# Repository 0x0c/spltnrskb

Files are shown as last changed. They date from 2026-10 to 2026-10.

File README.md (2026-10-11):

# nrsk 分割キーボード v2（基板と筐体）

KLE レイアウト（`kle/left.json`、`kle/right.json`）から生成した、左右分割・有線接続のキーボード基板です。
KiCad 10 のプロジェクト（回路図と配線済み基板）、製造用ガーバー、BOM、QMK ファームウェア設定を含みます。筐体のデータ（アクリルのレーザーカット用 DXF/SVG と 3D プリント用 STL）も入っています。

v2 では Pro Micro などのマイコンボードをやめ、RP2040 と QSPI Flash、USB-C コネクタなどを基板に直接実装しました。
マイコンボード用に設けていた内側の帯（約 20 mm）がなくなり、基板はキー領域とほぼ同じ大きさになっています。

| 項目 | 内容 |
| --- | --- |
| キー数 | 左 44 + 右 48 = 92 |
| マイコン | RP2040（QFN-56、12 MHz 水晶、I/O 3.3 V）と 16 MB の QSPI Flash W25Q128JV を左右に 1 組ずつ、裏面に直接実装 |
| USB | USB-C（USB 2.0）を左右それぞれに搭載 |
| 左右接続 | TRRS 3.5 mm（4 極ケーブル）、QMK の PIO シリアル（半二重、1 本の信号線）と 5 V 給電 |
| スイッチ | Cherry MX 互換、Kailh MX ホットスワップソケット（裏面） |
| 基板 | 2 層、左 172.6 × 126.3 mm、右 199.6 × 126.3 mm（キー配列の外周から 3 mm を基本に、上端を 6 mm、内側を左 9.4 mm・右 12.6 mm 広げて OLED・USB-C・TRRS・マイコンの場所を確保）、四隅は半径 4 mm の角丸、M2 取付穴 × 8（片側あたり）、表裏とも GND のベタ（約 5 mm 間隔のビアで表裏をつなぐ） |
| 筐体 | 左 189.6 × 143.3 mm、右 216.6 × 143.3 mm、高さ 15.6 mm（3D プリント版）／ 16.5 mm（アクリル版）、いずれもプレート上面まで |
| 外観 | プレートは透明アクリル 1.5 mm、アクリル版の枠と底板はマットクリア 3 mm。プレートは外周の切り欠きなし。USB-C と TRRS の穴はコネクタの外形ぴったり（基板の舌で差込口を外面の 0.8 mm 内側まで出している）。3D プリントのトレイは外周の角をフィレット加工（B のプレートも上面の外周に半径 1 mm の R） |
| 表示 | 0.91 インチ OLED（128×32）を左右に 1 枚ずつ、プレートと面一のハーフミラーアクリルのカバー付き。高さは増えない |
| ホイール | 左上と右上の角にサムホイール（ロータリーエンコーダー Alps EC05E1220401 で読み取り、1 回転 12 クリック）。高さは増えない |
| 3D ビューア | http://www.0x0c.me/spltnrskb/ 、組み立てガイドは http://www.0x0c.me/spltnrskb/assembly.html （GitHub Pages、`main` への Push で自動更新） |

基板の表と裏です（KiCad の 3D 表示）。裏面は裏から見た向きなので、左右が反転して見えます。

| | 左 | 右 |
| --- | --- | --- |
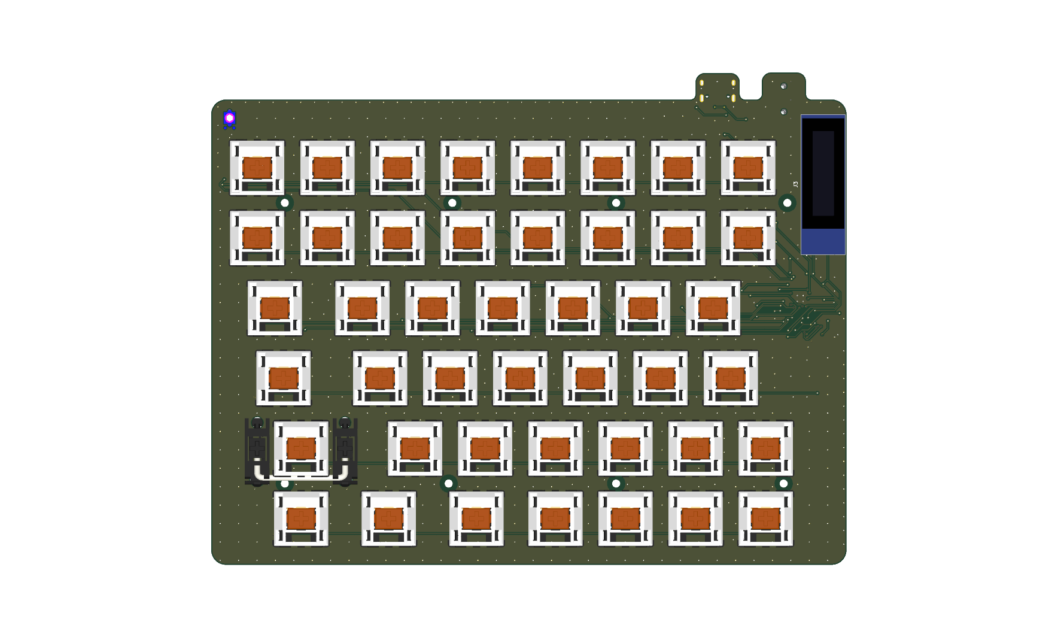
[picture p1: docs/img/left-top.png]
左基板の表
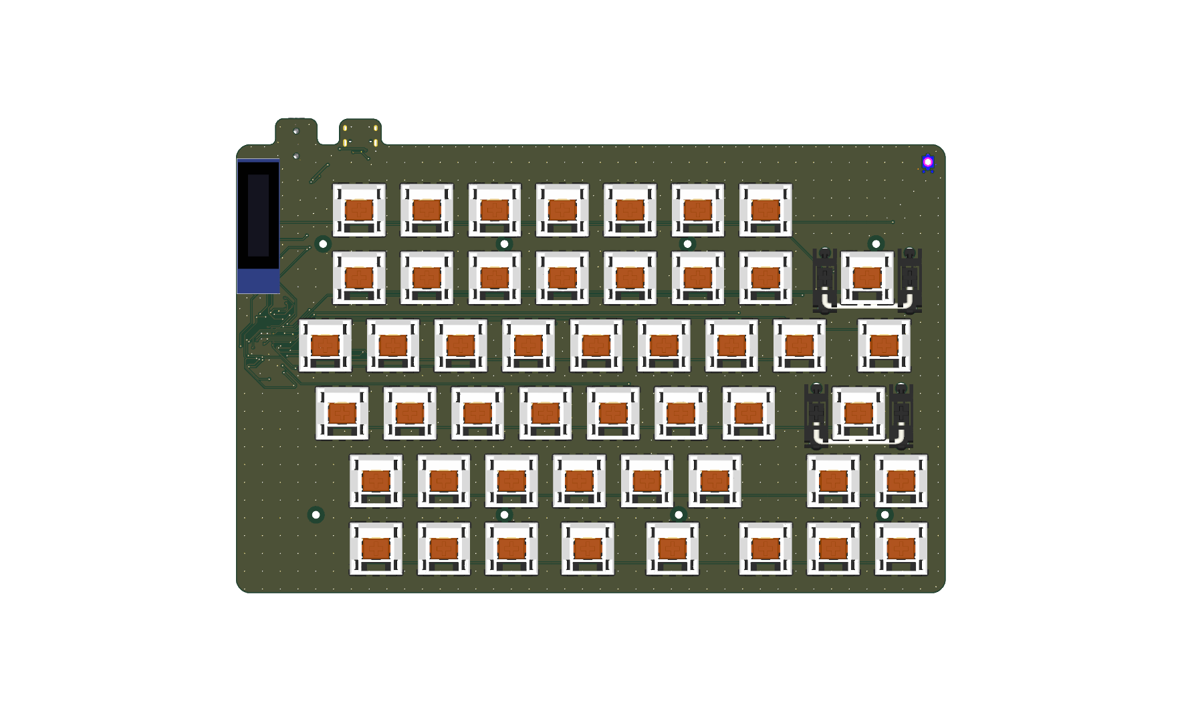
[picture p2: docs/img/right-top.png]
右基板の表
| 表 |  |  |
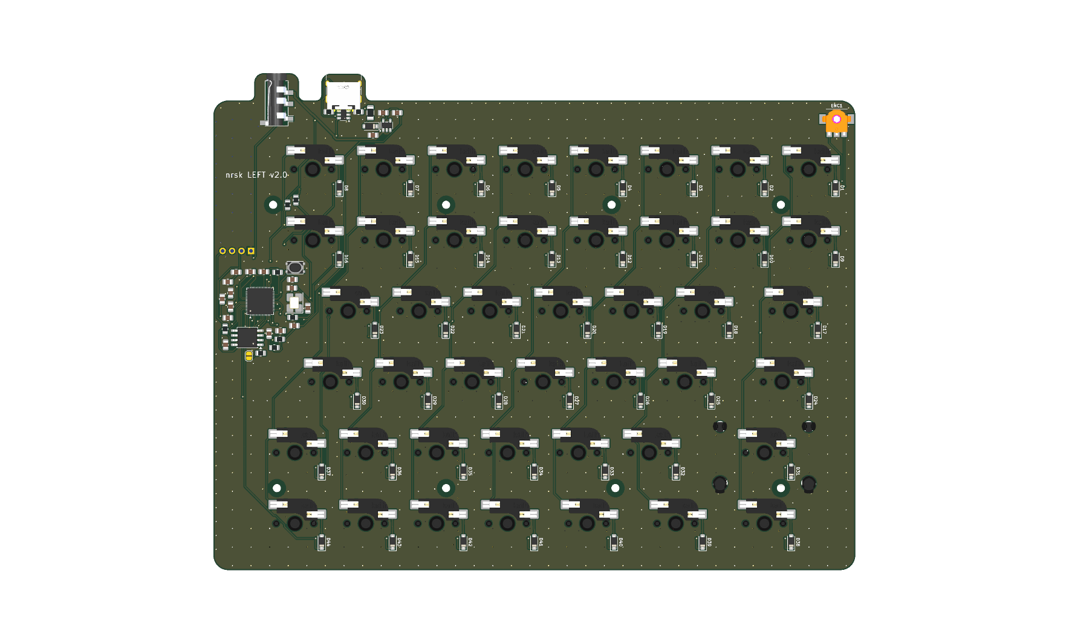
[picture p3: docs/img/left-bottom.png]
左基板の裏
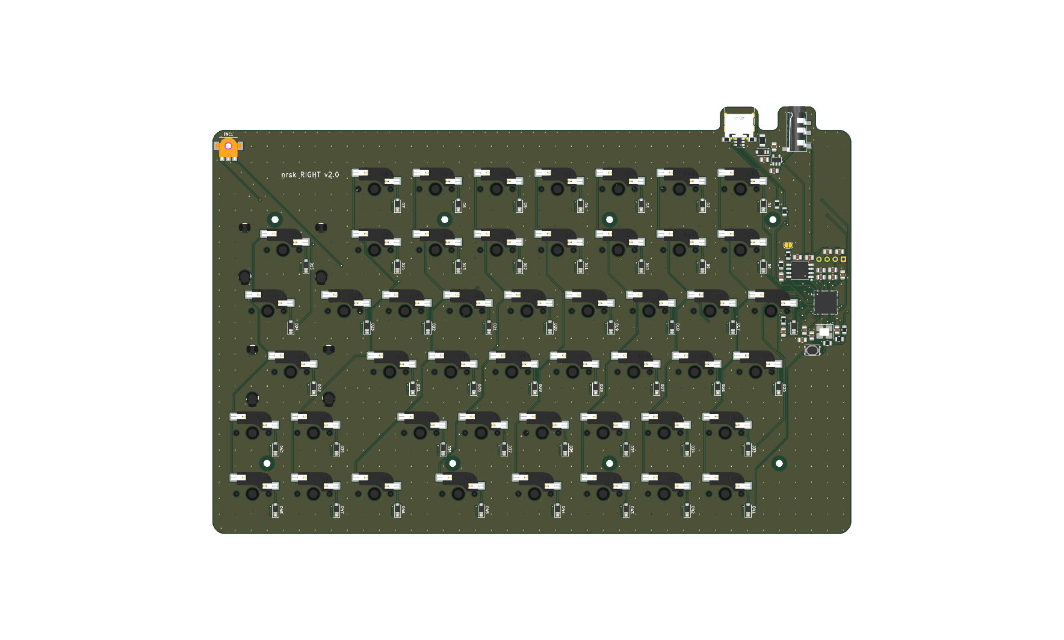
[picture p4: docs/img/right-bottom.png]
右基板の裏
| 裏 |  |  |

完成イメージ（Blender でレンダリング）です。筐体は 2 つの 3D プリント版を採用しています。左が A（3D プリントのトレイ + 透明アクリルのプレート）、右が B（プレートも 3D プリント）です。A はプレートを上からスリムヘッドの小ねじで、B は底からネジで留めます（B の上面にはネジが見えません）。

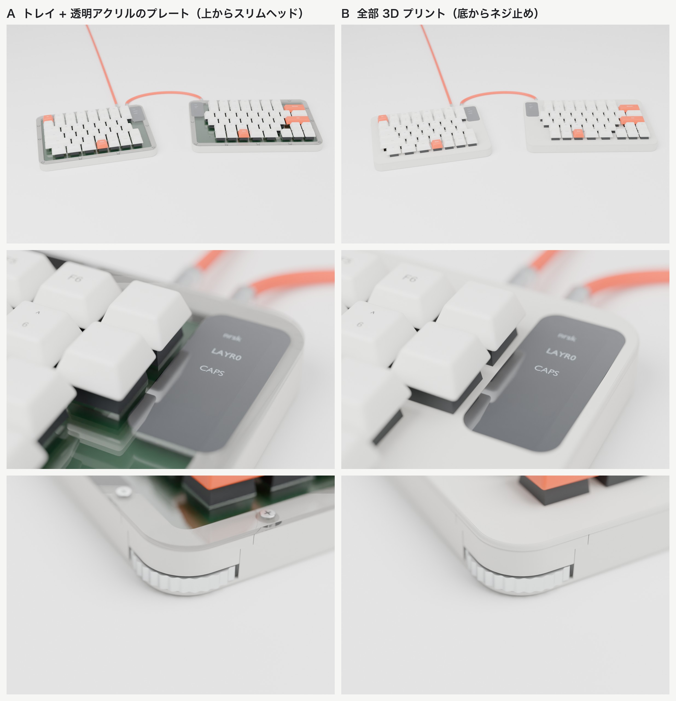
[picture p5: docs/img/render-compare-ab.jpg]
A と B の比較


## 回路

各半分に同じ回路が載っています。Raspberry Pi の RP2040 設計ガイド（Hardware design with RP2040）の最小構成に、保護部品を加えた構成です。

| 機能 | 部品 |
| --- | --- |
| QSPI Flash | W25Q128JVS（16 MB、SOIC-8 208 mil）、0.1 µF |
| クロック | 12 MHz 水晶（3225）、15 pF × 2、XOUT に 1 kΩ 直列 |
| 電源 | VCC（5 V）→ LDO AP2112K-3.3（入出力 1 µF）→ 3V3。コアの 1.1 V は RP2040 内蔵レギュレータ（VREG_VIN／VREG_VOUT に 1 µF） |
| 電源のパスコン | IOVDD × 6、DVDD × 2、USB_VDD、ADC_AVDD にそれぞれ 0.1 µF、3V3 に 10 µF |
| USB | 27 Ω × 2（D+/D−）、CC 用 5.1 kΩ × 2（USB-C のデバイス認識用）、ESD 保護 USBLC6-2SC6 |
| 電源経路 | VBUS → ポリスイッチ 500 mA → ショットキーダイオード B5819W → VCC（5 V、TRRS で反対側にも給電） |
| リセットと書き込み | RUN を 10 kΩ でプルアップしたリセットスイッチ（裏面）。BOOTSEL は QSPI_SS から 1 kΩ を通したはんだジャンパー |
| 左右判定 | GP0 を 10 kΩ で左は 3V3、右は GND に接続 |

- ショットキーダイオードは逆流を防ぎます。TRRS で給電されている側の USB-C の VBUS には電圧が出ないので、両方の USB を挿してもホスト側に電流が逆流しません。USB を挿していない側が自分をマスタだと誤判定することもありません。
- RP2040 はブートローダーを ROM に持っています。Flash が空のときは USB を挿すだけで `RPI-RP2` ドライブとして見え、UF2 ファイルをコピーすれば書き込めます。一度 QMK を書き込んだあとは、リセットスイッチを素早く 2 回押すと同じ書き込みモードに入ります。ISP 書き込み器は必要ありません。
- OLED は 3.3 V で動かします。サムホイールのエンコーダーは、A 相と B 相を RP2040 の内蔵プルアップで読み、共通端子を GND につないでいます。

### マルチプレクサは不要

片側のマトリックスは 6 行 × 8 列で、使う GPIO は 14 本です。
RP2040 の GPIO は 30 本あるので、シリアル通信 1 本、左右判定 1 本、I2C 2 本、エンコーダー 2 本を足しても十分に足ります。
右側の `\` キーは、配線上は行 0 の列 7 に割り当てて、左右とも 6 × 8 のマトリックスにそろえています（QMK の分割キーボードは左右で同じ列数を前提とするため）。

### ピン割り当て（左右共通）

| 用途 | GPIO |
| --- | --- |
| ROW0〜ROW5 | GP4〜GP9 |
| COL0〜COL7 | GP10〜GP14、GP16〜GP18（GP15 は QFN の角で配線しにくいため使わない） |
| I2C1（OLED） | SDA = GP2、SCL = GP3 |
| サムホイールのエンコーダー | A 相 = GP19、B 相 = GP20（共通端子は GND） |
| 左右間データ | GP1、TRRS の Tip |
| 左右判定 | GP0 |
| 予備 | GP15、GP21〜GP29 |

TRRS の配線は Tip = DATA、Ring2 = VCC（5 V）、Sleeve = GND で、Ring1 は未接続です。

## 配置

- 表面: スイッチだけです。スイッチプレートより上に出る部品はありません。
- 裏面: ホットスワップソケット、ダイオード、RP2040、Flash、LDO などの周辺部品、リセットスイッチ、BOOTSEL パッド、USB-C、TRRS。
- USB-C と TRRS はどちらも奥の辺（上端）に置き、ケーブルを後ろへ出します。TRRS は内側の角寄り（OLED の上）、USB-C はその 18 mm 外側です。どちらも基板の外形を幅 12 mm の舌として壁の中まで伸ばし、舌の先端へコネクタを載せています。差込口はケースの外面から 0.8 mm 内側です。舌の先端の角は半径 2.5 mm、付け根は半径 1.5 mm の R を付けてあり、基板単体で持っても角が手に刺さりません。マイコンはコネクタの下の裏面にあります。
- 基板と筐体は、左右それぞれのキー配列にぴったり合わせた大きさです（左は OLED の分だけ内側を広げています）。マイコンは裏面に置いています。
- 2 u 以上のキー（左 Shift 2.25 u、右 Backspace 2 u、右 Enter 2.25 u）には PCB マウント型スタビライザの穴があります。
- 配線ルールは信号線 0.2 mm、電源線 0.4 mm、クリアランス 0.2 mm、ビア 0.6/0.3 mm です。最小配線幅は 0.15 mm で、USB-C の細いピンに入る部分だけで使っています。JLCPCB などの標準仕様（最小 0.127 mm）で製造できます。
- マイコン周りの部品番号はシルクに収まらないため、Fab 層に入れています。半田付けには `fab/<side>/nrsk-<side>-assembly-back.pdf`（裏面の実装図、左右反転済み）を使ってください。配線の確認には `fab/<side>/nrsk-<side>-copper.pdf` を使えます（1 ページ目が表面 F.Cu、2 ページ目が裏面 B.Cu で、どちらも外形付き）。

## サムホイール（角のダイヤル）

左半分の左上、右半分の右上の角に、親指でなぞって回すサムホイールを付けています。

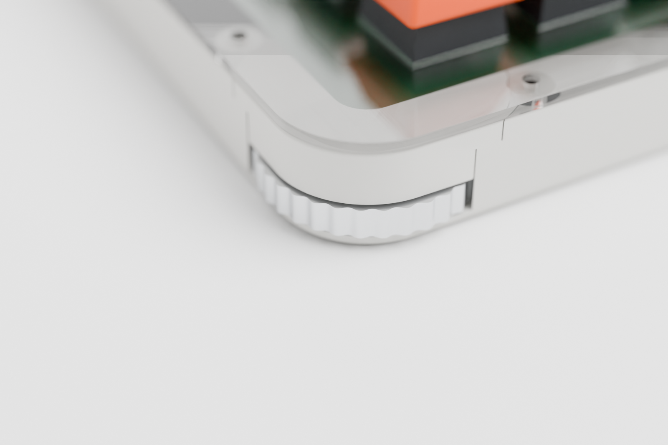
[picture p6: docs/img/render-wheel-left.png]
左のサムホイール


- 形: 直径 29.2 mm、厚さ 4.1 mm のホイールで、外周に 32 山の丸い歯（深さ 0.5 mm）があります。歯は指のすべり止めです。角の丸みと同心に置いていて、縁が角から約 3.5 mm、両側面から約 1 mm 出ます。
- 位置: 基板と底のすき間（7 mm）に水平に寝かせています。壁の下側だけを切り欠くので、プレートと壁の上部は切れ目がありません。キーボードの高さも変わりません。
- 検出: 基板裏面のホイールの中心の真上に、中空シャフトのロータリーエンコーダー Alps EC05E1220401 を下向きに付けています。ホイール上面の六角ピン（対辺 1.66 mm）が、エンコーダーの六角穴（対辺 1.72 mm）に 2 mm 入って回転部を回します。エンコーダーの下面に当たらないよう、ホイール上面の中心（半径 6 mm）を 0.4 mm 下げています。基板には、回転部の下に 3 mm 角の穴があります。
- クリック: エンコーダーが内蔵するクリックを使い、1 回転 12 クリック（30° ごと）です。1 クリックで A 相と B 相がちょうど 1 周期進むので、クリックとファームウェアの 1 ステップは部品の中で一致しています。
- 軸: 3D プリント版はトレイの床から立てた軸（直径 3.6 mm）、アクリル版は底板の下から通す M3 ネジを軸にします。ホイールの下面には軸穴（直径 4 mm × 深さ 2 mm）があります。親指で押す横向きの力はこの軸で受け、エンコーダーには回転だけを伝えます。軸と軸穴の間に半径方向で 0.2 mm 以上のすき間を設けて、基板とケースの位置ずれでホイールがこじれないようにしています。
- 組み立て: 3D プリント版で基板をトンネルへ滑り込ませるとき、エンコーダーの下面は六角ピンの先端の約 0.3 mm 上を通ります。ホイールのある角を少し持ち上げて滑らせてください。基板を下ろすときは、ホイールの縁を指で少し回すと、ピンがエンコーダーの穴に入ります。
- 左の Esc キー: エンコーダーと Esc のホットスワップソケットが重ならないよう、基板の上端を 1 mm 余分に延ばしてホイールを上へずらしています。そのため、すべてのスイッチを同じ向きで取り付けます。
- ファームウェア: QMK のエンコーダー機能で読みます。エンコーダーは基板の裏で下を向いているので、A 相と B 相のピンを入れ替えて設定し、上から見た時計回りを正の向きとして扱います。USB をつないでいない側のホイールも、QMK が左右間の通信で送ります。

| | 左ホイール | 右ホイール |
| --- | --- | --- |
| 回す（レイヤー 0） | 音量 | ページ上下 |
| 回す（レイヤー 1） | 画面の明るさ | カーソル左右 |

割り当ては `keymap.c` の `encoder_update_user()` で変更できます。

検討段階の記録として、側面ダイヤルの 2 タイプ（サムホイール型と横向きノブ型）を比べたレンダリングは [docs/img/dial-study/dial-grid.jpg](docs/img/dial-study/dial-grid.jpg) にあります。サムホイール型を採用し、角に置きました。

読み取りの方式は、当初の磁気角度センサー AS5600 と磁石、ボールプランジャーの組み合わせから、市販のロータリーエンコーダーに変えました。理由と検討した代替案は [docs/specs/thumbwheel-encoder.md](docs/specs/thumbwheel-encoder.md) に、両者の断面の比較は [docs/img/encoder-study/sheet.jpg](docs/img/encoder-study/sheet.jpg) にあります。

## OLED

左右に 0.91 インチの OLED モジュール（128×32、SSD1306、I2C）を 1 枚ずつ付けています。

- 配線: RP2040 の GP3（SCL）と GP2（SDA）に接続し、4.7 kΩ でプルアップしています。モジュールのピン順は GND / VCC / SCL / SDA です。VCC と GND が逆のモジュールもあるので、購入前に確認してください。
- 配置: 左右とも内側の端、1〜2 段目の高さに縦向きで置き、上端からの位置をそろえています。モジュールは左右とも同じ向き（ピンヘッダが下）なので、ファームウェアの表示の向きは 1 つで済みます。右はキーのない切り欠きに収まり、左は基板の内側を 4.7 mm 広げて、スイッチとの隙間を右と同じ 2.45 mm にしています。
- 取り付け: ピンヘッダの黒い樹脂スペーサーを外し、OLED のガラス上面が基板の上面から 2.5 mm の高さになるように、モジュールを基板に近づけて半田付けします。
- 筐体: OLED を中心にした角丸長方形（窓より 5 mm 大きい）のハーフミラーのアクリル（`case/laser/<side>-oled-cover`）を、プレートの切り欠きにはめ込みます。ハーフミラーのアクリルは 2 mm 厚からしか市販されていません。そこで 3D プリント版は壁の上面をカバーの下だけ 0.5 mm 下げて、上面をプレートと面一にしています（アクリル版は 0.5 mm 高くなります）。カバーは OLED のガラス面と壁の上面に透明両面テープで貼り、ネジは使いません。消灯中は鏡のように見え、点灯すると表示が透けて見えます。カバーの周りに余白を取るため、基板の上端を 5 mm 延ばし（ホイールのためにさらに 1 mm 延ばして計 6 mm）、内側を左右とも約 4.6〜4.7 mm 広げています。
- 表示: QMK の `oled_task_user` で、USB をつないだ側にレイヤーと Caps Lock、もう一方に WPM を表示します。処理は `firmware/qmk/keyboards/nrsk/keymaps/default/keymap.c` にあります。

### OLED の高さ・角度の比較

検討段階の記録です（採用したのは、上に書いたプレートと面一のハーフミラーのカバーです）。画像は当時の基板・筐体の形で描いています。
キーキャップに隠れにくい OLED の付け方を、高さ 0〜13 mm の 4 案（A〜D）と傾斜 2 案（E・F）で比べました。
座った目線と寄りのレンダリングを、取り付け方式ごとに [docs/img/render-grid.jpg](docs/img/render-grid.jpg) にまとめています。
台座の形状は `gen/oled_variants.py`、レンダリングは `gen/render_all.sh` で作り直せます。デフォルトは確認用のプレビュー（長辺 1200 px、数分）で、`FINAL=1 ./gen/render_all.sh` とすると高画質（長辺 2400 px）で出力します。
B〜F は OLED を基板の外側（壁の上）へ移すため、基板のコネクタから配線でつなぐ前提です。

## 筐体

3D プリントとアクリルのレーザーカットのどちらでも作れるよう、同じ寸法のサンドイッチ構造にしています。3D プリントのトレイを使う版は 2 種類あり、どちらも正式な仕様です。

- **A：トレイ + 透明アクリルのプレート** — トレイは 3D プリント、スイッチプレートは透明アクリル 1.5 mm（`case/laser/<side>-plate`）。プレート越しに基板が見えます。
- **B：全部 3D プリント** — プレートも 3D プリント（`case/print/<side>-plate.stl`）。スイッチの爪が掛かる周りだけ 1.5 mm で、ほかは裏に 2 mm の補強があり、上下を逆にして印刷します。中は見えません。
- **アクリル版** — 底板・枠・プレートをすべてアクリルのレーザーカットで積み重ねます。

トレイは A と B で共通です。壁の中を縦にネジ穴が通り、上面には丸いくぼみ、その下に六角のナット受けがあります。A は透明アクリルのプレートを、ナット受けに入れた M2 ナットへスリムヘッド小ねじ M2 × 6 mm（頭 φ4 × 0.5 mm）で上から留めます。B は、プレート裏のボスに入れたヒートセットインサートへ、トレイの底の座ぐりから M2 × 12 mm のなべネジで留めるので、上面にネジは見えません。アクリル版は上から M2 × 20 mm で底板の下のナットまで共締めします。
基板は 8 か所の取り付け穴で筐体の底に固定し、スイッチプレートは外周のネジで留めます。
寸法の基準は MX の規格（プレート上面から基板上面まで 5.0 mm）です。

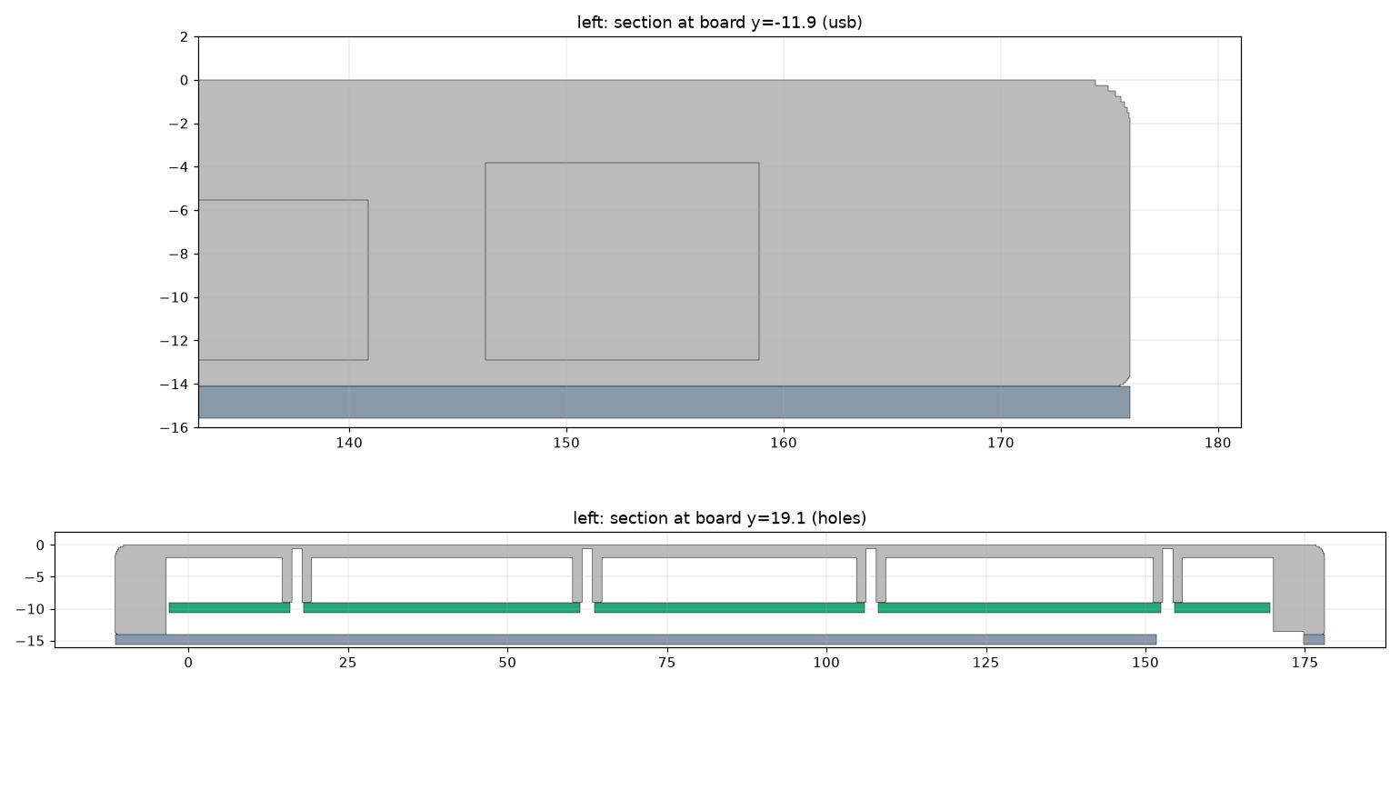
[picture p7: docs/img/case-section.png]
断面図

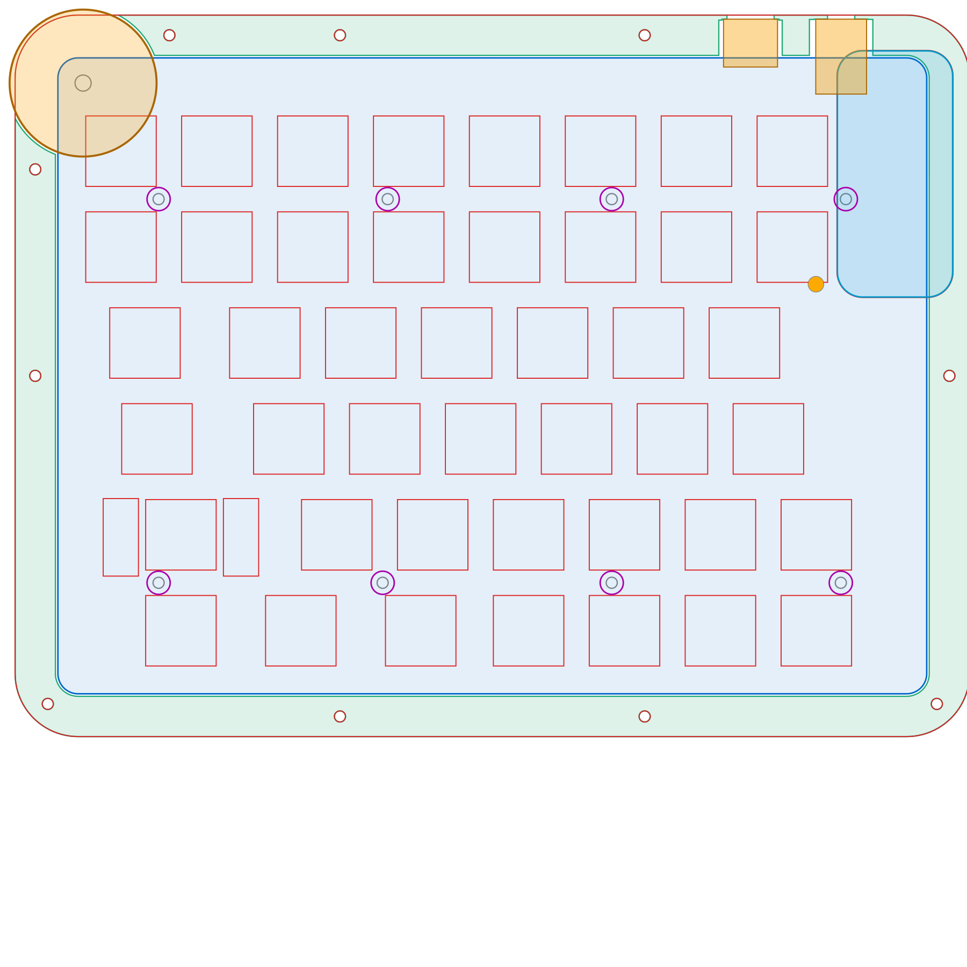
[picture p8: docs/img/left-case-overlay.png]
左の筐体と基板の重ね合わせ


| 部分 | A / B（3D プリントのトレイ、`case/print/`） | アクリル版（`case/laser/`） |
| --- | --- | --- |
| 底 | トレイの床 2 mm、外周の下端 R2・上端 R0.6 のフィレット | 底板 3 mm（`<side>-bottom`） |
| 壁 | トレイと一体、幅 8 mm、高さ 14.1 mm。ホイールの上は外せる角キャップ（`<side>-wheel-cap.stl`） | 枠 3 mm × 4 枚（差込口のある枠には切り欠き、`frame4` は切り欠きなし） |
| 基板の支持 | 床から高さ 7 mm のボス（φ4.6、下穴 φ1.6）に M2 × 6 mm タッピングネジ | M2 × 7 mm スペーサーに、上から M2 × 4 mm、下から M2 × 5 mm のネジ |
| プレート | A：透明アクリル 1.5 mm、上からスリムヘッド M2 × 6 mm でナット受けのナットへ／B：3D プリント（補強付き、裏のボスに M2 インサート）、底の座ぐりから M2 × 12 mm | 透明アクリル 1.5 mm、上から M2 × 20 mm とナットで底板まで共締め |
| ネジ本数 | 外周 左 10・右 11、基板 左右 8 ずつ | 同じ |

設計上の注意点です。

- 取り付け穴は、スペーサーやボスが裏面のパッドや配線に触れない位置へ置きました（穴の中心から銅箔まで 2.75 mm 以上）。穴の周りには配線禁止の領域を設けています。
- USB-C と TRRS は、基板の舌に載せて壁の中まで出しています。壁の外面にはコネクタの外形に 0.2 mm を足した穴（USB-C は角丸の長穴、TRRS は丸穴）だけが開き、プラグの根元はすべてケースの外に出るので、ほとんどのケーブルが使えます。アクリル版は、舌とコネクタの高さの枠に切り欠きがあります。プレートと最上段の枠は切れ目のない輪のままです。

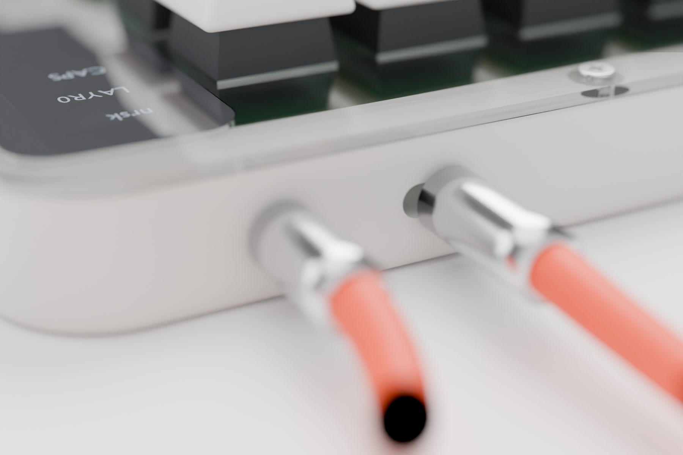
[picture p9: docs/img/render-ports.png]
USB-C と TRRS の差込口


- 3D プリント版のトレイは、差込口のまわりも分割しない一体の部品です。舌とコネクタは、奥の壁の中の上が閉じたトンネルに収まります。トンネルの高さは、舌の上に 2.3 mm の余裕があります。この余裕の分だけ基板を浮かせれば、裏面の部品がボスの上を通り抜けられます（実装済みの基板の 3D モデルで確かめた最小値は 1.5 mm）。トンネルの上には厚さ 1.2 mm の天井が残ります（OLED カバーの下のくぼみに掛かる TRRS 側の一部は 0.7 mm）。
- 基板は、手前の縁を約 2° 持ち上げて手前の壁の上端を越えさせ、ボスより 2 mm 浮かせて奥の壁に近づけます。舌を 2 つのトンネルに差し込みながら奥へ 8 mm 滑らせ、手前を下ろしてボスに載せます。下の図は、左の USB-C の中心を通る断面で、左側がケース全体、右側が差込口まわりの拡大です。

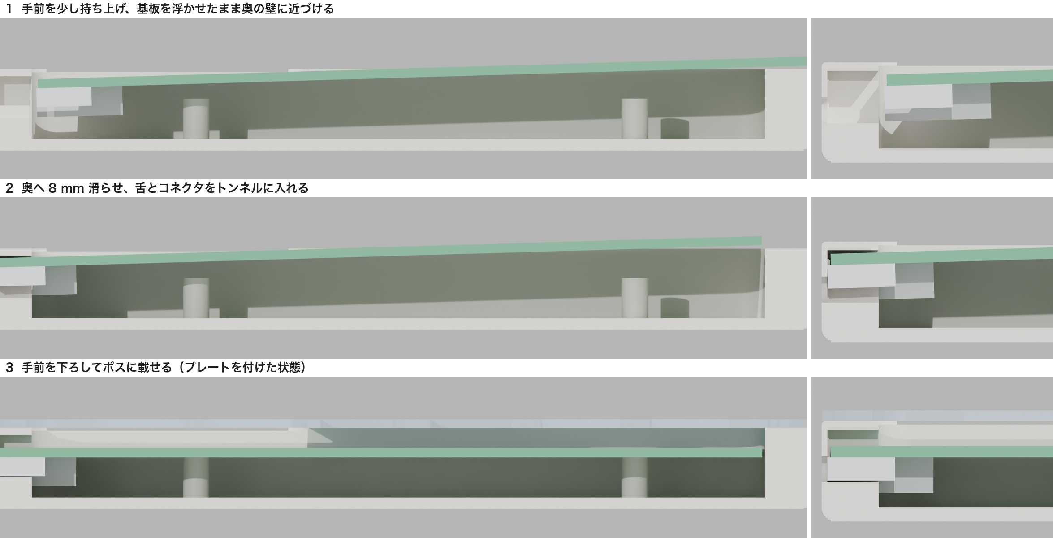
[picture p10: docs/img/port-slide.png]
基板をトンネルへ差し込む手順


- 基板を床から 7 mm 浮かせているのは、ホイールとエンコーダー、裏面の部品のためです。
- 底面には、リセットスイッチをピンで押すための φ3 mm の穴があります。
- トレイの幅は左 189.6 mm、右 216.6 mm です。右は 220 mm 角の造形範囲（Ender-3 など）にぎりぎり入る大きさなので、余裕のある 250 mm 角以上の機種（Bambu Lab A1/P1/X1、Prusa MK4 など）を勧めます。180 mm 角の機種（A1 mini など）では入りません。
- B のプレートは PETG など粘りのある材料が向いています。A のプレートと同じ DXF から、アクリルのほか FR4 1.6 mm やアルミ 1.5 mm で外注できます。
- アクリル版の枠 4 枚の合計は 12.0 mm です。設計上の理想値 12.1 mm より 0.1 mm 薄く、その分プレートがスイッチを押し下げますが、アクリル板自体の厚み公差（±0.2 mm 程度）の範囲内です。気になる場合は、スペーサーの下に薄いワッシャーを挟んでください。
- レーザーカットを外注するときは、DXF（単位 mm、全線カット）をそのまま入稿できます。スイッチ穴 14.0 mm はカット幅の補正が前提なので、補正の有無を業者に確認してください。

`case/preview/viewer.html` は組み立て状態を回して見られる 3D ビューアです。http://www.0x0c.me/spltnrskb/ で公開しています（`.github/workflows/pages.yml`）。
基板は KiCad の 3D プレビューと同じ部品実装済みの姿で表示します（`gen/export_3d.py` で KiCad から書き出し、`gen/glb_mesh.py` でブラウザ向けに軽量化）。
「分解表示」をオンにすると、スライダーでレイヤーどうしの間隔を 0〜40 mm で変えられます。

組み立て手順は、同じデータを使ったインタラクティブな組み立てガイド（`case/preview/assembly.html`、公開版は [http://www.0x0c.me/spltnrskb/assembly.html](http://www.0x0c.me/spltnrskb/assembly.html)）で確認できます。手順ごとに部品が所定の位置に入るアニメーションと説明が出て、A・B・アクリル版と左右を切り替えられます。

## 部品表（BOM）

左右合計の部品表を [bom/nrsk-bom.csv](bom/nrsk-bom.csv)（Excel で開ける UTF-8）と [bom/nrsk-bom.md](bom/nrsk-bom.md) にまとめました。
基板の電子部品、キースイッチとキーキャップ、筐体のネジ類と材料、ケーブルまで含みます。
数量は回路図と筐体のデータから自動で数えているので、レイアウトを変えても `./build.sh` で更新されます。
片側ごとの KiCad の部品表は `fab/<side>/nrsk-<side>-bom.csv` にあります。

各行には、実際に買える部品のメーカー型番・購入先・参考単価・商品ページの URL を付けています。商品ページはすべて開いて型番と仕様を確認しました（LCSC の品は 2026-10-10、ほかは 2026-10-04 時点）。
LCSC で買えるものは、すべて LCSC を最初の購入先にしています。

- **LCSC**：基板の電子部品とエンコーダー、キースイッチ、ホットスワップソケット、OLED、USB ケーブル、M2 スペーサー、一部のネジ、ヒートセットインサート。電子部品は JLCPCB の実装サービスでもそのまま使える部品番号です。ネジ類は 100 本単位などのまとめ売りです
- **LCSC にないもの**：スタビライザー、キーキャップ、TRRS ケーブル（遊舎工房など）、残りのネジとナット、ゴム足（MonotaRO）、アクリル加工（はざいや、菅原工芸）。BOM の備考に理由を書いています
- **基板**：JLCPCB

購入先は [gen/bom_sources.json](gen/bom_sources.json) にまとめてあり、価格や在庫は変わるので発注前に確認してください。

注文先ごとの手順と数量（筐体の版ごとのネジやアクリルを含む）は [docs/ordering.md](docs/ordering.md) にまとめています。

次の部品は、発注前に特に確認してください。

- **水晶振動子**：Raspberry Pi のリファレンスと同じ Abracon ABM8-272-T3（12 MHz、負荷容量 10 pF）を 15 pF のコンデンサと組み合わせます。安価な YXC X322512MSB4SI は負荷容量 20 pF なので、そのままでは合いません。
- **QSPI Flash**：W25Q128JVSIQ は LCSC に 2 つの部品番号があり、よく使われる C97521 は確認時に在庫切れでした。BOM には在庫のある C113767 を載せています。
- **TRRS ジャック**：基板のパッドは Qingpu WQP-PJ320D の寸法です。LCSC の 2 品（C431535、C95562）は EasyEDA のフットプリントと照合しました。固定ピンの間隔 7.0 mm が一致し、端子位置の差も 0.1 mm 以内でパッドに載ります。
- **ロータリーエンコーダー**：Alps EC05E1220401 は LCSC（C116648）で 1 個から買えます。ホイールの六角ピンのはめあいは印刷機によって変わるので、対辺を変えた 7 本のピンを並べた `case/print/pin-coupon.stl` を印刷して確かめてください（手順は [docs/thumbwheel-check.md](docs/thumbwheel-check.md)）。ピンの対辺は `gen/make_case.py` の `PIN_AF` で変えられます。
- **OLED**：LCSC の HS91L02W2C01 は、写真ではピン順が GND/VCC/SCL/SDA ですが、3.3 V で動くかとピンヘッダが付くかはページに書かれていません。遊舎工房の品も代替として BOM に載せています。どちらもピン順を現物で確認してください。

主な部品（左右合計）は次のとおりです。

| 部品 | 数量 |
| --- | --- |
| マイコン RP2040（QFN-56） | 2 |
| QSPI Flash W25Q128JVSIQ（16 MB） | 2 |
| 水晶振動子 12 MHz Abracon ABM8-272-T3 | 2 |
| LDO AP2112K-3.3 | 2 |
| USB-C レセプタクル HRO TYPE-C-31-M-12 | 2 |
| USB ESD 保護 USBLC6-2SC6 | 2 |
| TRRS ジャック PJ-320D | 2 |
| OLED モジュール 0.91 インチ（128×32） | 2 |
| ロータリーエンコーダー Alps EC05E1220401（サムホイール用） | 2 |
| ダイオード 1N4148W | 92 |
| MX 互換スイッチ／Kailh ホットスワップソケット | 各 92 |
| 2 u スタビライザー | 3 |
| 0805 の抵抗とコンデンサ | 抵抗 20、コンデンサ 36 |
| M2 ネジ類 | 外周 21 本、基板固定 16 か所 |

### JLCPCB での基板製造と部品実装

基板の電子部品は、すべて裏面に載っています。JLCPCB の部品実装サービスに、左右を別々の注文として出します。実装用のファイルは `gen/make_jlc.py` が作ります。

- `fab/<side>/nrsk-<side>-jlc-bom.csv`：JLCPCB の形式の部品表（`Comment`、`Designator`、`Footprint`、`LCSC Part #`）
- `fab/<side>/nrsk-<side>-jlc-cpl.csv`：部品の位置と回転（`Designator`、`Mid X`、`Mid Y`、`Layer`、`Rotation`）

実装を頼むのは 21 種類（左 83 個、右 87 個）です。OLED、ホットスワップソケット、キースイッチは手で付けます。OLED はガラスの高さを合わせて半田付けする必要があり、ソケットは表面のフットプリントに属しているので、実装ファイルから外しています。

注文の手順は次のとおりです。

1. JLCPCB の基板の注文画面で `fab/<side>/nrsk-<side>-gerber.zip` をアップロードします（2 層、厚さ 1.6 mm）。
2. 部品実装（PCB Assembly）を選び、実装面を裏面（Bottom）にします。JLCPCB の部品実装は 1 つの設計につき 2 枚からです。
3. 部品表に `nrsk-<side>-jlc-bom.csv`、配置に `nrsk-<side>-jlc-cpl.csv` を渡します。
4. 配置のプレビューで、RP2040 と Flash の 1 番ピン、ダイオードの向き、USB-C と TRRS ジャックの向き（差込口が基板の端を向く）、エンコーダーの位置を確かめます。

JLCPCB は、部品ごとに自社の部品ライブラリ（EasyEDA）のフットプリントで配置します。KiCad のフットプリントと回転や原点が違う部品は、`make_jlc.py` で補正しています。補正の値は、EasyEDA のフットプリントを基板のパッドに重ね合わせて求めました。CPL どおりに置いた EasyEDA のフットプリントでは、どの部品もすべてのパッドが同じ名前の基板のパッドに載ります（中心のずれは最大 0.46 mm で、水晶の手半田用のパッドが長いため）。USB-C だけは、実績を集めた補正表（JLCKicadTools）が 180° の補正を指定しています。しかし今の EasyEDA のフットプリントは KiCad と同じ向きなので、補正を入れていません。プレビューで差込口が基板の内側を向いていたら、`make_jlc.py` の `JLC_FIX` で USB-C の回転を 180 にしてください。

JLCPCB の部品の在庫は 2026-10-10 に確かめました（JLCPCB の部品一覧を写した非公式の検索サービス jlcsearch による）。拡張部品（Extended）は 10 種類で、種類ごとに追加料金がかかります。エンコーダー EC05E1220401 は在庫が 41 個と少ないので、注文前に確認してください。USB の 27 Ω 抵抗は、在庫が 5 個しかなかった YAGEO の品から、推奨部品の UNI-ROYAL 0805W8F270JT5E（C17594）に替えています。

## ファイル構成

入力は `kle/` のキー配列だけで、ほかのデータはすべて `gen/` のスクリプトで生成します。
`<side>` は `left` または `right` です。

```text
spltnrskb/
├── kle/                         入力：キー配列（Keyboard Layout Editor の JSON、左右 1 つずつ）
│   ├── left.json
│   └── right.json
├── left/, right/                KiCad プロジェクト（左右で同じ構成）
│   ├── nrsk-<side>.kicad_pro    プロジェクト設定（基板ルールとネットクラス）
│   ├── nrsk-<side>.kicad_sch    回路図
│   ├── nrsk-<side>.kicad_pcb    配線済みの基板
│   ├── erc.rpt, drc.rpt         ERC（回路図の検査）と DRC（基板の検査）の結果
│   ├── case_data.json           筐体の生成に渡す基板の寸法（外形、取付穴、コネクタの位置）
│   └── fp-lib-table, sym-lib-table  ライブラリの参照設定
├── lib/                         左右共通の自作ライブラリ
│   ├── nrsk.kicad_sym           回路図シンボル
│   ├── nrsk.pretty/             フットプリント（MX ホットスワップ 1u〜2.25u、OLED、エンコーダー）
│   └── nrsk.3dshapes/           OLED モジュールの 3D モデル
├── fab/<side>/                  基板の発注用データ
│   ├── nrsk-<side>-gerber.zip   ガーバーとドリル
│   ├── nrsk-<side>-bom.csv      片側の部品表
│   ├── nrsk-<side>-jlc-bom.csv  JLCPCB の部品実装用の部品表
│   ├── nrsk-<side>-jlc-cpl.csv  JLCPCB の部品実装用の配置（位置と回転）
│   ├── nrsk-<side>-schematic.pdf     回路図
│   ├── nrsk-<side>-copper.pdf        配線図（1 ページ目が表、2 ページ目が裏）
│   └── nrsk-<side>-assembly-back.pdf 裏面の実装図
├── case/                        筐体
│   ├── laser/                   アクリル版のレーザーカット用 DXF と SVG
│   │                            （<side>-plate、frame1〜4、bottom、oled-cover）
│   ├── print/                   3D プリント用 STL
│   │                            （<side>-tray、plate、wheel、wheel-cap、六角ピンの試し印刷 pin-coupon）
│   ├── preview/                 確認用の出力
│   │   ├── viewer.html          3D ビューア（GitHub Pages で公開）
│   │   ├── assembly.html        組み立てガイド（GitHub Pages で公開）
│   │   ├── model-data.js        上の 2 つが共有するメッシュデータ
│   │   ├── <side>-overlay.svg   筐体と基板の重ね合わせ図
│   │   ├── case-section.png     組み立て状態の断面図
│   │   ├── oled-variants/       OLED の高さ・角度の比較用モデル
│   │   └── port-variants/       USB-C・TRRS の開口の比較用モデル
│   └── case_report.json         筐体の寸法とネジの本数（BOM とビューアが読む）
├── bom/                         左右と筐体を合わせた部品表（CSV と Markdown）
├── firmware/qmk/keyboards/nrsk/ QMK のキーボード定義と既定のキーマップ
├── docs/specs/                  設計変更の仕様書
├── docs/ordering.md            発注の手順（注文先ごとの部品と数量）
├── docs/thumbwheel-check.md     サムホイールと OLED の実機確認の手順
├── docs/img/                    README の画像
│   ├── left-*.png, right-*.png  基板の 3D 表示と重ね合わせ図
│   ├── render-*                 Blender による完成イメージ
│   ├── port-slide.png           基板を差込口のトンネルへ入れる手順の断面図
│   ├── oled-study/              OLED の高さ・角度の比較レンダリング
│   ├── dial-study/              サムホイールの比較レンダリング
│   └── encoder-study/           サムホイールの読み取り方式の比較（AS5600 とエンコーダーの断面）
├── gen/                         生成スクリプト（下表）
├── build.sh                     一括再生成
├── .github/workflows/pages.yml  3D ビューアと組み立てガイドを GitHub Pages へ公開
└── tools/, .venv/               Freerouting、取得した 3D モデル、Python 仮想環境（Git の管理対象外）
```

`gen/` のスクリプトは、`build.sh` が次の順に呼び出します。

| 段階 | スクリプト | 生成するもの |
| --- | --- | --- |
| 部品ライブラリ | `fetch_3d.sh`、`models3d.py`、`footprints.py` | 3D モデルの取得、OLED の 3D モデル、`lib/nrsk.pretty` |
| 回路図 | `layout.py`、`make_sch.py`、`make_pro.py` | KLE の解析とピン割り当て、回路図、プロジェクト設定 |
| 基板 | `make_pcb.py`、`route.py`、`sexpr.py` | 部品の配置、Freerouting による自動配線、KiCad ファイルの読み書き |
| 3D 出力 | `export_3d.py`、`glb_mesh.py` | ビューア用の基板メッシュ（`build/3d/`、Git の管理対象外） |
| ファームウェア | `make_qmk.py` | `firmware/qmk/keyboards/nrsk/` |
| 筐体 | `make_case.py`、`case_preview.py`、`case_section.py`、`case_viewer.py`、`assembly_guide.py` | `case/` 以下のすべて |
| 部品表 | `make_bom.py`、`bom_sources.json` | `bom/`（購入先の情報は `bom_sources.json` に手で記入） |
| JLCPCB の実装データ | `make_jlc.py` | `fab/<side>/nrsk-<side>-jlc-bom.csv`、`fab/<side>/nrsk-<side>-jlc-cpl.csv` |
| README の画像 | `doc_images.sh` | `docs/img/left-*.png`、`docs/img/right-*.png`、断面図 |

次のスクリプトは `build.sh` に含まれず、必要なときに手で実行します。

- 完成イメージのレンダリング：`render_blender.py`、`render_all.sh`、`render_grid.py`
- A と B の比較画像、差込口、基板の差し込み手順の断面図：`render_compare.sh`、`compare_ab.py`、`port_slide.py`
- OLED と開口の比較検討：`oled_variants.py`、`oled_study.sh`、`oled_sheet.py`、`port_variants.py`
- 六角ピンの試し印刷：`pin_coupon.py`（`case/print/pin-coupon.stl`。使い方は [docs/thumbwheel-check.md](docs/thumbwheel-check.md)）

KLE を編集した場合は `./build.sh` を実行すると、回路図、基板、配線、ERC/DRC、製造データ、筐体、BOM、QMK 定義をすべて作り直します。
行の配線とダイオード周りはスクリプトで規則的に引き、残りを Freerouting（`tools/freerouting-2.4.1.jar`）に任せています。
Freerouting の結果には乱数によるばらつきがあるため、未配線が 0 になるまで最大 25 回やり直します。
配線のあと、表裏に GND のベタを敷き、約 5 mm 間隔のビアで表裏をつなぎます（`route.py` の `pour()`）。配線で囲まれた細い部分にもビアを足し、それでもつながらない銅は取り除きます。SMD のパッドはベタにそのままつなぎ、手で半田付けするスルーホールのパッドだけ、熱が逃げにくいよう細い線でつなぎます。

## 環境の準備

`./build.sh` で全データを作り直すには、次のツールが必要です（macOS で確認）。

- KiCad 10（`~/Applications/KiCad` または `/Applications/KiCad`）
- OpenJDK と Freerouting 2.4.1
- 筐体の生成用に Python 3 の仮想環境と manifold3d
- 完成イメージのレンダリング用に Blender（任意）

```bash
brew install openjdk
```

```bash
mkdir -p tools && curl -L -o tools/freerouting-2.4.1.jar https://github.com/freerouting/freerouting/releases/download/v2.4.1/freerouting-2.4.1.jar
```

```bash
python3 -m venv .venv && .venv/bin/pip install manifold3d numpy matplotlib
```

KiCad の標準ライブラリにない 3D モデルは、`./build.sh` の冒頭で `gen/fetch_3d.sh` が `tools/` へ取ってきます（Git の管理対象外です）。

- MX スイッチ、Kailh ホットスワップソケット、スタビライザー：[kiswitch](https://github.com/kiswitch/kiswitch)（CC-BY-SA 4.0、設計データへの利用は例外規定あり）
- USB-C（C165948）と TRRS ジャック（C431535）：LCSC／EasyEDA のモデルを [easyeda2kicad](https://pypi.org/project/easyeda2kicad/) で取得
- OLED モジュール：`gen/models3d.py` で作る簡易モデル（`lib/nrsk.3dshapes/`）
- サムホイールのエンコーダー（EC05E1220401）：Alps Alpine の製品ページの STEP（`tools/alps/`）

これがあれば KiCad の 3D ビューアでも、すべての部品が実装された状態で表示されます。

```bash
blender -b -P gen/render_blender.py -- --samples 192 --res 1800
```

## ファームウェア

ファームウェアは QMK で作ります。キーボード定義は `firmware/qmk/keyboards/nrsk` にあります。
左右とも同じファームウェアを書き込みます。左右の判定は基板の配線（GP0）で決まるので、左用・右用を分ける必要はありません。

### 1. QMK の準備（初回のみ）

```bash
brew install qmk/qmk/qmk
```

```bash
qmk setup
```

`qmk setup` は `~/qmk_firmware` に QMK を取得し、ビルドに使う ARM のコンパイラなどもまとめて入れます。
Windows では [QMK MSYS](https://msys.qmk.fm/) を使ってください。
Homebrew の `arm-none-eabi-gcc` は標準 C ライブラリ（newlib）を含まないためビルドできません。`qmk setup` が入れるツールチェインか、Arm 公式の [Arm GNU Toolchain](https://developer.arm.com/downloads/-/arm-gnu-toolchain-downloads)（arm-none-eabi）を使ってください。

### 2. キーボード定義をコピーしてビルドする

```bash
cp -R firmware/qmk/keyboards/nrsk ~/qmk_firmware/keyboards/
```

```bash
qmk compile -kb nrsk -km default
```

ビルドが通ると `~/qmk_firmware/nrsk_default.uf2` ができます。

### 3. 書き込む（左右それぞれ 1 回ずつ）

RP2040 は ROM に USB ブートローダーを持っています。専用の書き込み器やドライバは要りません。

1. TRRS ケーブルを外し、書き込む側の半分だけを USB でPCにつなぎます。
2. その半分を書き込みモードにします。PCに `RPI-RP2` という USB ドライブが現れれば成功です。
   - 初めて書き込むとき（Flash が空）は、USB を挿すだけで書き込みモードになります。
   - 2 回目以降は、底面の穴からリセットスイッチをピンで素早く 2 回押します。
   - 一番左上のキーを押したまま USB ケーブルを挿しても入れます（Bootmagic）。左半分は Esc、右半分は F7 の左にある刻印なしのキーです。
   - どれも効かないときは、裏面の BOOTSEL パッド（JP1）をピンセットで短絡したまま USB を挿します。
3. `nrsk_default.uf2` を `RPI-RP2` ドライブにコピーします。コピーが終わると自動で再起動し、キーボードとして認識されます。コマンドで書き込む場合は次のとおりです（書き込みモードになるのを待ってから書き込みます）。

   ```bash
   qmk flash -kb nrsk -km default
   ```

4. もう片方も同じ手順で書き込みます。
5. 最後に TRRS ケーブルで左右をつなぎ、どちらか片方を USB でPCにつなぎます。USB をつないだ側がマスタになり、その側の OLED にレイヤーと Caps Lock、もう一方に WPM が表示されます。

### うまくいかないとき

- `RPI-RP2` ドライブが出ない場合は、USB ケーブルが充電専用でないか確認し、BOOTSEL パッドを短絡したまま挿し直してください。それでも出ない場合は、水晶、Flash、3.3 V LDO の半田付けを確認してください。
- 左右が通信しない場合は、TRRS ケーブルが 4 極（TRRS）であることを確認してください。
- TRRS ケーブルは、USB をつないだまま抜き差ししないでください。

### キーマップ

デフォルトのキーマップは KLE の刻印どおりで、`fn` を押している間はレイヤー 1 になります（矢印キーが Home/End/PgUp/PgDn、Backspace が Delete）。
KLE で刻印のないキー（左右の内側の列、計 12 キー）は `KC_NO` にしてあるので、好みに合わせて割り当ててください。
キーマップを変えるには、`firmware/qmk/keyboards/nrsk/keymaps/default/keymap.c` を編集します。自分用のフォルダ（例: `keymaps/mine/`）を作り、`qmk compile -kb nrsk -km mine` でビルドしてもかまいません。

## 発注・組み立て前の確認事項

- DRC の警告は片側 5 件です。どれも、TRRS ジャックと USB-C の差込口が基板端に掛かっていることによるシルクの警告で、差込口を基板の端に合わせるための意図的な配置です。動作には影響しません。
- RP2040 は 0.4 mm ピッチの QFN で、裏面のサーマルパッドも GND に半田付けする必要があります。手半田はホットエアかリフローが前提なので、JLCPCB などの部品実装サービスを使うのがおすすめです（BOM の LCSC 部品番号がそのまま使えます）。USB-C（0.5 mm ピッチ）も同様です。
- ホットスワップソケットのフットプリントは、一般的な Kailh CPG151101S11 の寸法で作った自作品です。1 枚目は実物のソケットと照合してください。
- TRRS ケーブルは、USB を接続したまま抜き差ししないでください。電源ピンが一瞬ショートして、マイコンを壊すおそれがあります。
- QMK のファームウェアは、現行の qmk_firmware（2026-10 時点）で `qmk compile -kb nrsk -km default` が通ることを確認しています。出力は `nrsk_default.uf2`（約 84 KB）です。実機での動作（キー入力、左右通信、OLED、ホイール）はまだ確認していません。

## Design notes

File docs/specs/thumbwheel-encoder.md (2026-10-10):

# サムホイールの市販ロータリーエンコーダー化

> ステータス: 実装完了（ステップ 10 の実機での確認は未実施）
> 対象: `gen/`（回路図、基板、ケース、QMK の各生成スクリプト）、`firmware/qmk/keyboards/nrsk/`、`README.md`
> 関連: [README のサムホイールの節](../../README.md#サムホイール角のダイヤル)

角のサムホイールの読み取りを、磁気角度センサー AS5600 と磁石とボールプランジャーの組み合わせから、市販のロータリーエンコーダー Alps EC05E1220401 に置き換える。エンコーダーは基板の裏へ下向きに付け、ホイール上面の六角ピンで回す。クリックはエンコーダーが内蔵するものを使い、ファームウェアは QMK 標準のエンコーダー機能で読む。

## 1. なにをつくるのか

### 完成後の振る舞い

ホイールの位置、直径 29.2 mm、厚さ 4.1 mm、角から縁が出る量は今と変わらない。外から見て変わるのは手触りだけである。

- **クリック数**：1 回転 12 クリックになる（今は 32）。1 クリックは 30° で、縁の上で約 7.6 mm にあたる。
- **クリックの重さ**：エンコーダーのクリックトルクは 1.6 ± 1.3 mN·m である。ホイールの縁（半径 14.6 mm）で約 0.11 N、ばらつきの範囲で 0.02〜0.2 N になる。今のボールプランジャーと違い、重さは調整できない。
- **キー割り当て**：今と同じ。左ホイールは音量（レイヤー 1 で画面の明るさ）、右ホイールはページ上下（レイヤー 1 でカーソル左右）を送る。1 クリックで 1 回送るので、1 回転あたりの変化量は今の 12/32 になる。
- **左右**：USB をつないでいない側のホイールも、今と同じように効く。

外観、断面、分解図は [docs/img/encoder-study/sheet.jpg](../img/encoder-study/sheet.jpg) にある。

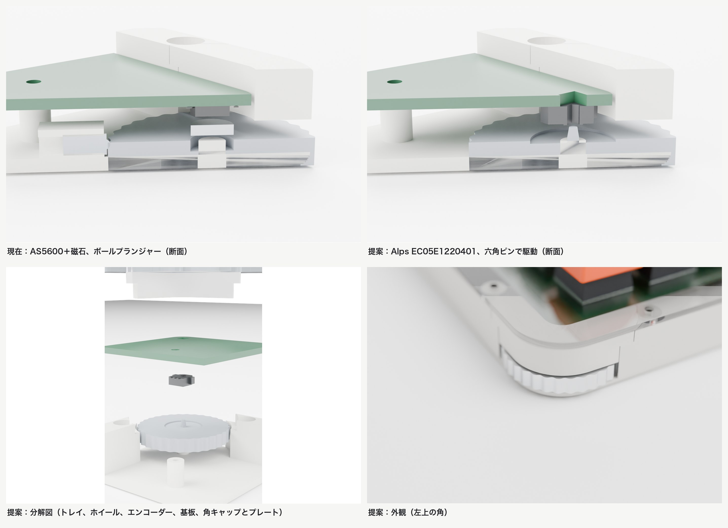
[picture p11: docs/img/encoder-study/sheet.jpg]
現在の構成と提案の構成の比較


### 部品の購入先

BOM の購入先を、買えるものはすべて LCSC にそろえる。LCSC で扱っていないもの（キーキャップ、アクリル板、3D プリント部品）は、LCSC にないことを BOM に明記し、今の購入先を残す。基板は今どおり JLCPCB に発注する。

### やらないこと

- **ホイールの直径と位置の変更**：直径を変えると、クリックの重さを縁で感じる力は変えられる。ただし、角の切り欠き、ケースのネジ、スタンドオフの配置を作り直す必要があり、今回の目的（読み取り方式の置き換え）から外れる。実機でクリックが軽すぎた場合に、別件として扱う。
- **押し込みスイッチ**：EC05E1220401 には押し込みスイッチがない。押し込み付きの候補（Panasonic EVQWK 系）は製造終了している。
- **キー割り当ての変更**：1 回転のクリック数が減るぶん、音量の 1 回転あたりの変化は小さくなる。割り当ては実機で使ってから見直す。
- **AS5600 方式の改善**：前回の検討で挙げた修正（ヒステリシスの拡大、磁石検出の確認）は、AS5600 をなくすので行わない。

## 2. なぜつくるのか

今の設計は、部品の入手と読み取りの確実さの両方に問題を抱えている。

まず、磁石が手に入らない。設計は直径 6 mm、厚さ 1.5 mm の径方向着磁の磁石を前提にしているが、国内で在庫のある品は見つからず、BOM には厚さ 2.5 mm の品を載せている。厚さ 2.5 mm の磁石はホイールのポケット（深さ 1.6 mm）に入らない。ポケットを深くする方法もない。ホイールの厚さは 4.1 mm で、下から深さ 2.0 mm の軸穴があるため、ポケットは 2.1 mm までしか取れないからだ。はみ出したまま組むと、磁石の上面とセンサーのすき間は約 0.05 mm になり、ほぼ接触する。

次に、クリックとステップの対応をファームウェアが推測している。`nrsk.c` は起動時の角度を基準に相対角度を積算し、32 等分した区切りでステップを数える（`firmware/qmk/keyboards/nrsk/nrsk.c:24`）。機械のクリック位置と区切りを合わせ直す処理がないので、センサーの非直線性や磁石の中心ずれがあると区切りがずれていく。数え始めるしきい値は山の頂点から約 1°（12 カウント）しか離れていない。このため、山を越えずに戻しただけで「+1 してすぐ −1」と数えるおそれがある。磁石が外れると角度の値はノイズになり、ステップが勝手に出る。この場合への備えもない。

市販のエンコーダーは、クリック位置と A 相、B 相の信号の切り替わりが部品の中で合わせてある。クリック 1 つで信号がちょうど 1 周期進むので、ファームウェアは区切りを推測する必要がない。QMK はこの種のエンコーダーを標準で読める。左右の分割キーボードでも、もう片方のエンコーダーの値を QMK が自分で転送する。その結果、`nrsk.c` の自作の読み取りと、左右間の独自の通信（RPC）が不要になる。

放置すると、組み立ての段階で磁石が入らずに止まる。磁石を入手できたとしても、実機で誤カウントが出たときに、機械と磁気とファームウェアのどこが原因かを切り分ける手間が残る。

## 3. どう実現するか

### 部品

Alps EC05E1220401 の仕様は、Alps のカタログ（Drawing No.3）と製品ページから取った。

| 項目 | 値 |
| --- | --- |
| 形式 | 中空シャフト形、基板に表面実装、軸は基板に垂直 |
| クリック数とパルス数 | 1 回転 12 クリック、12 パルス、A 相と B 相の 2 相出力 |
| クリックトルク | 1.6 ± 1.3 mN·m |
| 寿命 | 10 万回 |
| 定格 | 5.5 V DC、0.55 mA |
| 本体 | 幅 5.7 mm（側面の金具を含めて 7.6 mm）、回転軸から上へ 2.5 mm、下へ 3.7 mm |
| 実装面からの高さ | 2.7 mm |
| シャフト穴 | 六角、対辺 1.72 mm（基板側の面）と 1.73 mm（反対の面）、長さ 2.7 mm。基板と反対の面から差し込む |
| 基板の加工 | 回転部の下に 3 mm 角の穴（角に R0.5 の逃げ）、位置決め用の直径 0.62 mm の穴 2 つ |
| ランド | 側面の金具用に 1.7 × 2.6 mm を 2 つ（内側の間隔 5.9 mm）、端子 A、C、B 用に 1.5 × 1.3 mm を 2.0 mm 間隔で 3 つ |

メーカーの最小発注数は 8,000 個だが、element14（Farnell）は 1 個から扱っている。発注前に在庫を確認する。

### 高さの配分

3D プリント版の床の上面を 0 とした高さで示す。アクリル版は底板の上面を 0 とすれば同じ値になる。

| 部分 | 今 | 提案 |
| --- | --- | --- |
| 基板の裏 | 7.0 | 7.0 |
| エンコーダーの下面（シャフト穴の入口） | なし | 4.3 |
| ホイール上面（縁） | 4.4 | 4.4 |
| ホイール上面（中心のくぼみ） | なし | 4.0（半径 6.0 mm、深さ 0.4 mm） |
| 六角ピンの先端 | なし | 6.3（くぼみから 2.3 mm、シャフトに 2.0 mm 入る） |
| ホイール下面 | 0.3 | 0.3 |

ホイール上面の縁（4.4）はエンコーダーの下面（4.3）より高いが、エンコーダーはくぼみの範囲（半径 6.0 mm）に収まるので当たらない。くぼみの半径は、本体の角、側面の金具、端子のうちもっとも遠い点（回転軸から約 5.3 mm）に余裕を加えて決めた。

### 軸の支え方と駆動

親指で押す横向きの力は、今と同じ床の軸で受ける。3D プリント版はトレイの床から立てた軸、アクリル版は底板の下から通す M3 ネジである。エンコーダーには回転だけを伝える。

床の軸とエンコーダーの 2 か所でホイールを拘束すると、基板とトレイの位置ずれでホイールがこじれる。基板は M2 ネジ（穴径 2.2 mm）で留めるので約 ±0.1 mm 動き、トレイの印刷誤差も同じ程度ある。合わせて最大 0.2 mm ほどずれる見込みである。そこで、3D プリント版の床の軸を直径 3.8 mm から 3.6 mm に細くし、ホイールの軸穴（直径 4.0 mm）との間に半径方向で 0.2 mm のすき間を設ける。アクリル版の M3 ネジは、もともと半径方向に 0.5 mm のすき間がある。

六角ピンは対辺 1.66 mm とし、シャフト穴（1.72 mm）とのすき間を 0.06 mm にする。すき間のぶん、回転方向に ±1〜2° ほどのガタが出る（概算）。対辺の寸法は、試し印刷でガタとはめやすさを見て決める。ピンの先端は 0.25 mm 面取りして、差し込みやすくする。ピンにかかるトルクは最大でクリックトルクの上限 2.9 mN·m である。対辺 1.66 mm の PETG のピンでは、せん断応力が約 3 MPa にとどまり、材料の強度（数十 MPa）に対して十分小さい。

3D プリント版では、基板を奥へ滑らせてトンネルに差し込むとき、基板はボスより最大 2 mm 浮いている。このときエンコーダーの下面は六角ピンの先端のすぐ上を通り、ホイールが床に着いた状態でのすき間は約 0.3 mm しかない。トンネルは基板の反対側の端にあるので、ホイールのある角だけを少し持ち上げればすき間は広がる。差し込み長さを縮めて余裕を作る案もあるが、六角穴に掛かる長さが減るので採らず、組み立てガイドで注意する。基板を下ろすときは、ホイールの縁を指で回して六角ピンと穴の向きを合わせる。

ホイールの外周の 32 山の歯は、すべり止めとして残す。クリックの役目はなくなるので、歯の数はクリック数（12）と切り離した定数にする。

### 回路と基板

| 変更 | 内容 |
| --- | --- |
| 削除 | U3（AS5600）、C9（1 µF）、C10（0.1 µF）、カスタムシンボル `nrsk:AS5600` |
| 追加 | エンコーダー 1 個（KiCad 標準のシンボル `Device:RotaryEncoder`、端子 A、C、B） |
| 配線 | A を GP19、B を GP20、C を GND。プルアップは RP2040 の内蔵抵抗を使う |
| フットプリント | `nrsk:Alps_EC05E1220401` を `gen/footprints.py` で生成する。ランド、位置決め穴（NPTH）、3 mm 角の穴（Edge.Cuts）を含む |
| 配置 | 基板の裏、ホイールの中心（今の U3 の位置。`gen/make_pcb.py:505`）。端子は配線しやすい向きに置く |
| 3D モデル | Alps 提供の STEP を `gen/fetch_3d.sh` で `tools/` に取得する。配布条件が明記されていないので、リポジトリには入れない |

GP19 と GP20 は今どこにも使っていない（`gen/layout.py:9` から `gen/layout.py:13`）。I2C（GP2、GP3）は OLED が使い続けるので残す。

左の Esc キーは、今は AS5600 とホットスワップソケットが重ならないよう 180 度回している（`gen/make_pcb.py:457`）。エンコーダーは AS5600 より大きく、基板に穴も開く。キーを回す条件は、エンコーダーの外形と穴に対して判定し直す。実装後の追記：判定し直すと、Esc のソケットはエンコーダーに 0.43 mm 重なった。その後、基板の上端を 1 mm 延ばしてホイールを上へずらし、回すキーをなくした。

### ファームウェア

`gen/make_qmk.py` が生成する内容を、次のように変える。

| ファイル | 変更 |
| --- | --- |
| `keyboard.json` | `features` に `"encoder": true` を加える。`"encoder": {"rotary": [{"pin_a": "GP20", "pin_b": "GP19"}]}` を加え、右半分にも `"split": {"encoder": {"right": {"rotary": [...]}}}` で同じピンを書く |
| `config.h` | `DIAL_*` と `SPLIT_TRANSACTION_IDS_KB` を消す。OLED 用の I2C の設定は残す |
| `nrsk.c`、`nrsk.h` | AS5600 の読み取り、`dial_update_user()`、RPC の処理を消す。キーボード固有の処理が残らなければ、ファイルごと消す |
| `keymap.c` | `dial_update_user()` を `encoder_update_user(uint8_t index, bool clockwise)` に置き換える。中身の割り当ては変えない |

エンコーダーは基板の裏で下を向くので、上から見た時計回りは、部品の向きで見ると反時計回りになる。`pin_a` と `pin_b` を入れ替えて書くのは、この反転を打ち消すためである。実機で逆に回ったときは、2 つを入れ替える。`resolution` は QMK のデフォルト値 4 を使う。1 クリックで A 相と B 相が 1 周期進み、状態が 4 回変わるからである。

### 部品の購入先

`gen/bom_sources.json` の各部品の先頭の購入先を LCSC の製品にする。LCSC の製品ページを開き、型番、仕様、最小単位の価格、在庫を確かめたものだけを載せる。最小発注数が個数より多いもの（ネジの 100 本入りなど）は、その単位を価格欄に書く。LCSC に仕様を満たす品がない部品は、今の購入先を先頭に残し、備考に「LCSC に該当品なし」と書く。今の購入先は、仕様が LCSC の品と違う場合に限り代替として残す。

### ケース

`gen/make_case.py` を次のように変える。

- ホイール（`Half.wheel3d`）：磁石のポケットを消す。上面の中心にくぼみ（半径 6.0 mm、深さ 0.4 mm）を作り、六角ピンを立てる。
- 3D プリント版のトレイ：床の軸を直径 3.6 mm にする。プランジャーブロックを消す。
- アクリル版：別に印刷するプランジャーブロック（`case/print/<side>-detent.stl`）と、それを留める M2 ネジ 2 本と底板の穴を消す。
- 定数：`BLOCK_*`、`PLUNGER_*`、`MAGNET_*` を消す。くぼみ、ピン、エンコーダーの寸法を定数として加える。
- 検査（`check()`）：プランジャーの検査を消す。ホイールとエンコーダーが当たらないこと、ピンがシャフト穴に 2.0 mm 入ることを検査に加える。

寸法の検証は、検討用のスクリプト `gen/encoder_study.py` で済ませてある。同じスクリプトが、ホイールとエンコーダーの体積の重なりがないことを確かめている。

## 4. 検討した代替案と、採らなかった理由

| 案 | 概要 | 採らなかった理由 |
| --- | --- | --- |
| AS5600 方式のまま直す | 直径 6 mm、厚さ 1.5 mm の磁石を海外から取り寄せ、ヒステリシスの拡大と磁石検出をファームウェアに足す | 部品の入手が不確かなまま残る。クリック位置をファームウェアが推測する構造は変わらず、ずれへの余裕を増やすことしかできない |
| フォトリフレクタ 2 個 | ホイール上面の白黒の縞を 2 個の反射型センサーで読み、直交信号を作る | ホイールの縁が角から外に出ているため外の光が入り、対策（LED の点滅と差分の読み取り）が要る。縞の汚れにも弱い。ボールプランジャーも残る |
| Panasonic EVQWK 系 | 基板の端から縁が出るジョグダイヤル。15 クリック、押し込み付き | 製造終了 |
| Panasonic EVQWGD001 | ローラー型のエンコーダー | 製造終了。ホイールを縦に置く形になる |
| Alps EC05E1220202 | 同じ系列の、軸が基板と平行な品。LCSC に在庫がある | ホイールを縦置きにする必要があり、角で寝かせて縁をなぞる今の操作感が変わる |
| EC11 などの一般的なエンコーダー | つまみ用の定番品 | 本体だけで高さが約 6.5 mm あり、基板の裏と床のすき間（7 mm）にホイールと一緒には収まらない |
| エンコーダーだけでホイールを支える | 床の軸をなくし、ホイールをエンコーダーの回転部にぶら下げる | こじれは起きないが、親指の横向きの力がすべてエンコーダーにかかる。横向きの許容荷重は寸法図に載っていない |
| 金属の六角軸を貫通させる | 床から基板の穴まで六角の金属棒を通す | 軸はまっすぐになるが、対辺 1.72 mm に合う市販の六角棒が見当たらず、加工が要る |
| クリックなしのエンコーダーとプランジャー | クリックはプランジャーに任せ、エンコーダーは信号だけを出す | 部品の点数が減らない。パルス数と歯の数の比が整数でないと、クリックとステップがずれる |

実機でクリックが軽すぎた場合は、ホイールの直径を小さくする案（やらないことの 1 つ目）を検討する。ボールプランジャーを戻す案は、エンコーダーのクリックと位相を合わせる必要があるので採らない。

## 5. 作業手順

各ステップは 1 コミットにまとめる。生成物（回路図、基板、STL、ファームウェア）は、生成スクリプトと同じコミットで再生成する。

| # | 状態 | やること | 触るファイル | 完了条件 | 前提 |
| --- | --- | --- | --- | --- | --- |
| 1 | 済 | エンコーダーのフットプリントを追加し、3D モデルの取得を足す | `gen/footprints.py`、`gen/fetch_3d.sh`、`lib/nrsk.pretty/` | KiCad のフットプリントエディタで開き、Alps の寸法図とランド、穴、外形が一致する。3D ビューアで STEP の端子がランドに載る | なし |
| 2 | 済 | 回路図の AS5600 と C9、C10 をエンコーダーに置き換え、GP19、GP20 につなぐ | `gen/make_sch.py`、`gen/layout.py`、`lib/nrsk.kicad_sym`、`left/`、`right/` の回路図 | 左右とも ERC のエラーが 0 件 | 1 |
| 3 | 済 | 基板にエンコーダーを配置し、キーを回す条件を見直して配線する | `gen/make_pcb.py`、`left/`、`right/` の基板、`fab/` | `./build.sh` で左右とも未配線 0、DRC のエラー 0。3 mm 角の穴がガーバーの外形層に出ている | 2 |
| 4 | 済 | ケースを変更する（ホイール、床の軸、プランジャーブロックの削除、検査） | `gen/make_case.py`、`case/` | `.venv/bin/python gen/make_case.py` の検査がすべて通る。`case/print/<side>-detent.stl` がなくなる | 3 |
| 5 | 済 | ファームウェアを QMK のエンコーダー機能に置き換える | `gen/make_qmk.py`、`firmware/qmk/keyboards/nrsk/` | `qmk compile -kb nrsk -km default` が通る | 2 |
| 6 | 済 | BOM を更新する | `gen/make_bom.py`、`gen/bom_sources.json`、`bom/` | BOM から AS5600、磁石、ボールプランジャー、プランジャーブロック、その M2 ネジが消え、EC05E1220401 が 2 個載る。1 µF と 0.1 µF のコンデンサの数が左右 1 個ずつ減る | 3、4 |
| 7 | 済 | 組み立てガイドと 3D ビューアを更新する | `gen/assembly_guide.py`、`gen/case_viewer.py`、`case/preview/` | 組み立てガイドからセンサー、磁石、プランジャーの手順が消え、エンコーダーの半田付けとホイールの差し込みの手順が入る。ビューアでエンコーダーとホイールの位置が合っている | 4、6 |
| 8 | 済 | BOM の購入先を LCSC にそろえる | `gen/bom_sources.json`、`gen/make_bom.py`、`bom/` | LCSC で買える部品は、先頭の購入先がすべて LCSC の製品ページになっている。LCSC にない部品は備考に明記されている。載せた製品ページはすべて開いて確かめてある | 6 |
| 9 | 済 | README を更新し、レンダリングを作り直す。検討用のスクリプトを片付ける | `README.md`、`docs/img/`、`gen/encoder_study.py`、`gen/encoder_study.sh`、`gen/render_encoder_study.py`、`gen/encoder_sheet.py` | README のサムホイールの節が新しい構成を説明し、textlint の指摘が 0 件。`./gen/render_all.sh` が通る。検討用のスクリプトは削除し、`docs/img/encoder-study/` の画像は検討の記録として残す | 4、5、7、8 |
| 10 | 未 | 実機で確かめる | なし（結果は README に追記） | 六角ピンのはめあいを試し印刷で決める。左右のホイールで、回す向き、1 クリック 1 回の送り、山の手前で戻したときに送りが出ないこと、クリックの手触りを確かめる | 3、4、5 |

ステップ 4 で `Half.detent_block` を消すと、`gen/encoder_study.py` の現在の構成を組み立てる部分が動かなくなる。検討用のスクリプトをステップ 9 で消すのはこのためである。

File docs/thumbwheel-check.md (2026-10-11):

# サムホイールと OLED の実機確認

サムホイールを Alps EC05E1220401（中空シャフトのロータリーエンコーダー）で読む構成と、LCSC の OLED モジュールを、実物の部品で確かめる手順です。設計の経緯は [docs/specs/thumbwheel-encoder.md](specs/thumbwheel-encoder.md) の手順表のステップ 10 にあります。各項目の結果は README の「発注・組み立て前の確認事項」に記録します。

確認は次の順に進めます。六角ピンの寸法が決まらないとホイールを印刷できず、ホイールがないと回転の確認ができないからです。

1. 六角ピンのはめあい（エンコーダー単体と試し印刷）
2. 基板の差し込み（3D プリント版のトレイ、基板、ホイール）
3. 回す向き（ファームウェアを書き込んだ基板）
4. クリックと送りの対応、クリックの手触り
5. OLED の動作と高さ

## 1. 六角ピンのはめあい

ホイール上面の六角ピンは、エンコーダーの六角穴（対辺 1.72 mm）に差し込んで回転部を回します。ピンの対辺は今 1.66 mm です。細すぎると回転方向のガタが増え、太すぎると入りません。印刷機によって仕上がりの寸法が変わるので、試し印刷で決めます。

`case/print/pin-coupon.stl` は、対辺 1.60 mm から 1.72 mm まで 0.02 mm 刻みの六角ピン 7 本を並べた板です（63 × 16 mm）。ピンの高さと先端の面取りはホイールのピンと同じです。各ピンの下に、対辺を 0.01 mm 単位で示す 2 桁の数字が浮き出ています（66 は 1.66 mm）。ホイールと同じ条件で印刷します（同じ材料、同じ層の高さ、ピンを上に向ける）。

1. エンコーダーの六角穴には向きがあり、基板と反対の面（対辺 1.73 mm の側）からピンを差し込みます。JLCPCB で実装した基板なら、裏面で下を向いたエンコーダーへ、そのまま下からピンを差し込めます。
2. 細いピンから順に差し込み、力をかけずに奥まで入るもっとも太いピンを探します。
3. そのピンに差したまま、エンコーダーの本体を指で押さえて回転部を左右に揺すり、クリックが動く前のガタを確かめます。
4. 記録すること：もっとも太く入ったピンの数字、そのピンでのガタの感触、1 つ太いピンが入らなかった様子（先端だけ入る、まったく入らない）。

結果をもとに `gen/make_case.py` の `PIN_AF` を変え、ホイールの STL（`case/print/<side>-wheel.stl`）を作り直します。

## 2. 基板の差し込み（3D プリント版）

3D プリント版では、基板を奥へ滑らせて、USB-C と TRRS の差込口を奥の壁のトンネルに入れます。このとき、基板の裏に付けたエンコーダーの下面は、ホイールの六角ピンの先端から約 0.3 mm 上を通ります。

1. トレイの床の軸にホイールを差し、ホイールが軽く回ることを確かめます（軸とのすき間は半径方向に 0.2 mm）。
2. 基板を差込口のトンネルへ滑り込ませます。エンコーダーがピンに引っ掛かるかを見ます。引っ掛かる場合は、ホイールのある角を少し持ち上げて滑らせます。
3. 基板をボスまで下ろします。ピンが穴に入らないときは、ホイールの縁を指で少し回して向きを合わせます。
4. ネジを締めたあと、ホイールを 1 回転させ、こすれや重くなる位置がないかを確かめます。
5. 記録すること：角を持ち上げずに通ったか、持ち上げれば通ったか、通らなかったか。下ろしたときにピンが穴に入ったか。回したときの引っ掛かりの有無。

## 3. 回す向き

README の「ファームウェア」の節の手順で `nrsk_default.uf2` を左右に書き込み、TRRS ケーブルでつないで、片方を USB でPCにつなぎます。

1. 左のホイールを、上から見て時計回りに 1 クリック回します。音量が上がれば正しい向きです。
2. 右のホイールを上から見て時計回りに 1 クリック回します。長いウェブページなどを開いておき、下へ 1 ページ進めば正しい向きです。
3. USB を反対側の半分につなぎ替えて、もう一度 1 と 2 を確かめます。USB をつないでいない側のホイールが効くことも、ここで確かめます。
4. 記録すること：左右それぞれ、時計回りで送られたキー（音量の上下、ページの上下）。

向きが逆の場合は、`gen/make_qmk.py` のエンコーダーの `pin_a` と `pin_b` を入れ替え、ファームウェアを作り直します。左右は同じ部品を同じ向きに付けているので、逆になるときは左右とも逆になるはずです。片側だけが逆のときは、その側の配線か半田付けを疑います。

## 4. クリックと送りの対応

エンコーダーは 1 回転 12 クリックで、1 クリックごとに A 相と B 相の信号がちょうど 1 周期進みます。ファームウェアは 1 周期で 1 回だけキーを送ります。

1. キー入力を表示するページ（QMK Configurator のキーテスター、`https://config.qmk.fm/#/test`）を開きます。右のホイールが送る Page Up と Page Down は、ここで回数を数えられます。左のホイールの音量は、画面に出る音量の表示で数えます。
2. 1 クリックずつ 12 回回し、送りが 12 回出ることを確かめます。逆向きにも同じように確かめます。
3. ホイールをクリックの山の手前まで回し、山を越えずに戻します。このとき送りが出ないことを確かめます。山の手前で何度か往復させても同じです。
4. 速く回したとき（1 秒に 1 回転ほど）に、送りの抜けが目立たないかを見ます。
5. 手触りを確かめます。エンコーダーのクリックトルクは 1.6 ± 1.3 mN·m で、ホイールの縁では約 0.11 N（ばらつきの範囲で 0.02〜0.2 N）にあたります。クリックの区切りがわかるか、軽すぎて意図せず回らないかを見ます。
6. 記録すること：12 クリックで送られた回数（左右、両方向）、山の手前で戻したときの送りの有無、速く回したときの様子、手触りの感想。

1 クリックで送りが 2 回以上出る場合や、2 クリックで 1 回しか出ない場合は、QMK の `resolution`（デフォルト値 4）を見直します。クリックが軽すぎる場合は、ホイールの直径を小さくする案を別件として検討します（仕様書の「やらないこと」の 1 つ目）。

## 5. OLED の動作と高さ

BOM の先頭の購入先は LCSC の HS91L02W2C01（C5248081）です。LCSC の製品ページの写真ではピン順が GND/VCC/SCL/SDA ですが、3.3 V で動くかとピンヘッダが付くかは書かれていません。

1. 半田付けの前に、モジュールの裏の印字でピン順を確かめます。基板のパッドの順（GND/VCC/SCL/SDA）と同じかを見ます。
2. モジュールに電圧変換の部品（3 端子のレギュレーター）が載っているかを見ます。載っていれば、3.3 V で動かない場合があります。
3. 基板に付けて電源を入れ、USB をつないだ側にレイヤーと Caps Lock、もう一方に WPM が表示されることを確かめます。
   文字の向きも見ます。モジュールは左右とも同じ向き（ピンヘッダが下）に付くので、逆さまなら左右とも逆さまです。その場合は `gen/make_qmk.py` の `OLED_ROTATION_270` を `OLED_ROTATION_90` に変え、`keymap.c` を作り直します。
4. ピンヘッダの黒い樹脂スペーサーを外して半田付けしたあと、基板の上面からガラス上面までの高さを測ります。設計では 2.5 mm です。高いとカバーに当たり、低いとカバーとのすき間が両面テープ（0.5 mm）より大きくなります。
5. 記録すること：ピン順、ピンヘッダの有無、3.3 V での表示の有無、文字の向き、ガラス上面の高さ。

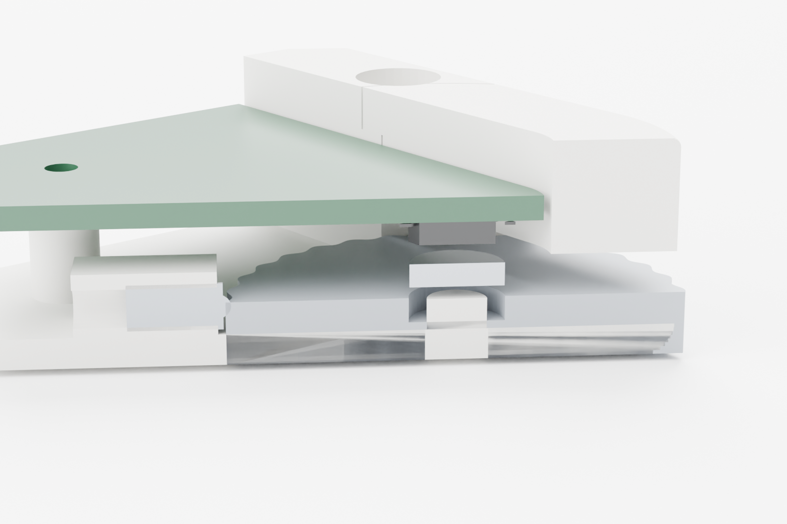
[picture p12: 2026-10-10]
docs/img/encoder-study/section-left-current.png

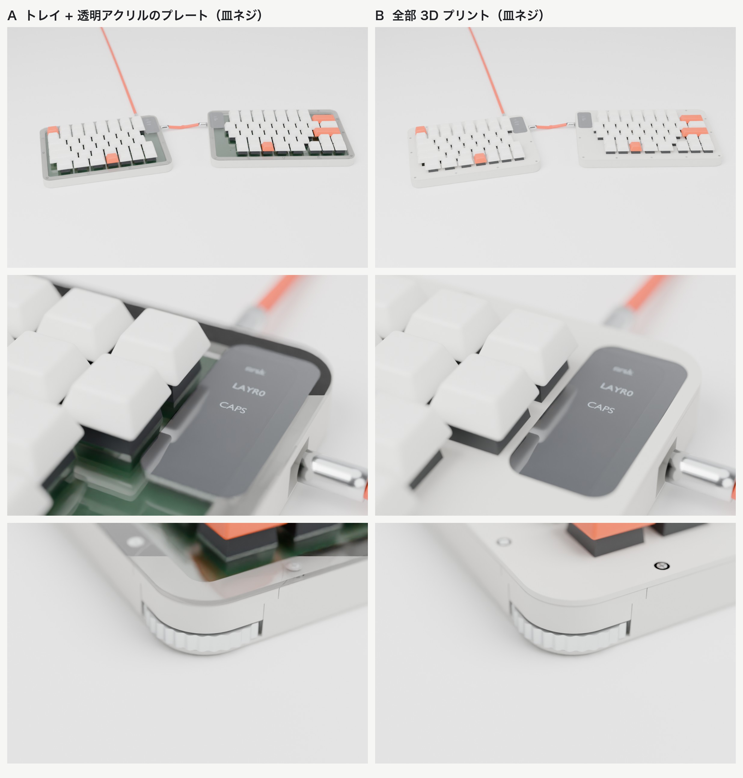
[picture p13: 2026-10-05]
docs/img/render-compare-top-flat.jpg

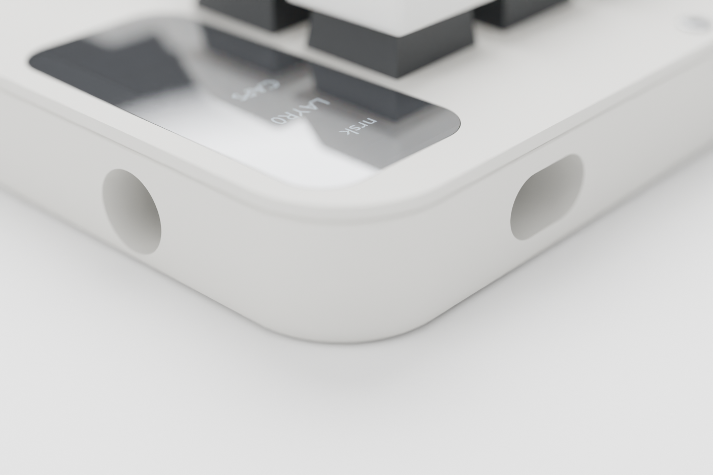
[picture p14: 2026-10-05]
docs/img/render-ports-tidy.png

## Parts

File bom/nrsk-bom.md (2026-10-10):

> 単価・在庫は 2026-10-04 時点の参考値。リンク先はすべて開いて型番と仕様を確認済み。

| 分類 | 部品 | 仕様 | 左 | 右 | 合計 | メーカー型番・商品名 | 購入先 | 単価（参考） | URL | 備考 |
| --- | --- | --- | --- | --- | --- | --- | --- | --- | --- | --- |
| MCU | マイコン RP2040 | Raspberry Pi RP2040、QFN-56 7×7 mm | 1 | 1 | 2 | Raspberry Pi RP2040 | LCSC C2040 | US$1.00 | [リンク](https://www.lcsc.com/product-detail/C2040.html) |  |
| MCU | QSPI フラッシュ 16 MB | Winbond W25Q128JVSIQ、SOIC-8 208 mil | 1 | 1 | 2 | Winbond W25Q128JVSIQ | LCSC C113767 | US$2.52 | [リンク](https://www.lcsc.com/product-detail/C113767.html) | よく使われる C97521 は同じ型番だが確認時に在庫切れ |
| MCU | 　└ 代替 |  |  |  |  | Winbond W25Q16JVSSIQ（2 MB、同じ 208 mil） | LCSC C82317 | US$1.07 | [リンク](https://www.lcsc.com/product-detail/C82317.html) | 容量は小さいがキーボードには十分 |
| 電源 | LDO 3.3 V | Diodes AP2112K-3.3TRG1（600 mA）、SOT-23-5 | 1 | 1 | 2 | Diodes AP2112K-3.3TRG1 | LCSC C51118 | US$0.17 | [リンク](https://www.lcsc.com/product-detail/C51118.html) |  |
| コネクタ | USB-C レセプタクル | HRO TYPE-C-31-M-12（16 ピン、USB 2.0） | 1 | 1 | 2 | Korean Hroparts TYPE-C-31-M-12 | LCSC C165948 | US$0.17 | [リンク](https://www.lcsc.com/product-detail/C165948.html) |  |
| コネクタ | TRRS ジャック 3.5 mm | PJ-320D（4 極、表面実装） | 1 | 1 | 2 | SHOU HAN PJ-320D | LCSC C431535 | US$0.05 | [リンク](https://www.lcsc.com/product-detail/C431535.html) | LCSC の EasyEDA フットプリントと照合済み：固定ピン間隔 7.0 mm が一致し、端子位置の差は 0.1 mm 以内で KiCad の PJ320D パッドに載る |
| コネクタ | 　└ 代替 |  |  |  |  | Korean Hroparts PJ-320D-4A | LCSC C95562 | US$0.11 | [リンク](https://www.lcsc.com/product-detail/C95562.html) | 代替。同じく固定ピン間隔 7.0 mm が一致し、端子位置の差は 0.1 mm 以内 |
| 保護 | USB ESD 保護 | STMicroelectronics USBLC6-2SC6, SOT-23-6 | 1 | 1 | 2 | STMicroelectronics USBLC6-2SC6 | LCSC C7519 | US$0.18 | [リンク](https://www.lcsc.com/product-detail/C7519.html) |  |
| クロック | 水晶振動子 12 MHz | 3225 4 パッド、負荷容量 10 pF 前後（15 pF のコンデンサと組み合わせる） | 1 | 1 | 2 | Abracon ABM8-272-T3（CL 10 pF） | LCSC C20625731 | US$0.63 | [リンク](https://www.lcsc.com/product-detail/C20625731.html) | Raspberry Pi のリファレンスと同じ部品。安価な YXC X322512MSB4SI（C9002）は CL 20 pF なので 15 pF のコンデンサとは合わない |
| 保護 | ポリスイッチ 500 mA | 1206（例: Bourns MF-NSMF050-2） | 1 | 1 | 2 | Bourns MF-NSMF050-2 | LCSC C75464 | US$0.04 | [リンク](https://www.lcsc.com/product-detail/C75464.html) |  |
| 保護 | ショットキーダイオード | B5819W（40 V 1 A）, SOD-123 | 1 | 1 | 2 | JSCJ B5819W SL | LCSC C8598 | US$0.03 | [リンク](https://www.lcsc.com/product-detail/C8598.html) |  |
| マトリクス | スイッチングダイオード | 1N4148W, SOD-123 | 44 | 48 | 92 | 1N4148W（SOD-123） | LCSC C81598 | US$0.012 | [リンク](https://www.lcsc.com/product-detail/C81598.html) |  |
| 受動部品 | コンデンサ 15 pF | 0805 C0G 50 V（水晶の負荷容量） | 2 | 2 | 4 | YAGEO CC0805JRNPO9BN150 | LCSC C107110 | US$0.0096 | [リンク](https://www.lcsc.com/product-detail/C107110.html) |  |
| 受動部品 | コンデンサ 0.1 µF | 0805 X7R 50 V | 11 | 11 | 22 | YAGEO CC0805KRX7R9BB104 | LCSC C49678 | US$0.019 | [リンク](https://www.lcsc.com/product-detail/C49678.html) |  |
| 受動部品 | コンデンサ 1 µF | 0805 X7R 25 V 以上（LDO、RP2040 の内蔵レギュレータ） | 4 | 4 | 8 | Samsung CL21B105KBFNNNE（50 V） | LCSC C28323 | US$0.04 | [リンク](https://www.lcsc.com/product-detail/C28323.html) |  |
| 受動部品 | コンデンサ 10 µF | 0805 X5R 10 V 以上 | 1 | 1 | 2 | Samsung CL21A106KAYNNNE（X5R 25 V） | LCSC C15850 | US$0.066 | [リンク](https://www.lcsc.com/product-detail/C15850.html) |  |
| 受動部品 | 抵抗 10 kΩ | 0805 1% | 2 | 2 | 4 | UNI-ROYAL 0805W8F1002T5E | LCSC C17414 | US$0.0034 | [リンク](https://www.lcsc.com/product-detail/C17414.html) |  |
| 受動部品 | 抵抗 27 Ω | 0805 1%（USB D+/D−） | 2 | 2 | 4 | UNI-ROYAL 0805W8F270JT5E | LCSC C17594 | US$0.0029（100 個単位） | [リンク](https://www.lcsc.com/product-detail/C17594.html) | 2026-10-10 に確認（在庫 195,300）。JLCPCB の部品実装の推奨部品（Preferred）で、在庫は約 4 万個 |
| 受動部品 | 　└ 代替 |  |  |  |  | YAGEO RC0805FR-0727RL | LCSC C163408 | US$0.0078 | [リンク](https://www.lcsc.com/product-detail/C163408.html) | 代替。JLCPCB の部品実装の在庫が 5 個しかない（2026-10-10、LCSC の在庫は別で 4,900） |
| 受動部品 | 抵抗 1 kΩ | 0805 1%（水晶の XOUT 直列、BOOTSEL） | 2 | 2 | 4 | UNI-ROYAL 0805W8F1001T5E | LCSC C17513 | US$0.0041 | [リンク](https://www.lcsc.com/product-detail/C17513.html) |  |
| 受動部品 | 抵抗 5.1 kΩ | 0805 1%（USB-C CC） | 2 | 2 | 4 | UNI-ROYAL 0805W8F5101T5E | LCSC C27834 | US$0.0056 | [リンク](https://www.lcsc.com/product-detail/C27834.html) |  |
| 表示 | OLED モジュール 0.91 インチ | 128×32、SSD1306、I2C、3.3 V、ピン順 GND/VCC/SCL/SDA（ガラス上面を基板から 2.5 mm に） | 1 | 1 | 2 | HS HS91L02W2C01（0.91 インチ 128×32、SSD1306、I2C） | LCSC C5248081 | US$2.26 | [リンク](https://www.lcsc.com/product-detail/C5248081.html) | 2026-10-10 に確認（在庫 3,017）。写真のピン順は GND/VCC/SCL/SDA。3.3 V で動くか、ピンヘッダが付くかはページに記載なし |
| 表示 | 　└ 代替 |  |  |  |  | OLED モジュール（0.91 インチ 128×32、SSD1306、ピンソケット付き） | 遊舎工房 | ¥825 | [リンク](https://shop.yushakobo.jp/products/oled) | 商品ページにピン順の記載なし。GND/VCC/SCL/SDA であることを現物のシルクで確認 |
| 入力 | ロータリーエンコーダー（サムホイール用） | Alps Alpine EC05E1220401、中空シャフト（六角穴 対辺 1.72 mm）、12 クリック / 12 パルス、表面実装、基板の裏に付ける | 1 | 1 | 2 | Alps Alpine EC05E1220401 | LCSC C116648 | US$1.08 | [リンク](https://www.lcsc.com/product-detail/C116648.html) | 2026-10-10 に確認（在庫 291 個） |
| 受動部品 | 抵抗 4.7 kΩ | 0805 1%（I2C プルアップ） | 2 | 2 | 4 | UNI-ROYAL 0805W8F4701T5E | LCSC C17673 | US$0.0051 | [リンク](https://www.lcsc.com/product-detail/C17673.html) |  |
| スイッチ | タクトスイッチ（リセット） | C&K PTS810 SJM 250 SMTR LFS（2 回押しで書き込みモード） | 1 | 1 | 2 | C&K PTS810SJM250SMTRLFS | LCSC C116501 | US$0.58 | [リンク](https://www.lcsc.com/product-detail/C116501.html) |  |
| スイッチ | BOOTSEL パッド | 基板のはんだジャンパー（部品なし）。ピンセットで短絡しながら USB を挿すと書き込みモード | 1 | 1 | 2 | 部品なし（基板のはんだジャンパー） | — |  |  |  |
| キースイッチ | MX 互換キースイッチ | 3 ピン / 5 ピンどちらでも可 | 44 | 48 | 92 | Kailh（HanElectricity）CPG151101D05 赤軸（リニア、45 gf） | LCSC C49234236 | US$0.108（5 個単位） | [リンク](https://www.lcsc.com/product-detail/C49234236.html) | 2026-10-10 に確認（在庫 1,210）。3 ピンか 5 ピンかはページに記載なし（どちらでも基板に付く） |
| キースイッチ | 　└ 代替 |  |  |  |  | Kailh Box V2 Red（リニア、5 ピン） | 遊舎工房 | ¥2,117 / 35 個 | [リンク](https://shop.yushakobo.jp/products/4264) | 92 個要るので 3 パック。確認時の在庫は 6 パックと少ない。遊舎工房の他の MX 互換スイッチでも可 |
| キースイッチ | 　└ 代替 |  |  |  |  | Kailh Super Speed Silver（リニア、3 ピン） | 遊舎工房 | ¥1,540 / 35 個 | [リンク](https://shop.yushakobo.jp/products/4280) | 在庫少 |
| キースイッチ | ホットスワップソケット | Kailh CPG151101S11（MX 用） | 44 | 48 | 92 | Kailh（HanElectricity）CPG151101S11-16 | LCSC C41430893 | US$0.043（10 個単位） | [リンク](https://www.lcsc.com/product-detail/C41430893.html) | 2026-10-10 に確認（在庫 217,980） |
| キースイッチ | スタビライザ 2 u（PCB マウント） | ネジ止め式推奨 | 1 | 2 | 3 | GDK-02 Pre-lubed PCB Mount Stabilizer | 遊舎工房 | ¥770 / セット | [リンク](https://shop.yushakobo.jp/products/11952) | 左 Shift、右 Backspace、右 Enter；LCSC に該当品なし；1 セットで 2 u が 4 個分。1 セットで足りる |
| 入力 | サムホイール | 直径 29.2 mm × 厚さ 4.1 mm、外周に 32 山のすべり止め、上面にエンコーダーを回す六角ピン（対辺 1.66 mm）（case/print/<side>-wheel.stl） | 1 | 1 | 2 | case/print/<side>-wheel.stl | 自作（3D プリント） |  |  | 六角ピンのはめあいは試し印刷で調整する；LCSC に該当品なし（自作の 3D プリント部品） |
| キーキャップ | キーキャップ 1 u |  |  |  | 81 | DSA 無刻印キーキャップ 1 u（PBT、22 色） | 遊舎工房 | ¥55 | [リンク](https://shop.yushakobo.jp/products/dsa-blank-keycaps) | LCSC に該当品なし |
| キーキャップ | キーキャップ 1.25 u |  |  |  | 5 | Signature Plastics DSA 1.25 u | spkeyboards.com（米国） | US$3.50 | [リンク](https://spkeyboards.com/products/dsa-1-25-space) | LCSC に該当品なし；国内で DSA 1.25 u が見つからなかったため海外通販。輸入時に関税・消費税 |
| キーキャップ | キーキャップ 1.5 u |  |  |  | 2 | DSA 無刻印キーキャップ 1.5 u（白・黒・灰・緑・赤） | 遊舎工房 | ¥220 | [リンク](https://shop.yushakobo.jp/products/10731) | LCSC に該当品なし |
| キーキャップ | キーキャップ 1.75 u |  |  |  | 1 | Signature Plastics DSA 1.75 u | spkeyboards.com（米国） | US$3.50 | [リンク](https://spkeyboards.com/collections/individual-keys/products/sp-dsa-1-75-space) | LCSC に該当品なし |
| キーキャップ | キーキャップ 2 u |  |  |  | 1 | DSA 無刻印キーキャップ 2 u（白・黒） | 遊舎工房 | ¥220 | [リンク](https://shop.yushakobo.jp/products/11443) | LCSC に該当品なし |
| キーキャップ | キーキャップ 2.25 u |  |  |  | 2 | Signature Plastics DSA 2.25 u（スタビ対応） | spkeyboards.com（米国） | US$4.00 | [リンク](https://spkeyboards.com/products/sp-dsa-2-25-space-single-keycap) | LCSC に該当品なし |
| アクリル版 | M2 スペーサー 7 mm（メス-メス） | 六角 対辺 3.5〜4 mm、真鍮、ステンレスまたはナイロン | 8 | 8 | 16 | XHHD 303HZ20007（ステンレス、対辺 4 mm） | LCSC C52976405 | US$0.28 / 10 個（10 個単位） | [リンク](https://www.lcsc.com/product-detail/C52976405.html) | 基板と底板の間；2026-10-10 に確認（在庫 500） |
| アクリル版 | 　└ 代替 |  |  |  |  | 廣杉計器 ASB-2007E（黄銅、両メネジ） | MonotaRO | ¥1,978 / 50 個 | [リンク](https://www.monotaro.com/p/1111/2937/) |  |
| アクリル版 | M2 × 4 mm なべネジ | 基板の上からスペーサーへ | 8 | 8 | 16 | Shuntian PM2X4nie（ニッケルめっき、頭 φ3.3 × 1.3） | LCSC C357393 | US$0.19 / 100 本（100 本単位） | [リンク](https://www.lcsc.com/product-detail/C357393.html) | 2026-10-10 に確認（在庫 11,700） |
| 筐体共通 | ゴム足 | 直径 8〜10 mm、高さ 3 mm 以上 | 4 | 4 | 8 | 3M クッションゴム 丸形 CS-02（φ9.5 × 3.8 mm） | MonotaRO | ¥483 / 18 個 | [リンク](https://www.monotaro.com/p/4525/7232/) | 底面に出るネジ先・ナットより高いもの；LCSC に該当品なし |
| 筐体共通 | 　└ 代替 |  |  |  |  | 栃木屋 クリアバンポン TM-180-303（φ11.2 × 5.1 mm） | MonotaRO | ¥48 / 個 | [リンク](https://www.monotaro.com/p/4262/7707/) |  |
| 筐体共通 | 透明アクリル板 1.5 mm（プレート） | <side>-plate、左 189.6×143.3 mm / 右 216.6×143.3 mm | 1 | 1 | 2 | アクリル板 DXF 切削（図面で WEB オーダー） | はざいや（菅原工芸） | 見積 | [リンク](https://www.hazaiya.co.jp/estimate-drawing) | 3D プリント版もアクリル版もこのプレートを使う；LCSC に該当品なし；透明 1.5 mm で注文。切断線どうしの間隔 3 mm 未満は不可 |
| アクリル版 | マットクリア アクリル板 3 mm（枠） | 同上の外形、片側 4 枚（frame1〜4） | 4 | 4 | 8 | アクリル板キャスト 片面マットクリア（パラグラス C1 P） | はざいや（菅原工芸） | 見積 | [リンク](https://www.hazaiya.co.jp/products/detail/3481) | frame1〜3 は差込口の切り欠きあり、frame4 は切り欠きなし；LCSC に該当品なし；2 / 3 / 5 mm。図面 WEB オーダー（https://www.hazaiya.co.jp/estimate-drawing）で DXF から切り出し |
| アクリル版 | マットクリア アクリル板 3 mm（底板） | 同上の外形 | 1 | 1 | 2 | アクリル板キャスト 片面マットクリア（パラグラス C1 P） | はざいや（菅原工芸） | 見積 | [リンク](https://www.hazaiya.co.jp/products/detail/3481) | LCSC に該当品なし；2 / 3 / 5 mm。図面 WEB オーダー（https://www.hazaiya.co.jp/estimate-drawing）で DXF から切り出し |
| アクリル版 | M2 × 20 mm なべネジ | 外周：プレートの上から底板まで貫通（16.5 mm + ナット） | 10 | 11 | 21 | OHSATO ナベ頭小ねじ M2 × 20（ステンレス） | MonotaRO | ¥329 / 50 本 | [リンク](https://www.monotaro.com/p/1714/1900/) | LCSC に該当品なし |
| アクリル版 | M2 ナット | 外周ネジ用（底板の下） | 10 | 11 | 21 | 大阪魂 六角ナット 1 種 M2（SUS304、対辺 4 × 厚さ 1.6） | MonotaRO | ¥164 / 20 個 | [リンク](https://www.monotaro.com/p/2876/3624/) | LCSC に該当品なし |
| アクリル版 | 　└ 代替 |  |  |  |  | エスコ EA949LT-720 六角ナット M2（真鍮、ニッケルめっき） | MonotaRO | ¥798 / 80 個 | [リンク](https://www.monotaro.com/p/5052/3646/) |  |
| アクリル版 | M2 × 5 mm なべネジ | 底板の下からスペーサーへ | 8 | 8 | 16 | なべ小ねじ M2 × 5 | 遊舎工房 | ¥220 / 50 本 | [リンク](https://shop.yushakobo.jp/products/a0800n2?variant=37665432993953) | LCSC は在庫切れ（C357529） |
| アクリル版 | 　└ 代替 |  |  |  |  | 大阪魂 ナベ頭小ねじ M2 × 5（ステンレス） | MonotaRO | ¥1,099 / 160 本 | [リンク](https://www.monotaro.com/p/0550/6916/) |  |
| OLED カバー | ハーフミラー アクリル板 2 mm | <side>-oled-cover（DXF/SVG）、プレートの窓にはめ込み、上面をプレートと面一 | 1 | 1 | 2 | アクリル板キャスト ハーフミラー 30%（三菱 MRH-001T-30） | はざいや（菅原工芸） | 見積 | [リンク](https://www.hazaiya.co.jp/products/detail/3373) | OLED のガラス面に載せる。両方の筐体で共通；LCSC に該当品なし；2 / 3 / 5 mm。図面 WEB オーダーで DXF から切り出し。1.5 mm のアクリル製ハーフミラーはメーカーにもない |
| OLED カバー | 　└ 代替 |  |  |  |  | アクリルハーフミラー板 フリーカット（2 mm、透過 30%） | アクリ屋ドットコム | 見積 | [リンク](https://www.acry-ya.com/products/detail/113/) | 最小 10 × 10 mm から |
| OLED カバー | 透明両面テープ 厚さ 0.5 mm | カバーと OLED のガラス面、カバーの縁が載る壁の上面に貼る |  |  |  | 3M スコッチ はがせる両面テープ 超透明 KRT-15（幅 15 × 1.5 m × 厚さ 0.5 mm） | カインズ |  | [リンク](https://www.cainz.com/g/4547452982974.html) | 少量；LCSC に該当品なし；はがせるタイプなので OLED を交換できる |
| 3D プリント版 B | M2 ヒートセットインサート | 外径 3.2 mm × 長さ 3 mm、プレート裏のボスに入れる | 10 | 11 | 21 | XHHD SZTB1063（真鍮、両ローレット） | LCSC C51938879 | US$0.51 / 50 個（50 個単位） | [リンク](https://www.lcsc.com/product-detail/C51938879.html) | 2026-10-10 に確認（在庫 9,300）。寸法（M2、長さ 3 mm、外径 3.2 mm）は品名 M2*3*3.2 から読んだもの |
| 3D プリント版 B | 　└ 代替 |  |  |  |  | Prusa Heat Set Inserts M2 short | Prusa Research | US$11.99 / 100 個 | [リンク](https://www.prusa3d.com/ja/product/heat-set-inserts-m2-short-100-pcs/) | 3D プリント用。寸法の記載なし |
| 3D プリント版 A | M2 ナット（ナット受け用） | 壁上面のくぼみの下の六角穴に入れる | 10 | 11 | 21 | 大阪魂 六角ナット 1 種 M2（SUS304、対辺 4 × 厚さ 1.6） | MonotaRO | ¥164 / 20 個 | [リンク](https://www.monotaro.com/p/2876/3624/) | LCSC に該当品なし |
| 3D プリント版 A | 　└ 代替 |  |  |  |  | エスコ EA949LT-720 六角ナット M2（真鍮、ニッケルめっき） | MonotaRO | ¥798 / 80 個 | [リンク](https://www.monotaro.com/p/5052/3646/) |  |
| 3D プリント版 A | M2 × 6 mm スリムヘッド小ねじ | 頭 φ4.0 × 高さ 0.5 mm、透明アクリルのプレートを上から留める | 10 | 11 | 21 | 大阪魂 (+)スリムヘッド小ねじ ステンレス M2 × 6（φ4 × 0.5、注文コード 41746713） | MonotaRO | 7 本入り | [リンク](https://www.monotaro.com/p/4174/6713/) | LCSC に該当品なし（頭の低い M2 は皿ネジだけ） |
| アクリル版 | M3 × 8 mm なべネジ | サムホイールの軸（底板の下から差し込む） | 1 | 1 | 2 | Shuntian PM3X8（ニッケルめっき） | LCSC C357544 | US$0.23 / 100 本（100 本単位） | [リンク](https://www.lcsc.com/product-detail/C357544.html) | 3D プリント版はトレイの軸を使う；2026-10-10 に確認（在庫 27,500） |
| 3D プリント版 B | M2 × 12 mm なべネジ（底から） | トレイ底の座ぐりから壁を通してプレート裏のインサートへ | 10 | 11 | 21 | TRUSCO Y823-0212 ナベ頭小ねじ ステンレス M2 × 12 | MonotaRO | ¥395 / 20 本 | [リンク](https://www.monotaro.com/p/2498/0167/) | LCSC に該当品なし |
| 3D プリント版 B | 　└ 代替 |  |  |  |  | エスコ EA949NF-212 鍋頭小ねじ ステンレス M2 × 12 | MonotaRO | ¥275 / 16 本 | [リンク](https://www.monotaro.com/g/02450718/) |  |
| 3D プリント版 | M2 × 6 mm タッピングネジ | 基板をボス（下穴 φ1.6）へ固定 | 8 | 8 | 16 | Shuntian PA2X6nie（なべ、頭 φ3.5、ニッケルめっき） | LCSC C357360 | US$0.16 / 100 本（100 本単位） | [リンク](https://www.lcsc.com/product-detail/C357360.html) | 2026-10-10 に確認（在庫 2,900） |
| ケーブル | TRRS ケーブル（4 極、オス-オス） | 3.5 mm |  |  |  | TRRS ケーブル 0.3 m | 遊舎工房 | ¥330 | [リンク](https://shop.yushakobo.jp/products/8023) | 1 本；LCSC に該当品なし |
| ケーブル | 　└ 代替 |  |  |  |  | TRRS ケーブル 0.8 m（メタル） | 遊舎工房 | ¥1,100 | [リンク](https://shop.yushakobo.jp/products/8111) |  |
| ケーブル | USB-C ケーブル | USB 2.0 以上 |  |  |  | Ckmtw S100920007（USB-A to C、データ用、1 m） | LCSC C430908 | US$2.12 | [リンク](https://www.lcsc.com/product-detail/C430908.html) | 1 本；2026-10-10 に確認（在庫 110） |
| ケーブル | 　└ 代替 |  |  |  |  | USB Type-C to C 1.0 m | 遊舎工房 | ¥440 | [リンク](https://shop.yushakobo.jp/products/11426) |  |
| 基板 | プリント基板（2 層、1.6 mm） | fab/<side>/nrsk-<side>-gerber.zip | 1 | 1 | 2 | Gerber から発注（実装サービスも可） | JLCPCB | 見積 | [リンク](https://cart.jlcpcb.com/quote) |  |

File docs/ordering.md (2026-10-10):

# 発注の手順

nrsk 分割キーボードを 1 台（左右 1 組）作るための注文を、注文先ごとにまとめます。数量と購入先は [bom/nrsk-bom.md](../bom/nrsk-bom.md) から取りました。価格と在庫は 2026-10-10 時点の値で変わるので、注文の直前に各ページで確かめてください。

注文先は 5 つです。JLCPCB が基板と電子部品の実装、LCSC が手で付ける部品と一部のネジ、国内の店がキーキャップやネジの残り、海外の店が一部のキーキャップ、はざいやがアクリルの切り出しを受け持ちます。届くまでの日数は、基板の実装と海外のキーキャップが長いので、この 2 つを先に注文します。

## 1. 筐体の版を決める

注文するネジと板は、筐体の版で変わります。先に版を選びます。

| 版 | 構成 | 印刷するもの | 切り出すアクリル |
| --- | --- | --- | --- |
| A | 3D プリントのトレイ + 透明アクリルのプレート | トレイ、ホイール、角キャップ | プレート、OLED カバー |
| B | すべて 3D プリント | トレイ、プレート、ホイール、角キャップ | OLED カバー |
| アクリル版 | アクリルの積み重ね | ホイール | プレート、枠 4 枚、底板、OLED カバー |

3D プリントのトレイは、右が幅 216.6 mm あります。造形範囲が 250 mm 角以上の 3D プリンターを勧めます（220 mm 角ではぎりぎりで、180 mm 角では入りません）。

## 2. JLCPCB：基板と電子部品の実装

基板は 2 層、厚さ 1.6 mm です。電子部品はすべて基板の裏面にあり、RP2040（0.4 mm ピッチ）と USB-C（0.5 mm ピッチ）は手半田に向かないので、JLCPCB の部品実装サービスを使います。左右は別の基板なので、2 回に分けて注文します。

| 側 | ガーバー | 部品表 | 配置 |
| --- | --- | --- | --- |
| 左 | `fab/left/nrsk-left-gerber.zip` | `fab/left/nrsk-left-jlc-bom.csv` | `fab/left/nrsk-left-jlc-cpl.csv` |
| 右 | `fab/right/nrsk-right-gerber.zip` | `fab/right/nrsk-right-jlc-bom.csv` | `fab/right/nrsk-right-jlc-cpl.csv` |

左右それぞれ、次の手順で注文します。

1. JLCPCB の基板の注文画面にガーバーをアップロードします。層数 2、厚さ 1.6 mm を選びます。ほかの設定はデフォルトのままでかまいません。
2. 部品実装（PCB Assembly）をオンにし、実装面を裏面（Bottom）にします。実装は 1 つの設計につき 2 枚からなので、枚数は 2 にします（予備が 1 枚ずつできます）。
3. 部品表と配置のファイルを渡します。部品表の 21 行がすべて LCSC の部品に対応づき、在庫が足りていることを確かめます。
4. 配置のプレビューで、次の部品の向きを確かめます。
   - RP2040 と Flash（U1、U5）の 1 番ピンの印が、基板のシルクの印と合っている。
   - ダイオード（D1〜、D99）のカソードの帯が、基板のシルクの帯と同じ側にある。
   - USB-C（J2）と TRRS ジャック（J1）の差込口が、基板の外側（奥の端）を向いている。USB-C だけは補正の値に確信がありません。差込口が内側を向いていたら、`gen/make_jlc.py` の `JLC_FIX` で USB-C の回転を 180 にして作り直します。
   - エンコーダー（ENC1）が、ホイールの角の 3 mm 角の穴の上にある。
5. 注文を確定します。拡張部品（Extended）が 10 種類あり、種類ごとに追加料金がかかります。

エンコーダー EC05E1220401 は、JLCPCB の在庫が 41 個と少ない部品です。在庫が足りなければ部品表から外し、LCSC で 2 個買って手で半田付けします。端子は 5 か所で、手半田でも付けられます。

実装されないもの（OLED、ホットスワップソケット、キースイッチ）は、次の LCSC の注文で買います。

## 3. LCSC：手で付ける部品と一部のネジ

LCSC は JLCPCB と別の注文です。ネジやスイッチは、決まった個数の単位で売られています。

| 部品 | 要る数 | LCSC の番号 | 注文の単位と数 |
| --- | --- | --- | --- |
| OLED モジュール 0.91 インチ（HS91L02W2C01） | 2 | C5248081 | 2 個 |
| キースイッチ Kailh 赤軸（CPG151101D05） | 92 | C49234236 | 5 個単位を 19（95 個） |
| ホットスワップソケット Kailh（CPG151101S11-16） | 92 | C41430893 | 10 個単位を 10（100 個） |
| USB ケーブル（USB-A to C） | 1 | C430908 | 1 本 |

OLED は、3.3 V で動くかとピンヘッダが付くかが LCSC のページに書かれていません。確実に動くものがほしい場合は、遊舎工房の OLED モジュールを代わりに買います（4 章）。

筐体の版によって、次のネジを足します。

| 部品 | A | B | アクリル版 | LCSC の番号 | 単位 |
| --- | --- | --- | --- | --- | --- |
| M2 × 6 mm タッピングネジ（基板の固定） | 16 | 16 | なし | C357360 | 100 本 |
| M2 ヒートセットインサート | なし | 21 | なし | C51938879 | 50 個 |
| M2 スペーサー 7 mm（メス-メス） | なし | なし | 16 | C52976405 | 10 個単位を 2 |
| M2 × 4 mm なべネジ | なし | なし | 16 | C357393 | 100 本 |
| M3 × 8 mm なべネジ（ホイールの軸） | なし | なし | 2 | C357544 | 100 本 |

## 4. 国内の店：遊舎工房、MonotaRO、カインズ

遊舎工房で、キーキャップの大半とスタビライザー、TRRS ケーブルを買います。

| 部品 | 数 | 備考 |
| --- | --- | --- |
| DSA 無刻印キーキャップ 1 u | 81 | 色は 22 色から選ぶ |
| DSA 無刻印キーキャップ 1.5 u | 2 | |
| DSA 無刻印キーキャップ 2 u | 1 | |
| スタビライザー GDK-02（PCB マウント） | 1 セット | 1 セットで 2 u が 4 か所分。使うのは 3 か所 |
| TRRS ケーブル（4 極） | 1 | 0.3 m |
| なべ小ねじ M2 × 5（50 本） | 1 袋 | アクリル版だけ |
| OLED モジュール 0.91 インチ（128×32） | 2 | LCSC の OLED の代わりに買う場合だけ。ピン順（GND/VCC/SCL/SDA）を現物で確かめる |

MonotaRO で、残りのネジとゴム足を買います。

| 部品 | A | B | アクリル版 | 入り数と袋数 |
| --- | --- | --- | --- | --- |
| ゴム足 3M CS-02（φ9.5 × 3.8 mm） | 8 | 8 | 8 | 18 個入りを 1 |
| M2 ナット（SUS304） | 21 | なし | 21 | 20 個入りを 2 |
| スリムヘッド小ねじ M2 × 6（頭 φ4 × 0.5 mm） | 21 | なし | なし | 7 本入りを 3 |
| ナベ頭小ねじ M2 × 12 | なし | 21 | なし | 20 本入りを 2 |
| ナベ頭小ねじ M2 × 20 | なし | なし | 21 | 50 本入りを 1 |

OLED カバーを貼る透明の両面テープ（厚さ 0.5 mm、3M スコッチ KRT-15 など）は、カインズなどのホームセンターで買えます。

## 5. 海外の店：Signature Plastics

1.25 u、1.75 u、2.25 u の DSA キーキャップは国内で見つからないので、Signature Plastics の通販（spkeyboards.com）で買います。輸入時に関税と消費税がかかります。

| 部品 | 数 |
| --- | --- |
| DSA 1.25 u | 5 |
| DSA 1.75 u | 1 |
| DSA 2.25 u（スタビライザー対応） | 2 |

## 6. はざいや：アクリルの切り出し

はざいや（菅原工芸）の図面 Web オーダーに、`case/laser/` の DXF（単位 mm、すべての線を切る）をアップロードします。DXF には切り抜く形だけが入っているので、材料と厚さは注文画面で指定します。

| ファイル | 材料と厚さ | A | B | アクリル版 |
| --- | --- | --- | --- | --- |
| `<side>-plate.dxf` | 透明 1.5 mm | 左右 1 枚ずつ | なし | 左右 1 枚ずつ |
| `<side>-frame1.dxf`〜`<side>-frame4.dxf` | 片面マットクリア 3 mm | なし | なし | 左右 4 枚ずつ |
| `<side>-bottom.dxf` | 片面マットクリア 3 mm | なし | なし | 左右 1 枚ずつ |
| `<side>-oled-cover.dxf` | ハーフミラー（透過 30％）2 mm | 左右 1 枚ずつ | 左右 1 枚ずつ | 左右 1 枚ずつ |

プレートのスイッチ穴（14.0 mm 角）は、レーザーの切り幅を補正して切る前提の寸法です。補正の有無を、注文時に確認してください。はざいやでは、切断線どうしの間隔が 3 mm 未満の図面は受け付けられません。

## 7. 3D プリント

`case/print/` の STL を印刷します。材料は PETG を勧めます。

| ファイル | A | B | アクリル版 | 向き |
| --- | --- | --- | --- | --- |
| `<side>-tray.stl` | 印刷する | 印刷する | なし | 床を下にする |
| `<side>-plate.stl` | なし | 印刷する | なし | 上下を逆にする（補強を上） |
| `<side>-wheel-cap.stl` | 印刷する | 印刷する | なし | |
| `<side>-wheel.stl` | 印刷する | 印刷する | 印刷する | 六角ピンを上にする |
| `pin-coupon.stl` | 先に印刷する | 先に印刷する | 先に印刷する | 六角ピンを上にする |

ホイールの六角ピンがエンコーダーの穴に合うかは、3D プリンターによって変わります。ホイールを印刷する前に `pin-coupon.stl` を同じ材料と設定で印刷し、ピンの太さを決めます。手順は [docs/thumbwheel-check.md](thumbwheel-check.md) の 1 章にあります。

## 注文前の確認

- 左右の基板それぞれで、JLCPCB の部品表の 21 行がすべて在庫ありになっている。
- 配置のプレビューで、2 章の手順 4 の部品の向きを確かめた。
- 筐体の版を決め、その版のネジ、アクリル、印刷物を 3〜7 章の表から拾った。
- キースイッチとソケットは 92 個以上、キーキャップは合計 92 個（1 u 81、1.25 u 5、1.5 u 2、1.75 u 1、2 u 1、2.25 u 2）になっている。

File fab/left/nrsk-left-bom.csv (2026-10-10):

Refs | Value | Footprint | Qty
C1,C2 | 15pF | Capacitor_SMD:C_0805_2012Metric | 2
C3,C4,C16,C17 | 1uF | Capacitor_SMD:C_0805_2012Metric | 4
C5,C6,C7,C8,C11,C12,C13,C14,C15,C18,C20 | 0.1uF | Capacitor_SMD:C_0805_2012Metric | 11
C19 | 10uF | Capacitor_SMD:C_0805_2012Metric | 1
D1,D2,D3,D4,D5,D6,D7,D8,D9,D10,D11,D12,D13,D14,D15,D16,D17,D18,D19,D20,D21,D22,D23,D24,D25,D26,D27,D28,D29,D30,D31,D32,D33,D34,D35,D36,D37,D38,D39,D40,D41,D42,D43,D44 | 1N4148W | Diode_SMD:D_SOD-123 | 44
D99 | B5819W | Diode_SMD:D_SOD-123 | 1
ENC1 | EC05E1220401 | nrsk:Alps_EC05E1220401 | 1
F1 | 500mA | Fuse:Fuse_1206_3216Metric | 1
J1 | PJ-320D | Connector_Audio:Jack_3.5mm_PJ320D_Horizontal | 1
J2 | USB-C | Connector_USB:USB_C_Receptacle_HRO_TYPE-C-31-M-12 | 1
J3 | OLED 128x32 | nrsk:OLED_0.91in_128x32_I2C | 1
JP1 | BOOTSEL | Jumper:SolderJumper-2_P1.3mm_Open_RoundedPad1.0x1.5mm | 1
R1,R6 | 10k | Resistor_SMD:R_0805_2012Metric | 2
R2,R3 | 27 | Resistor_SMD:R_0805_2012Metric | 2
R4,R5 | 5.1k | Resistor_SMD:R_0805_2012Metric | 2
R7,R10 | 1k | Resistor_SMD:R_0805_2012Metric | 2
R8,R9 | 4.7k | Resistor_SMD:R_0805_2012Metric | 2
RSW1 | Reset | Button_Switch_SMD:SW_SPST_PTS810 | 1
SW1 | Esc | nrsk:SW_MX_Hotswap_1.00u | 1
SW2 | F1 | nrsk:SW_MX_Hotswap_1.00u | 1
SW3 | F2 | nrsk:SW_MX_Hotswap_1.00u | 1
SW4 | F3 | nrsk:SW_MX_Hotswap_1.00u | 1
SW5 | F4 | nrsk:SW_MX_Hotswap_1.00u | 1
SW6 | F5 | nrsk:SW_MX_Hotswap_1.00u | 1
SW7 | F6 | nrsk:SW_MX_Hotswap_1.00u | 1
SW8 | 8 | nrsk:SW_MX_Hotswap_1.00u | 1
SW9 | ` | nrsk:SW_MX_Hotswap_1.00u | 1
SW10 | 1 | nrsk:SW_MX_Hotswap_1.00u | 1
SW11 | 2 | nrsk:SW_MX_Hotswap_1.00u | 1
SW12 | 3 | nrsk:SW_MX_Hotswap_1.00u | 1
SW13 | 4 | nrsk:SW_MX_Hotswap_1.00u | 1
SW14 | 5 | nrsk:SW_MX_Hotswap_1.00u | 1
SW15 | 6 | nrsk:SW_MX_Hotswap_1.00u | 1
SW16 | 16 | nrsk:SW_MX_Hotswap_1.00u | 1
SW17 | Tab | nrsk:SW_MX_Hotswap_1.50u | 1
SW18 | Q | nrsk:SW_MX_Hotswap_1.00u | 1
SW19 | W | nrsk:SW_MX_Hotswap_1.00u | 1
SW20 | E | nrsk:SW_MX_Hotswap_1.00u | 1
SW21 | R | nrsk:SW_MX_Hotswap_1.00u | 1
SW22 | T | nrsk:SW_MX_Hotswap_1.00u | 1
SW23 | 23 | nrsk:SW_MX_Hotswap_1.00u | 1
SW24 | Ctrl | nrsk:SW_MX_Hotswap_1.75u | 1
SW25 | A | nrsk:SW_MX_Hotswap_1.00u | 1
SW26 | S | nrsk:SW_MX_Hotswap_1.00u | 1
SW27 | D | nrsk:SW_MX_Hotswap_1.00u | 1
SW28 | F | nrsk:SW_MX_Hotswap_1.00u | 1
SW29 | G | nrsk:SW_MX_Hotswap_1.00u | 1
SW30 | 30 | nrsk:SW_MX_Hotswap_1.00u | 1
SW31 | Shift | nrsk:SW_MX_Hotswap_2.25u | 1
SW32 | Z | nrsk:SW_MX_Hotswap_1.00u | 1
SW33 | X | nrsk:SW_MX_Hotswap_1.00u | 1
SW34 | C | nrsk:SW_MX_Hotswap_1.00u | 1
SW35 | V | nrsk:SW_MX_Hotswap_1.00u | 1
SW36 | B | nrsk:SW_MX_Hotswap_1.00u | 1
SW37 | 37 | nrsk:SW_MX_Hotswap_1.00u | 1
SW38 | Ctrl | nrsk:SW_MX_Hotswap_1.25u | 1
SW39 | Opt | nrsk:SW_MX_Hotswap_1.25u | 1
SW40 | Cmd | nrsk:SW_MX_Hotswap_1.25u | 1
SW41,SW42,SW43 | Space | nrsk:SW_MX_Hotswap_1.00u | 3
SW44 | 44 | nrsk:SW_MX_Hotswap_1.00u | 1
U1 | RP2040 | Package_DFN_QFN:QFN-56-1EP_7x7mm_P0.4mm_EP3.2x3.2mm | 1
U2 | USBLC6-2SC6 | Package_TO_SOT_SMD:SOT-23-6 | 1
U4 | AP2112K-3.3 | Package_TO_SOT_SMD:SOT-23-5 | 1
U5 | W25Q128JVS | Package_SO:SOIC-8_5.3x5.3mm_P1.27mm | 1
Y1 | 12MHz | Crystal:Crystal_SMD_3225-4Pin_3.2x2.5mm_HandSoldering | 1

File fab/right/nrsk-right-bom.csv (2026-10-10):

Refs | Value | Footprint | Qty
C1,C2 | 15pF | Capacitor_SMD:C_0805_2012Metric | 2
C3,C4,C16,C17 | 1uF | Capacitor_SMD:C_0805_2012Metric | 4
C5,C6,C7,C8,C11,C12,C13,C14,C15,C18,C20 | 0.1uF | Capacitor_SMD:C_0805_2012Metric | 11
C19 | 10uF | Capacitor_SMD:C_0805_2012Metric | 1
D1,D2,D3,D4,D5,D6,D7,D8,D9,D10,D11,D12,D13,D14,D15,D16,D17,D18,D19,D20,D21,D22,D23,D24,D25,D26,D27,D28,D29,D30,D31,D32,D33,D34,D35,D36,D37,D38,D39,D40,D41,D42,D43,D44,D45,D46,D47,D48 | 1N4148W | Diode_SMD:D_SOD-123 | 48
D99 | B5819W | Diode_SMD:D_SOD-123 | 1
ENC1 | EC05E1220401 | nrsk:Alps_EC05E1220401 | 1
F1 | 500mA | Fuse:Fuse_1206_3216Metric | 1
J1 | PJ-320D | Connector_Audio:Jack_3.5mm_PJ320D_Horizontal | 1
J2 | USB-C | Connector_USB:USB_C_Receptacle_HRO_TYPE-C-31-M-12 | 1
J3 | OLED 128x32 | nrsk:OLED_0.91in_128x32_I2C | 1
JP1 | BOOTSEL | Jumper:SolderJumper-2_P1.3mm_Open_RoundedPad1.0x1.5mm | 1
R1,R6 | 10k | Resistor_SMD:R_0805_2012Metric | 2
R2,R3 | 27 | Resistor_SMD:R_0805_2012Metric | 2
R4,R5 | 5.1k | Resistor_SMD:R_0805_2012Metric | 2
R7,R10 | 1k | Resistor_SMD:R_0805_2012Metric | 2
R8,R9 | 4.7k | Resistor_SMD:R_0805_2012Metric | 2
RSW1 | Reset | Button_Switch_SMD:SW_SPST_PTS810 | 1
SW1 | 71 | nrsk:SW_MX_Hotswap_1.00u | 1
SW2 | F7 | nrsk:SW_MX_Hotswap_1.00u | 1
SW3 | F8 | nrsk:SW_MX_Hotswap_1.00u | 1
SW4 | F9 | nrsk:SW_MX_Hotswap_1.00u | 1
SW5 | F10 | nrsk:SW_MX_Hotswap_1.00u | 1
SW6 | F11 | nrsk:SW_MX_Hotswap_1.00u | 1
SW7 | F12 | nrsk:SW_MX_Hotswap_1.00u | 1
SW8 | 73 | nrsk:SW_MX_Hotswap_1.00u | 1
SW9 | 7 | nrsk:SW_MX_Hotswap_1.00u | 1
SW10 | 8 | nrsk:SW_MX_Hotswap_1.00u | 1
SW11 | 9 | nrsk:SW_MX_Hotswap_1.00u | 1
SW12 | 0 | nrsk:SW_MX_Hotswap_1.00u | 1
SW13 | - | nrsk:SW_MX_Hotswap_1.00u | 1
SW14 | = | nrsk:SW_MX_Hotswap_1.00u | 1
SW15 | Backspace | nrsk:SW_MX_Hotswap_2.00u | 1
SW16 | 75 | nrsk:SW_MX_Hotswap_1.00u | 1
SW17 | Y | nrsk:SW_MX_Hotswap_1.00u | 1
SW18 | U | nrsk:SW_MX_Hotswap_1.00u | 1
SW19 | I | nrsk:SW_MX_Hotswap_1.00u | 1
SW20 | O | nrsk:SW_MX_Hotswap_1.00u | 1
SW21 | P | nrsk:SW_MX_Hotswap_1.00u | 1
SW22 | [ | nrsk:SW_MX_Hotswap_1.00u | 1
SW23 | ] | nrsk:SW_MX_Hotswap_1.00u | 1
SW24 | \ | nrsk:SW_MX_Hotswap_1.50u | 1
SW25 | 77 | nrsk:SW_MX_Hotswap_1.00u | 1
SW26 | H | nrsk:SW_MX_Hotswap_1.00u | 1
SW27 | J | nrsk:SW_MX_Hotswap_1.00u | 1
SW28 | K | nrsk:SW_MX_Hotswap_1.00u | 1
SW29 | L | nrsk:SW_MX_Hotswap_1.00u | 1
SW30 | ; | nrsk:SW_MX_Hotswap_1.00u | 1
SW31 | ' | nrsk:SW_MX_Hotswap_1.00u | 1
SW32 | Enter | nrsk:SW_MX_Hotswap_2.25u | 1
SW33 | 79 | nrsk:SW_MX_Hotswap_1.00u | 1
SW34 | N | nrsk:SW_MX_Hotswap_1.00u | 1
SW35 | M | nrsk:SW_MX_Hotswap_1.00u | 1
SW36 | , | nrsk:SW_MX_Hotswap_1.00u | 1
SW37 | . | nrsk:SW_MX_Hotswap_1.00u | 1
SW38 | / | nrsk:SW_MX_Hotswap_1.00u | 1
SW39 | ↑ | nrsk:SW_MX_Hotswap_1.00u | 1
SW40 | fn | nrsk:SW_MX_Hotswap_1.00u | 1
SW41 | 81 | nrsk:SW_MX_Hotswap_1.00u | 1
SW42,SW43 | Space | nrsk:SW_MX_Hotswap_1.00u | 2
SW44 | Cmd | nrsk:SW_MX_Hotswap_1.25u | 1
SW45 | Opt | nrsk:SW_MX_Hotswap_1.25u | 1
SW46 | ← | nrsk:SW_MX_Hotswap_1.00u | 1
SW47 | ↓ | nrsk:SW_MX_Hotswap_1.00u | 1
SW48 | → | nrsk:SW_MX_Hotswap_1.00u | 1
U1 | RP2040 | Package_DFN_QFN:QFN-56-1EP_7x7mm_P0.4mm_EP3.2x3.2mm | 1
U2 | USBLC6-2SC6 | Package_TO_SOT_SMD:SOT-23-6 | 1
U4 | AP2112K-3.3 | Package_TO_SOT_SMD:SOT-23-5 | 1
U5 | W25Q128JVS | Package_SO:SOIC-8_5.3x5.3mm_P1.27mm | 1
Y1 | 12MHz | Crystal:Crystal_SMD_3225-4Pin_3.2x2.5mm_HandSoldering | 1

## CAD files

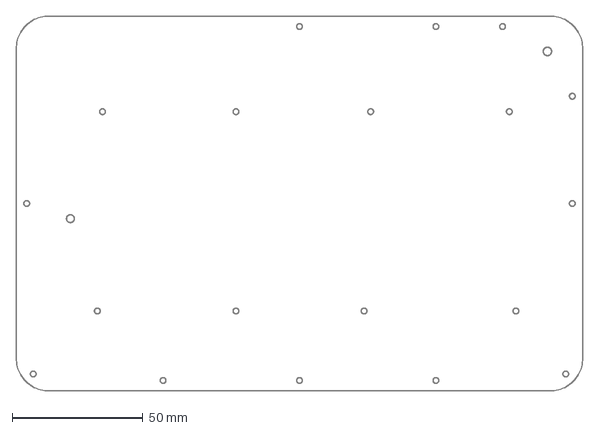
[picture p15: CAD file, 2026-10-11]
case/laser/right-bottom.dxf
216.6 x 143.3 mm

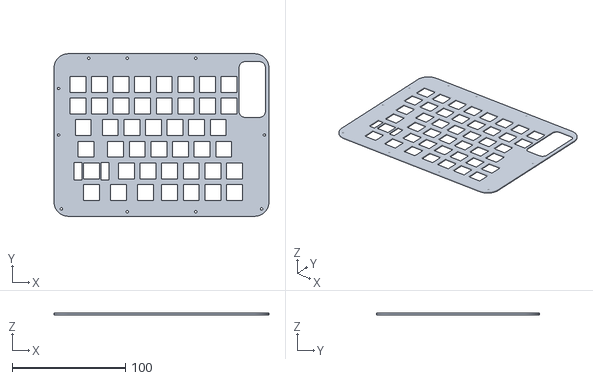
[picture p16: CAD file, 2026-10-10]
case/preview/left-plate-placed.stl
189.6 x 143.3 x 1.50

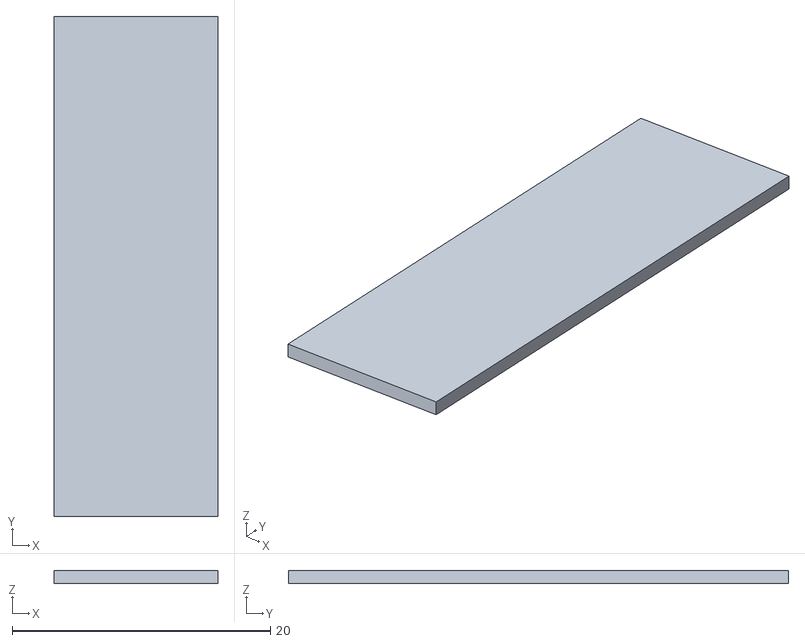
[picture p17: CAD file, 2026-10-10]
case/preview/oled-variants/left-lens-0.stl
12.7 x 38.7 x 1.00

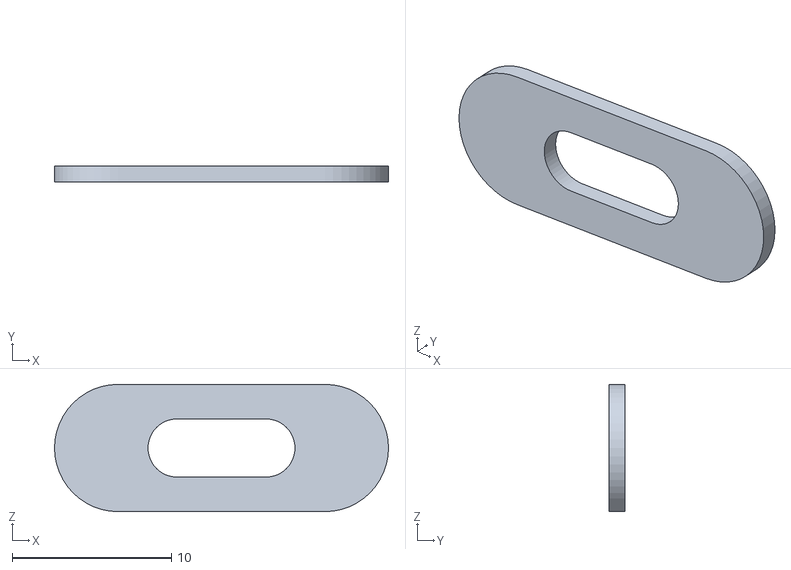
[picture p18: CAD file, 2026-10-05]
case/preview/port-variants/left-panel-flange.stl
21.0 x 1.00 x 8.00

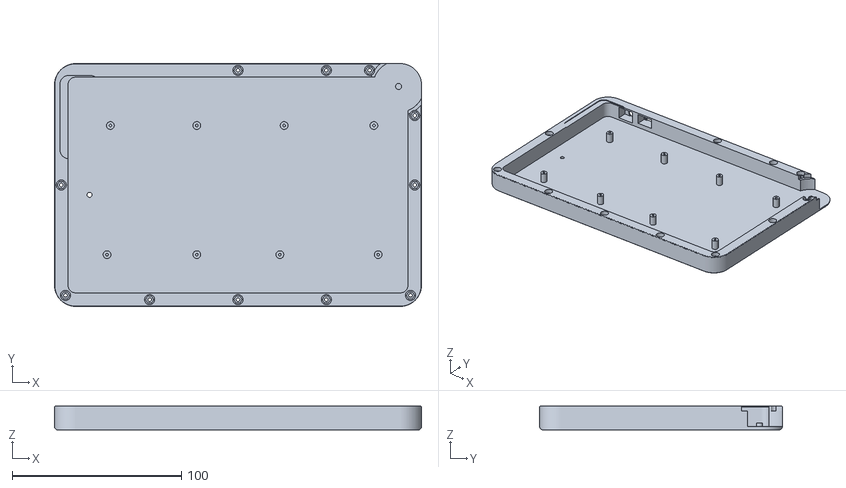
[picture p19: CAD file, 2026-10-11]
case/print/right-tray.stl
216.6 x 143.3 x 14.1

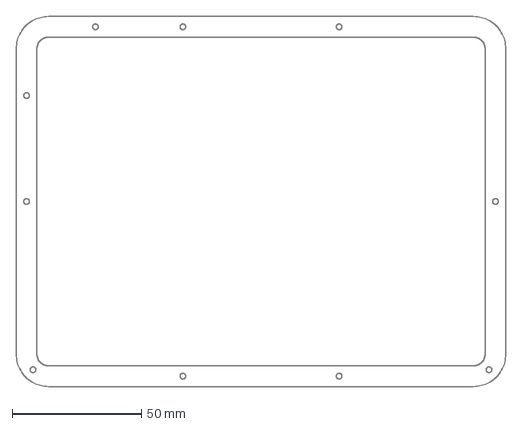
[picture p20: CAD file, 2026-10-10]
case/laser/left-frame4.dxf
189.6 x 143.3 mm

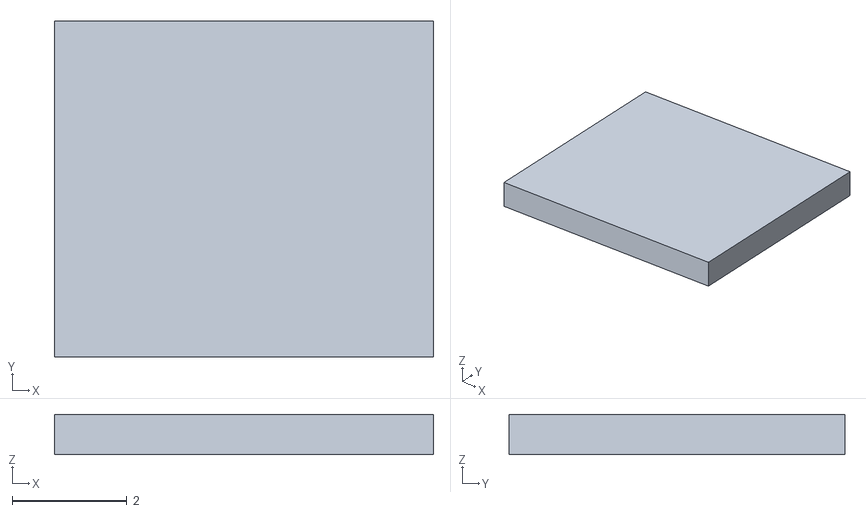
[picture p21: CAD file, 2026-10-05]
case/preview/port-variants/left-stepped-tongue.stl
6.60 x 5.85 x 0.7

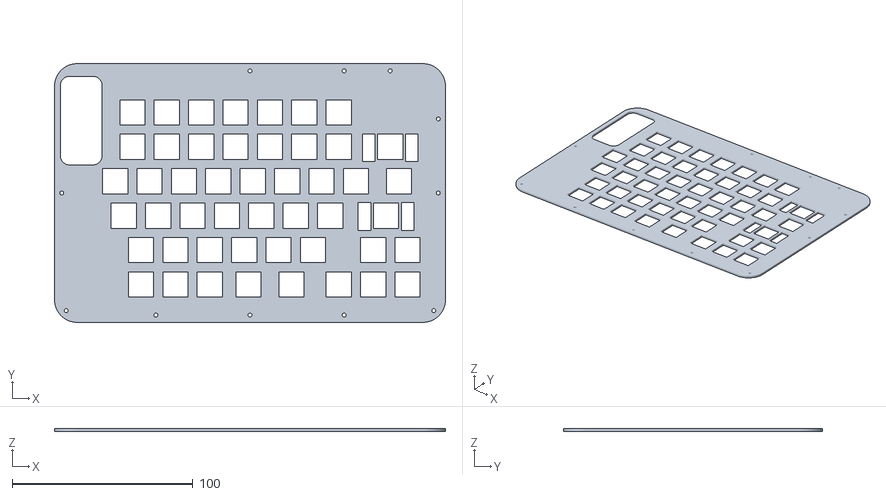
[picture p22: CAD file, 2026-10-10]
case/preview/right-plate-placed.stl
216.6 x 143.3 x 1.50

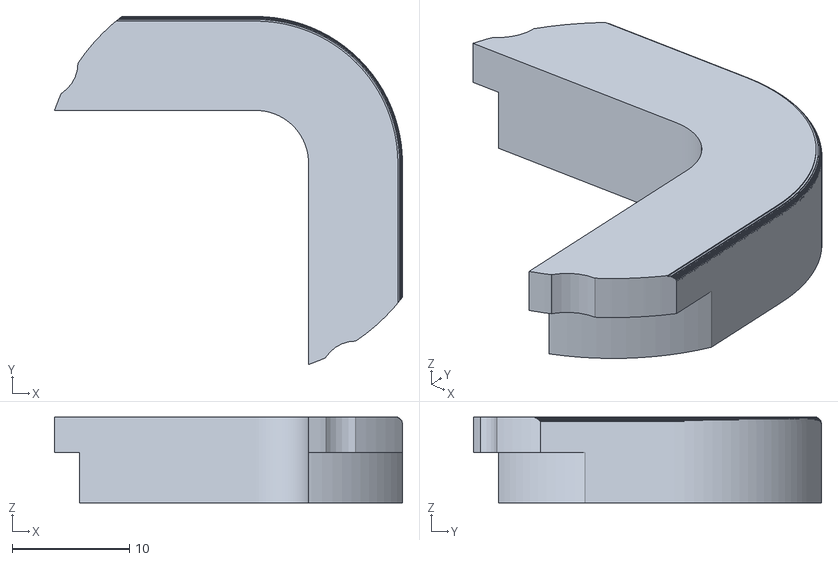
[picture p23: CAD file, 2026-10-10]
case/print/right-wheel-cap.stl
29.6 x 29.6 x 7.30

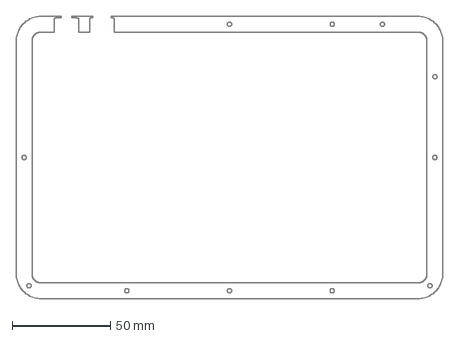
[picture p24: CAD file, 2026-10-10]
case/laser/right-frame3.dxf
216.6 x 143.3 mm

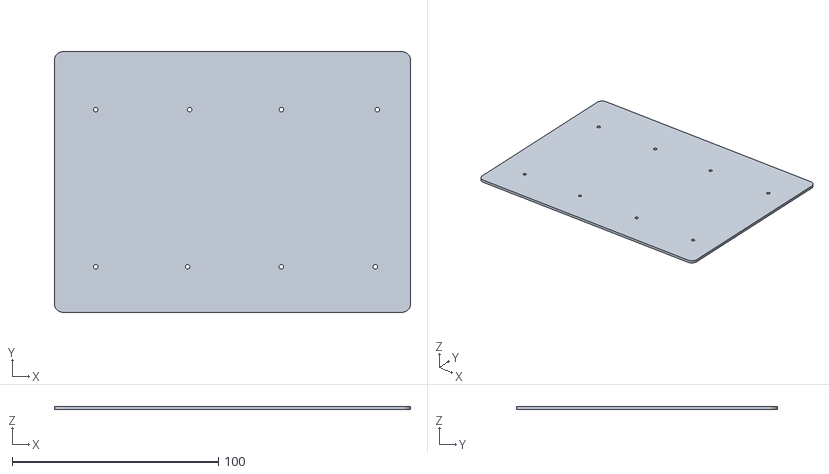
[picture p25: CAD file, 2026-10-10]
case/preview/left-pcb.stl
172.6 x 126.3 x 1.60

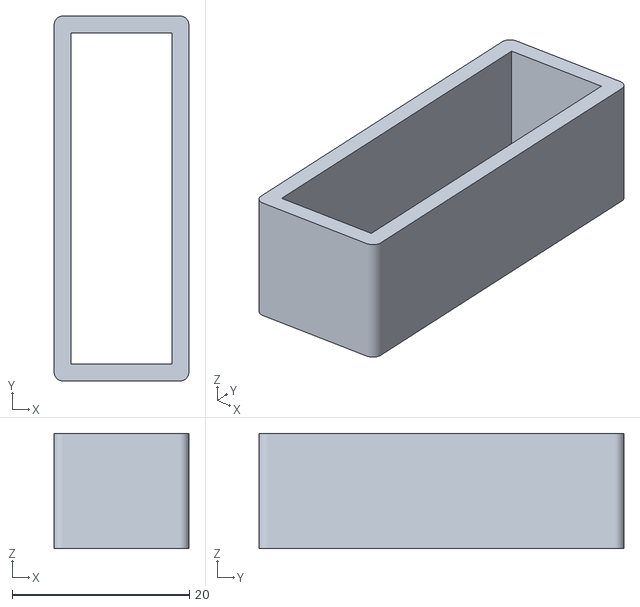
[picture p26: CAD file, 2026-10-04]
case/preview/oled-variants/right-pod-13.stl
15.2 x 41.2 x 13.0

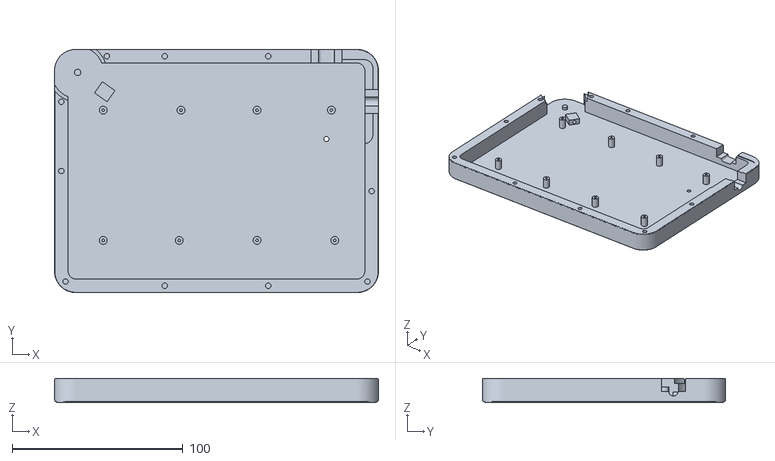
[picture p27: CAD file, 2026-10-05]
case/preview/port-variants/left-flush-case.stl
189.6 x 142.3 x 14.1

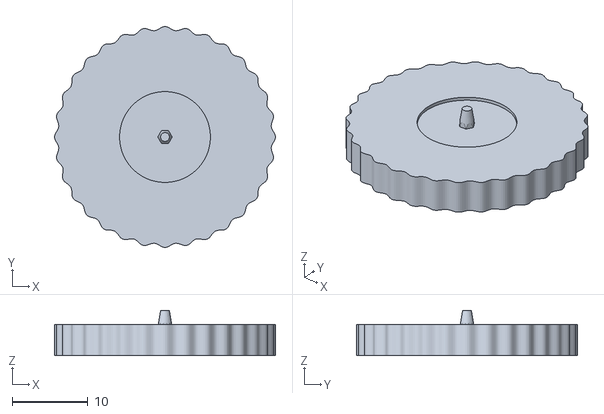
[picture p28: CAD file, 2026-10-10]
case/print/right-wheel.stl
29.2 x 29.2 x 6.00

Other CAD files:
case/preview/oled-variants/right-lens-0.stl
case/laser/left-frame3.dxf
case/preview/oled-variants/right-lens-tilt-h.stl
case/preview/port-variants/left-panel-heads.stl
case/laser/left-bottom.dxf
case/laser/left-frame1.dxf
case/laser/left-frame2.dxf
case/laser/left-oled-cover.dxf
case/laser/left-plate.dxf
case/laser/right-frame1.dxf
case/laser/right-frame2.dxf
case/laser/right-frame4.dxf
case/laser/right-oled-cover.dxf
case/laser/right-plate.dxf
case/preview/left-oled-cover.stl
case/preview/oled-variants/left-lens-13.stl
case/preview/oled-variants/left-lens-3.5.stl
case/preview/oled-variants/left-lens-6.5.stl
case/preview/oled-variants/left-lens-tilt-h.stl
case/preview/oled-variants/left-lens-tilt-v.stl
case/preview/oled-variants/left-pod-13.stl
case/preview/oled-variants/left-pod-3.5.stl
case/preview/oled-variants/left-pod-6.5.stl
case/preview/oled-variants/left-pod-tilt-h.stl
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

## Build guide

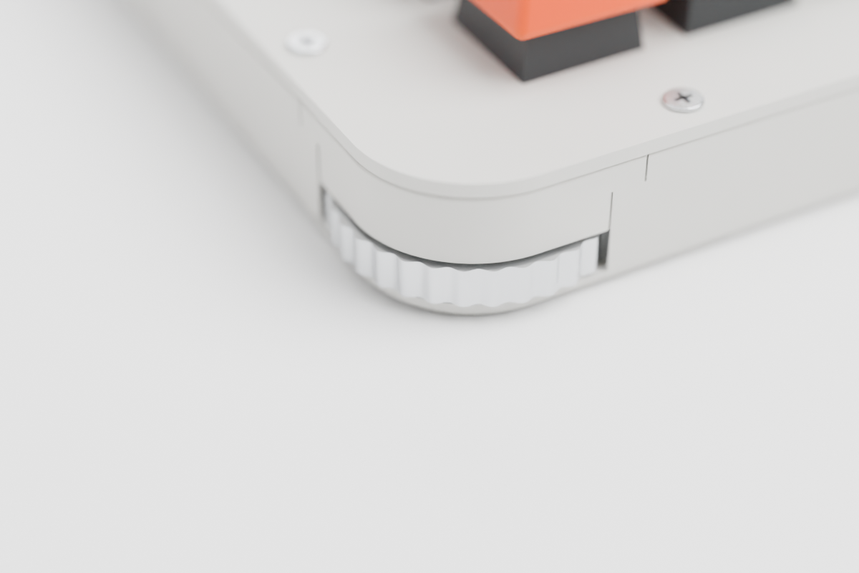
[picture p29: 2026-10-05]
docs/img/render-wheel-left-top-print-lowpan.png

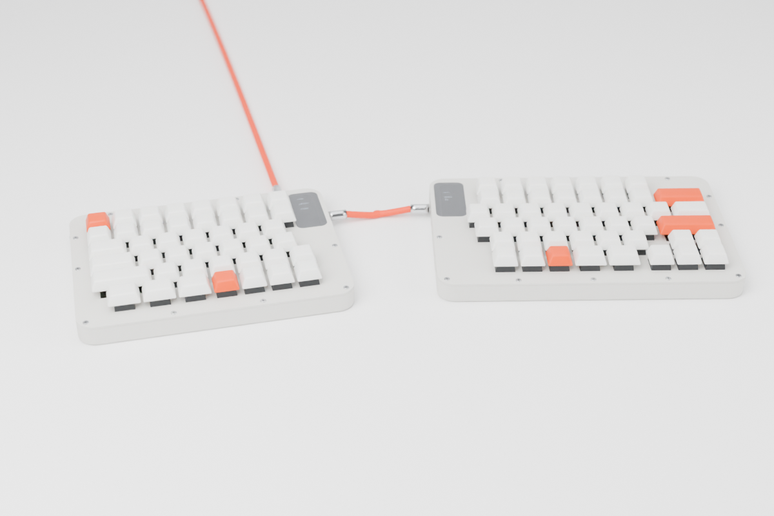
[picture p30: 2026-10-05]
docs/img/render-hero-top-print-lowpan.png

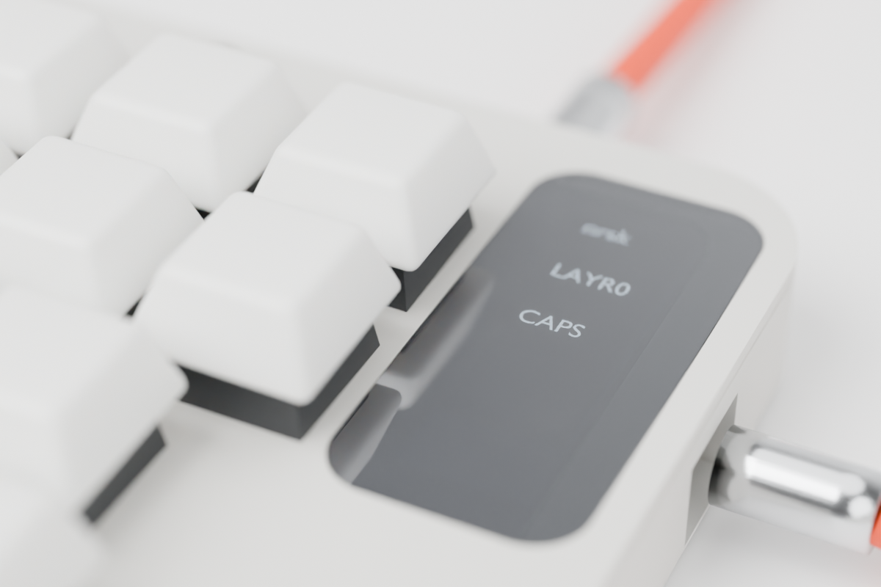
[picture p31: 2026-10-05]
docs/img/render-oled-top-print-flat.png

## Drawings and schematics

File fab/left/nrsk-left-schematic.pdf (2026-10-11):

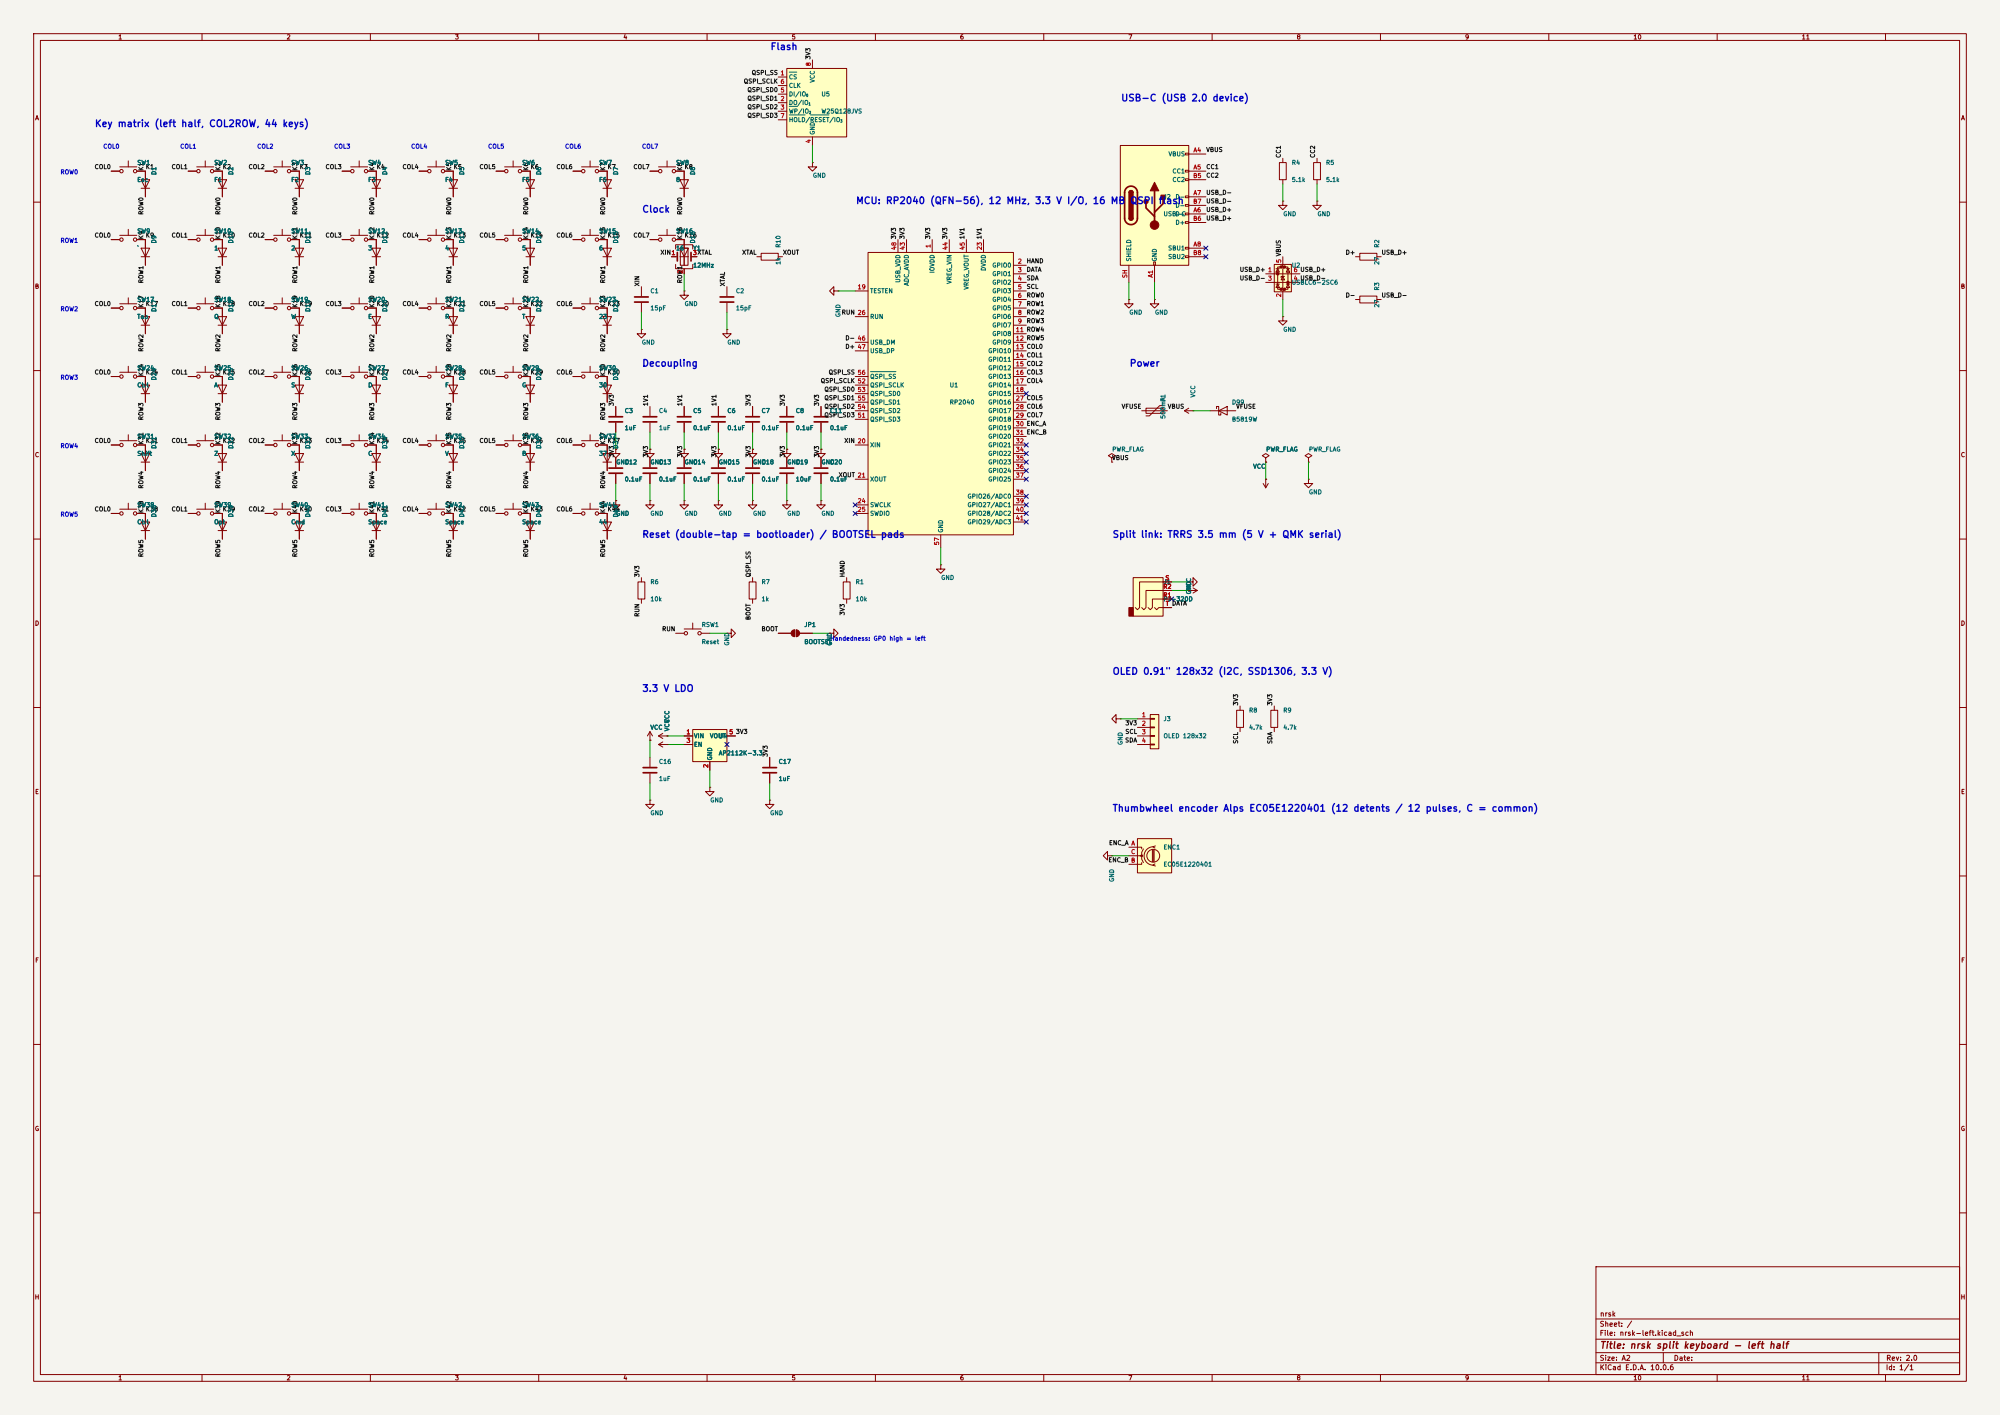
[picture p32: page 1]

4 DI/IO0 5 CLK 6 HOLD/RESET/IO3 7 VCC

Key matrix (left half, COL2ROW, 44 keys)

Thumbwheel encoder Alps EC05E1220401 (12 detents / 12 pulses, C = common)

nrsk
Sheet: /
File: nrsk-left.kicad_sch
Title: nrsk split keyboard - left half

Size: A2 | Rev: 2.0
KiCad E.D.A. 10.0.6 | Id: 1/1

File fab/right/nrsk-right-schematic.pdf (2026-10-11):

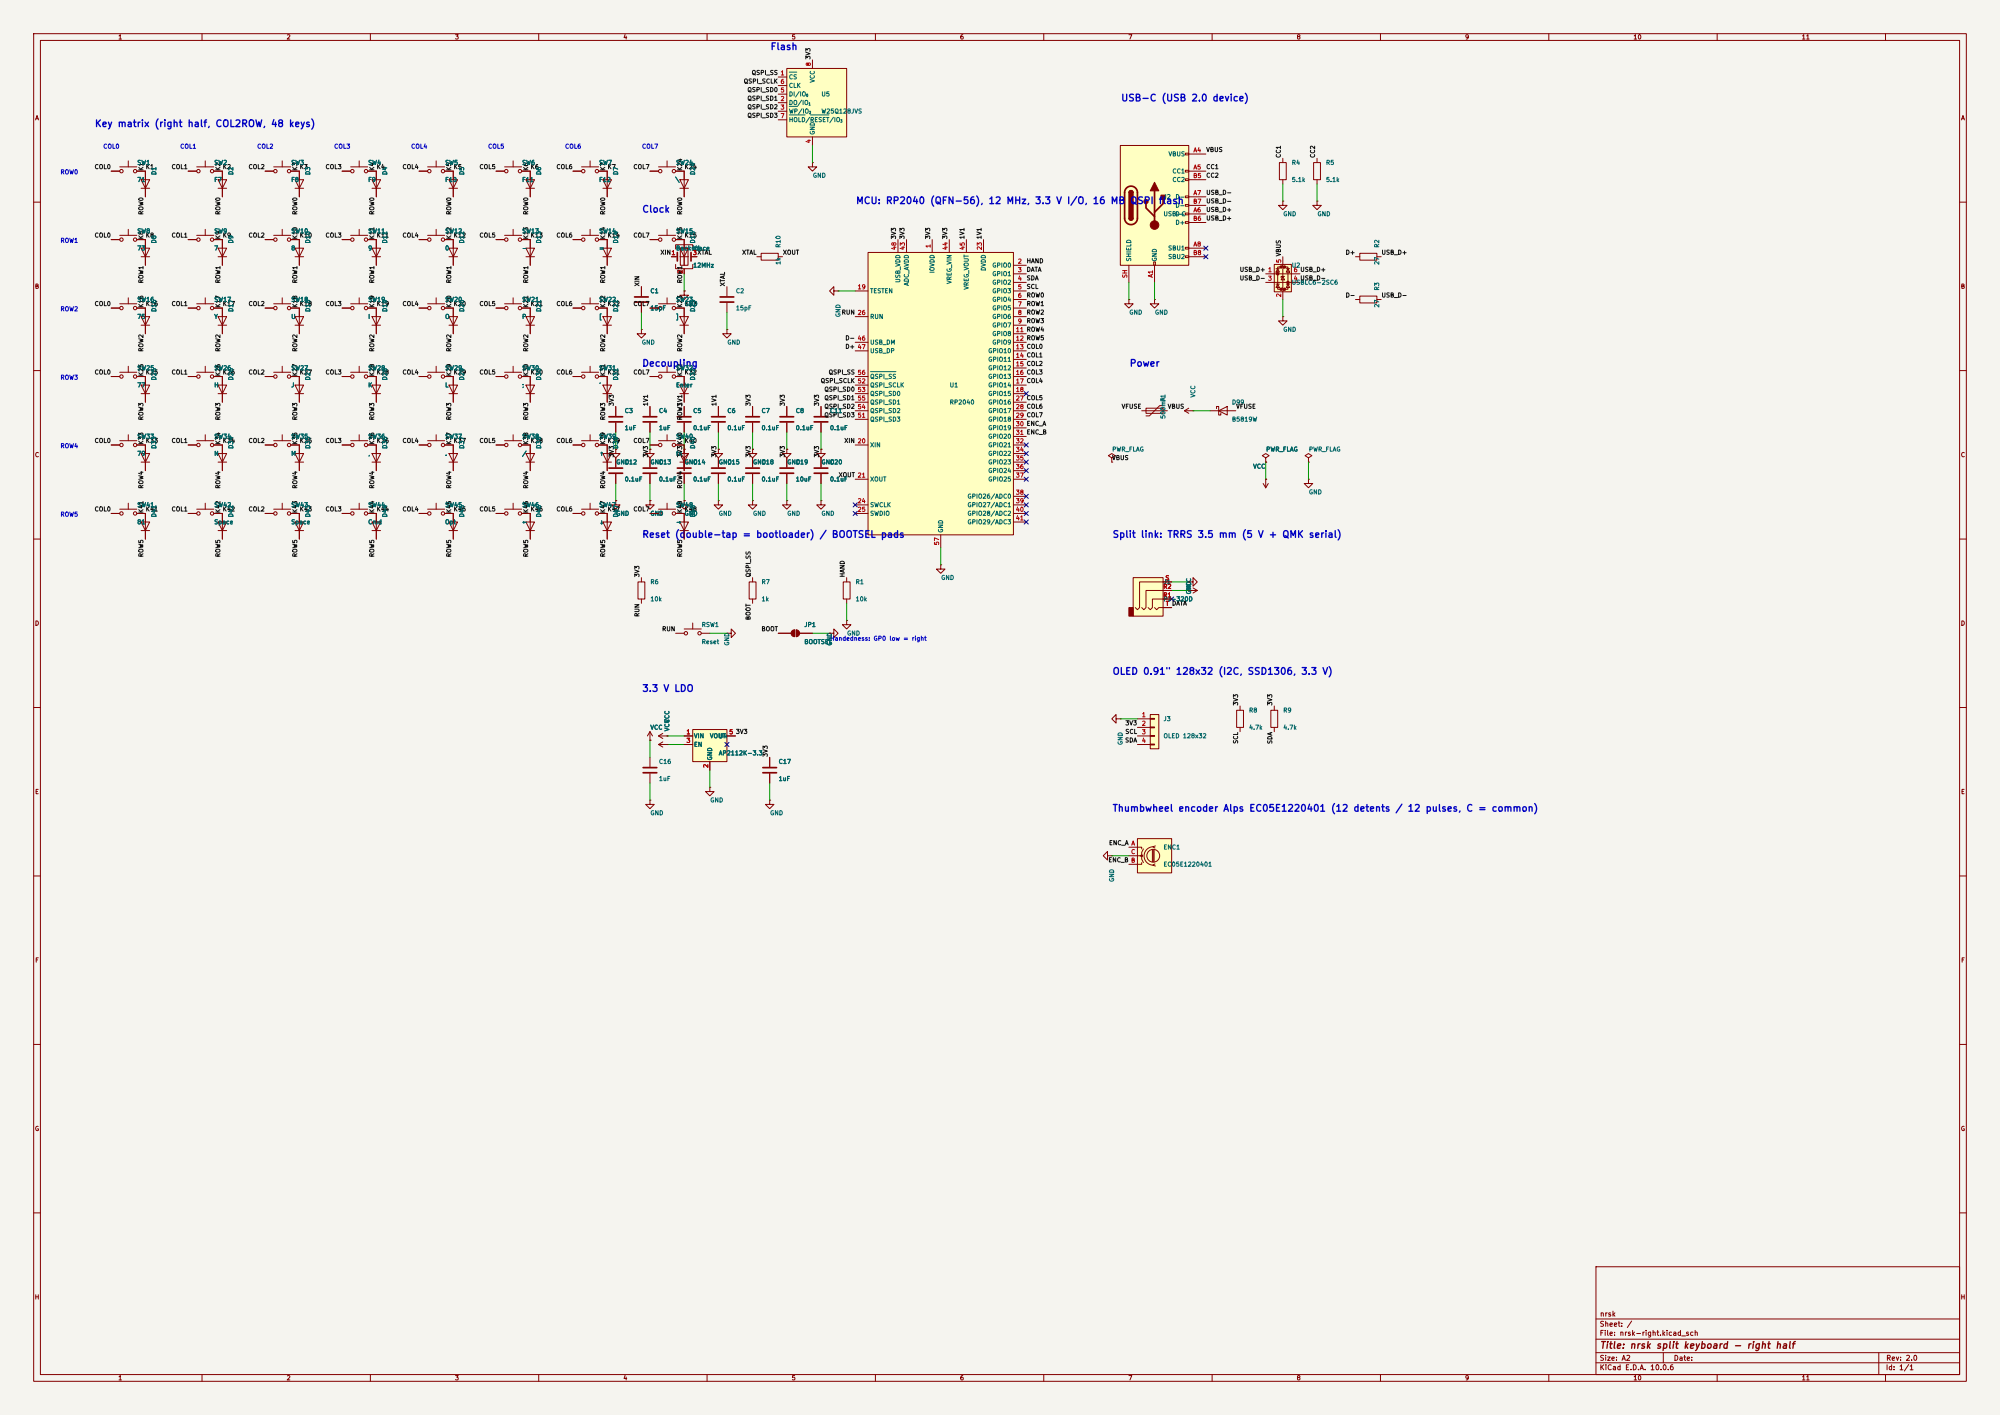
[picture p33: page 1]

4 DI/IO0 5 CLK 6 HOLD/RESET/IO3 7 VCC

Key matrix (right half, COL2ROW, 48 keys)

GND
Reset (double-tap = bootloader) / BOOTSEL pads

Split link: TRRS 3.5 mm (5 V + QMK serial)

nrsk
Sheet: /
File: nrsk-right.kicad_sch
Title: nrsk split keyboard - right half

Size: A2 | Rev: 2.0
KiCad E.D.A. 10.0.6 | Id: 1/1

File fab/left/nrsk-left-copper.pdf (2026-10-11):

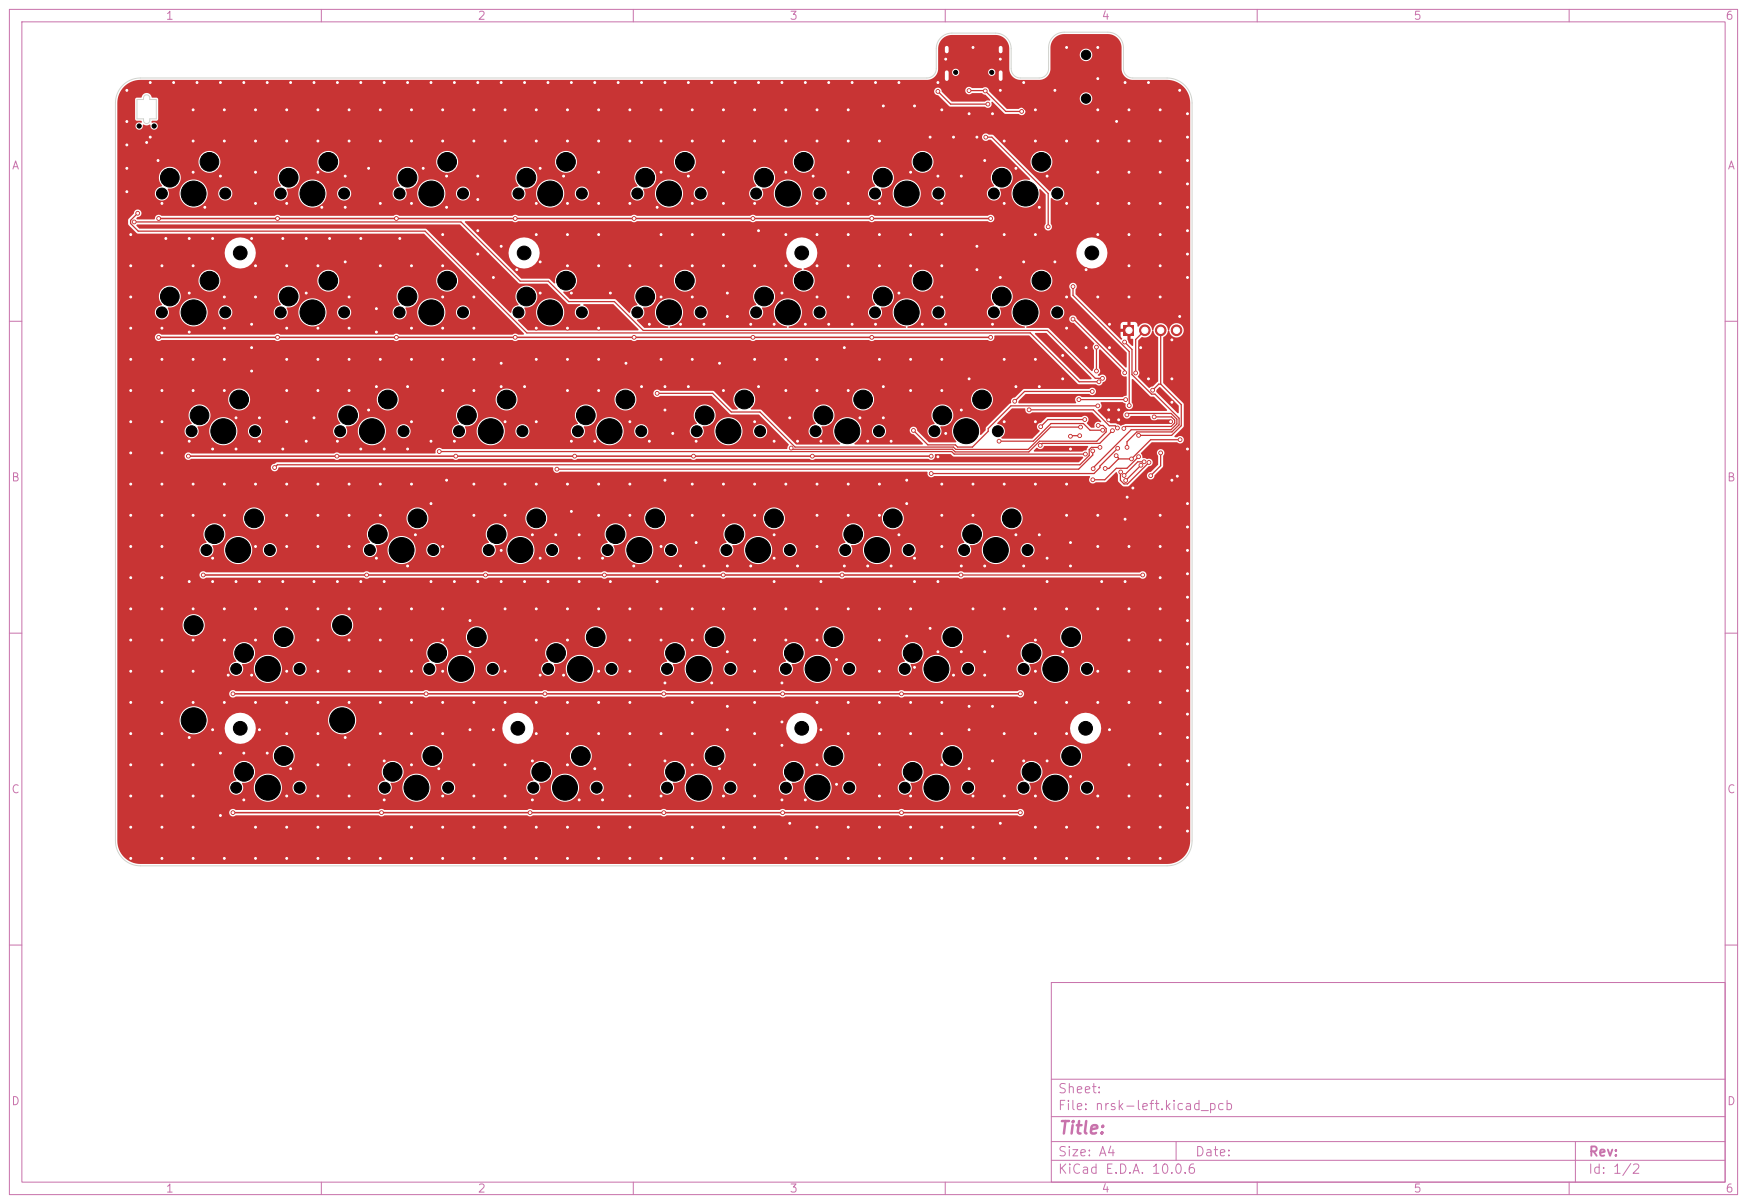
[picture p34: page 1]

Size: A4 | Rev:
KiCad E.D.A. 10.0.6 | Id: 1/2

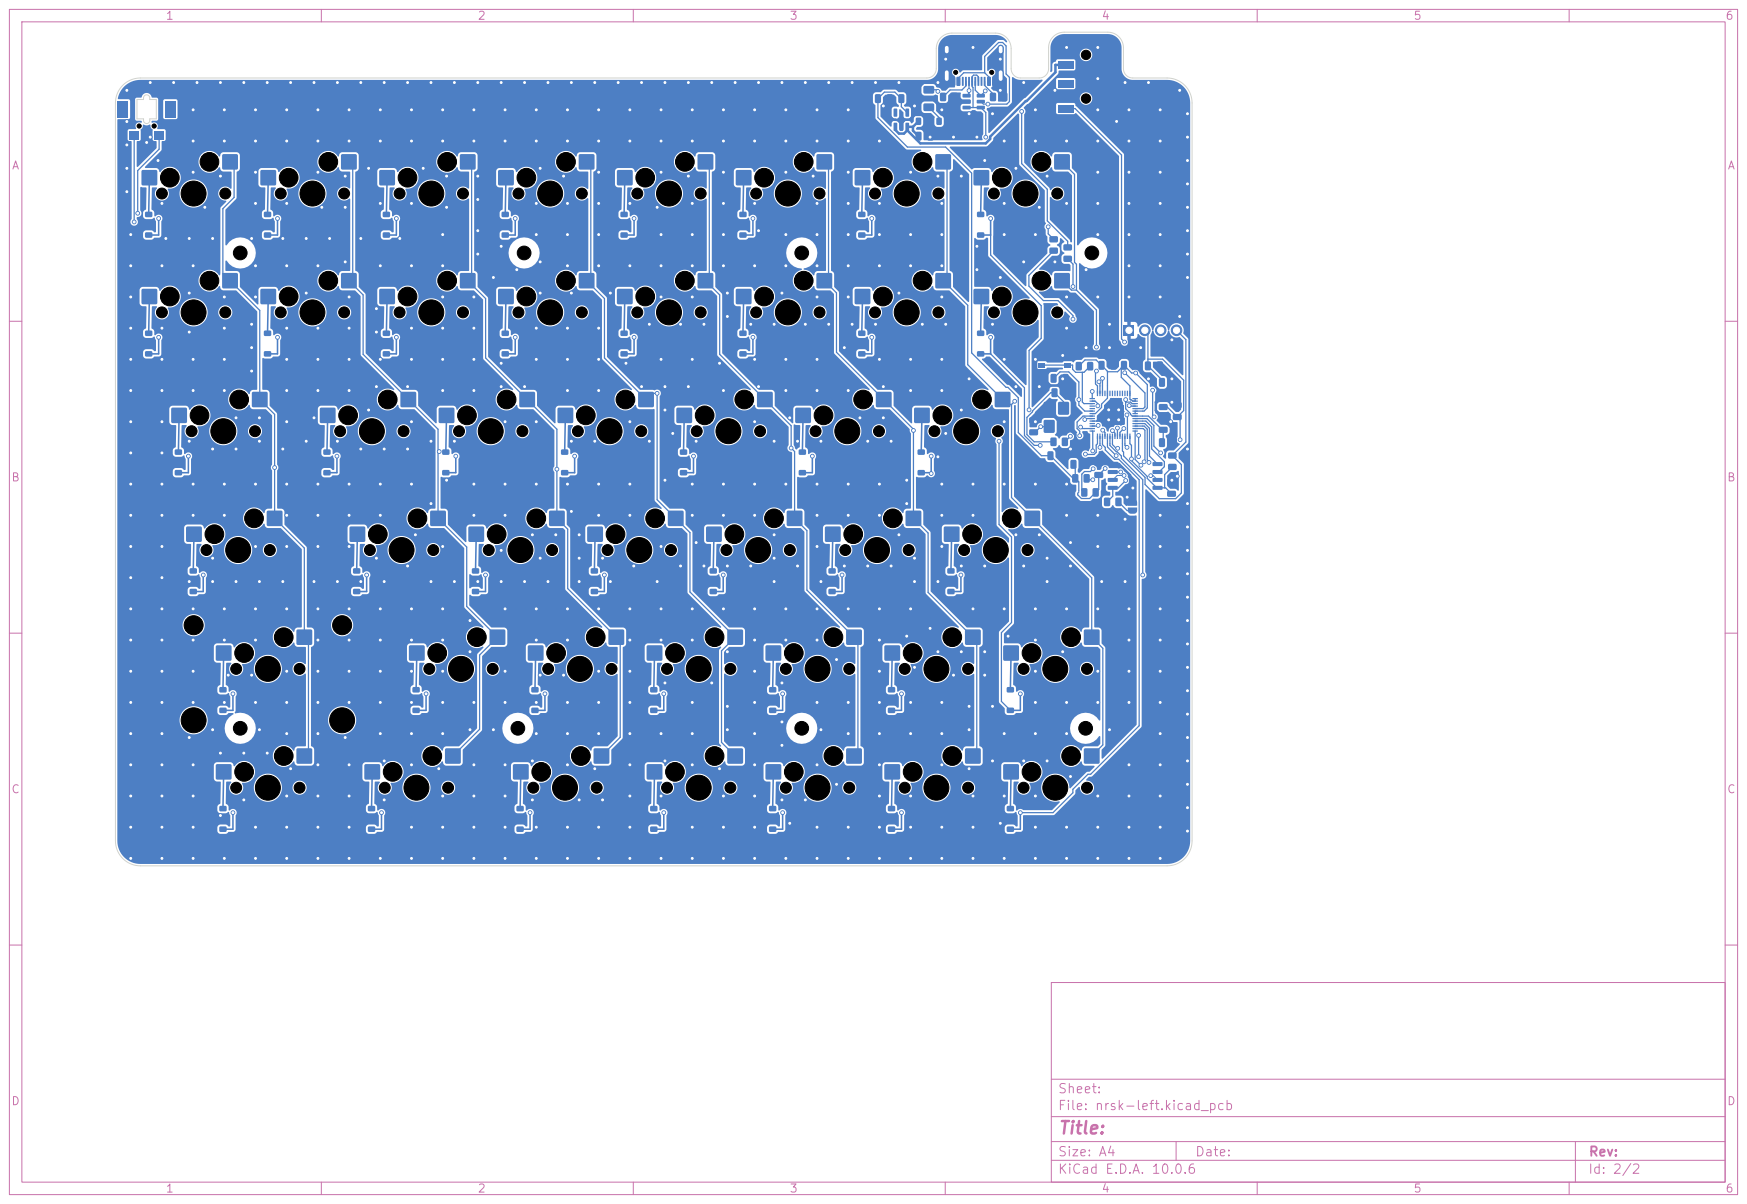
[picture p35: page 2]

Size: A4 | Rev:
KiCad E.D.A. 10.0.6 | Id: 2/2

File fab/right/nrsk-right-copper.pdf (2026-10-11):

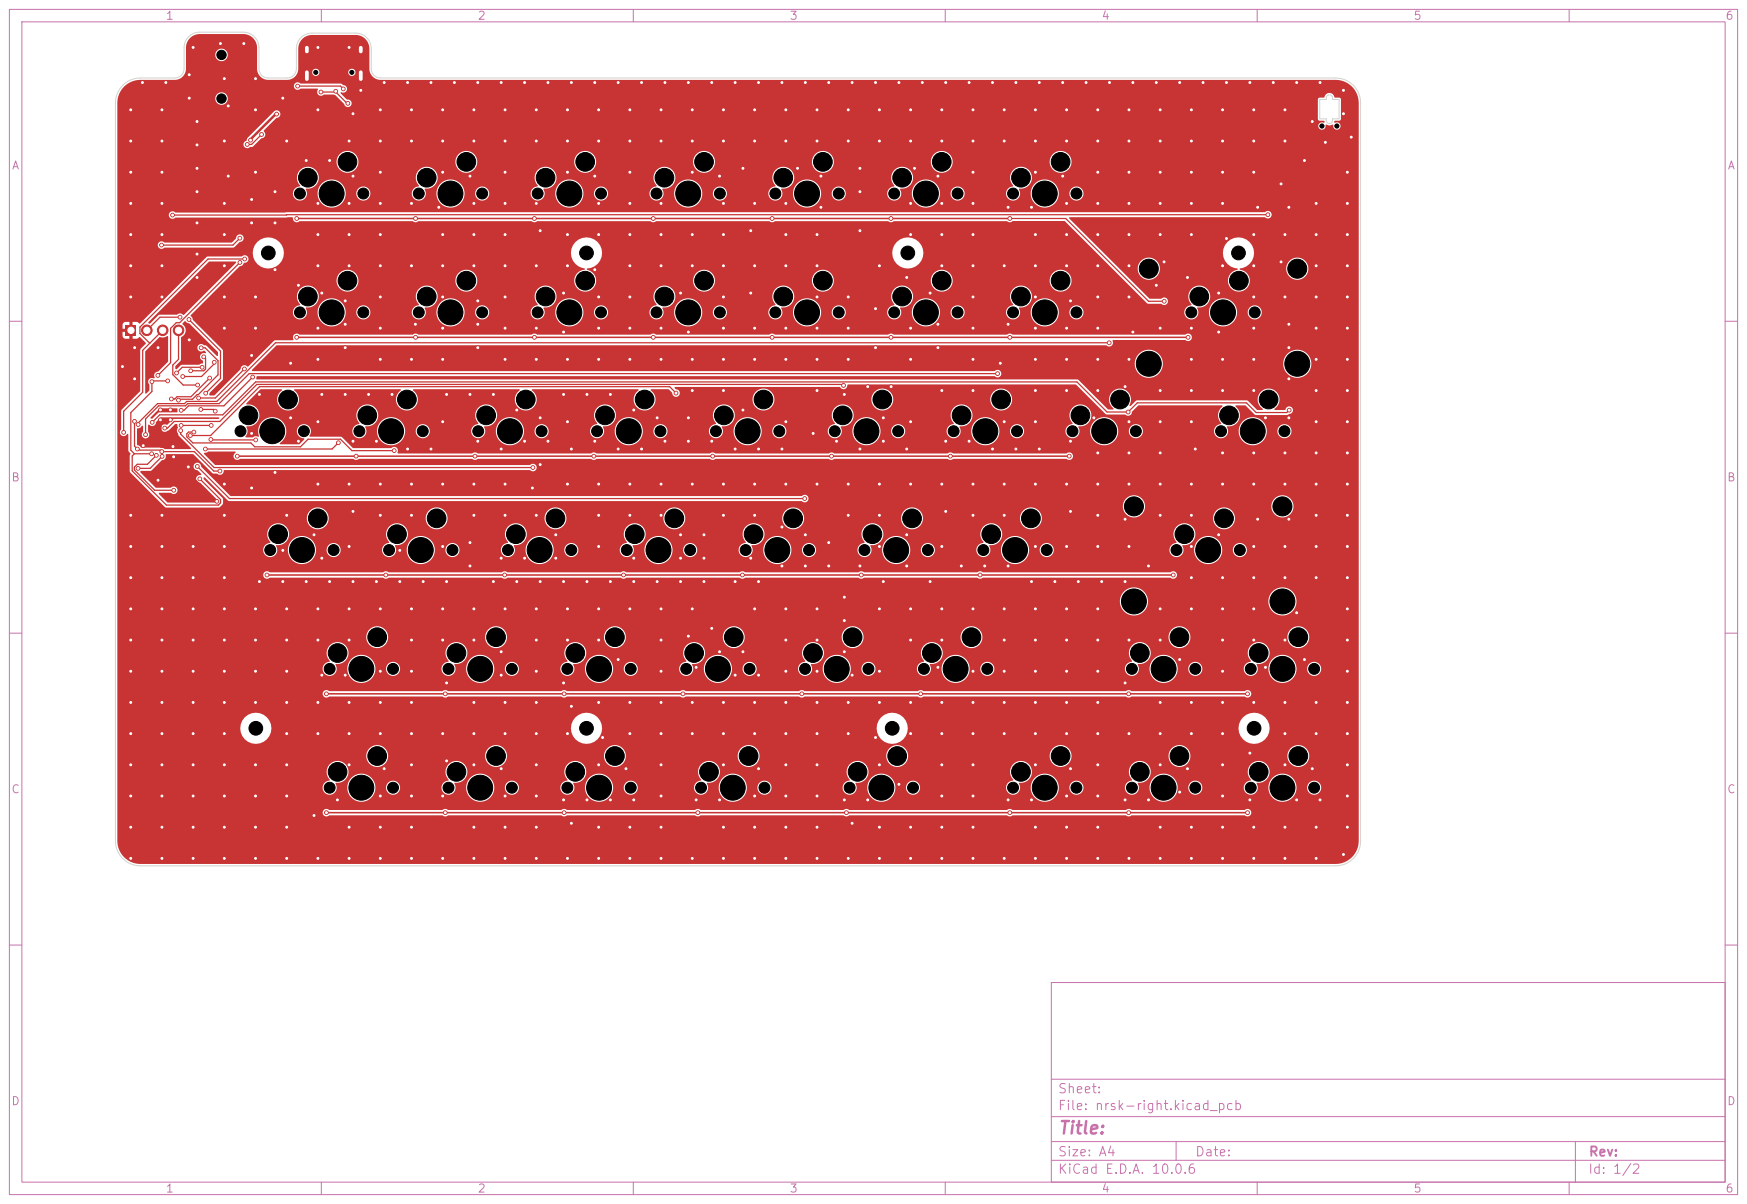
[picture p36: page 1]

Size: A4 | Rev:
KiCad E.D.A. 10.0.6 | Id: 1/2

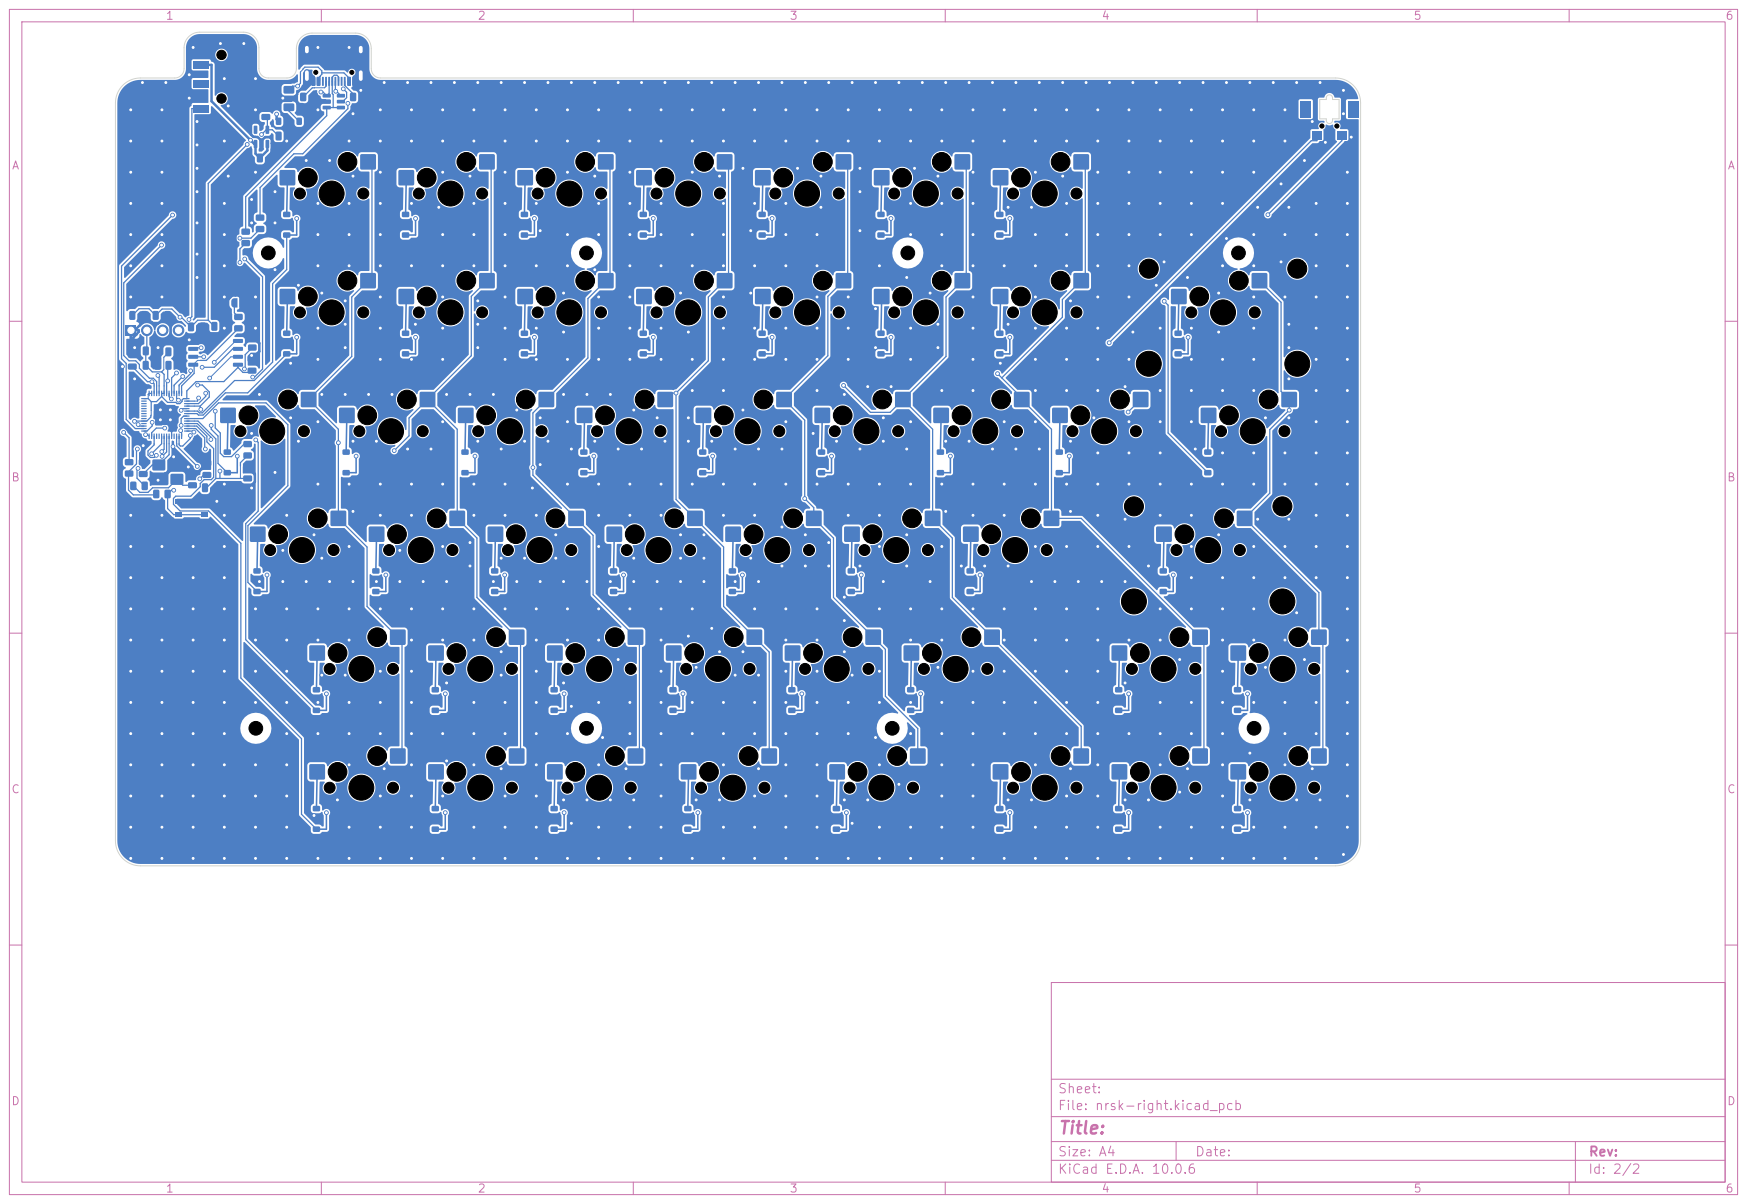
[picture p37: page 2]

Size: A4 | Rev:
KiCad E.D.A. 10.0.6 | Id: 2/2

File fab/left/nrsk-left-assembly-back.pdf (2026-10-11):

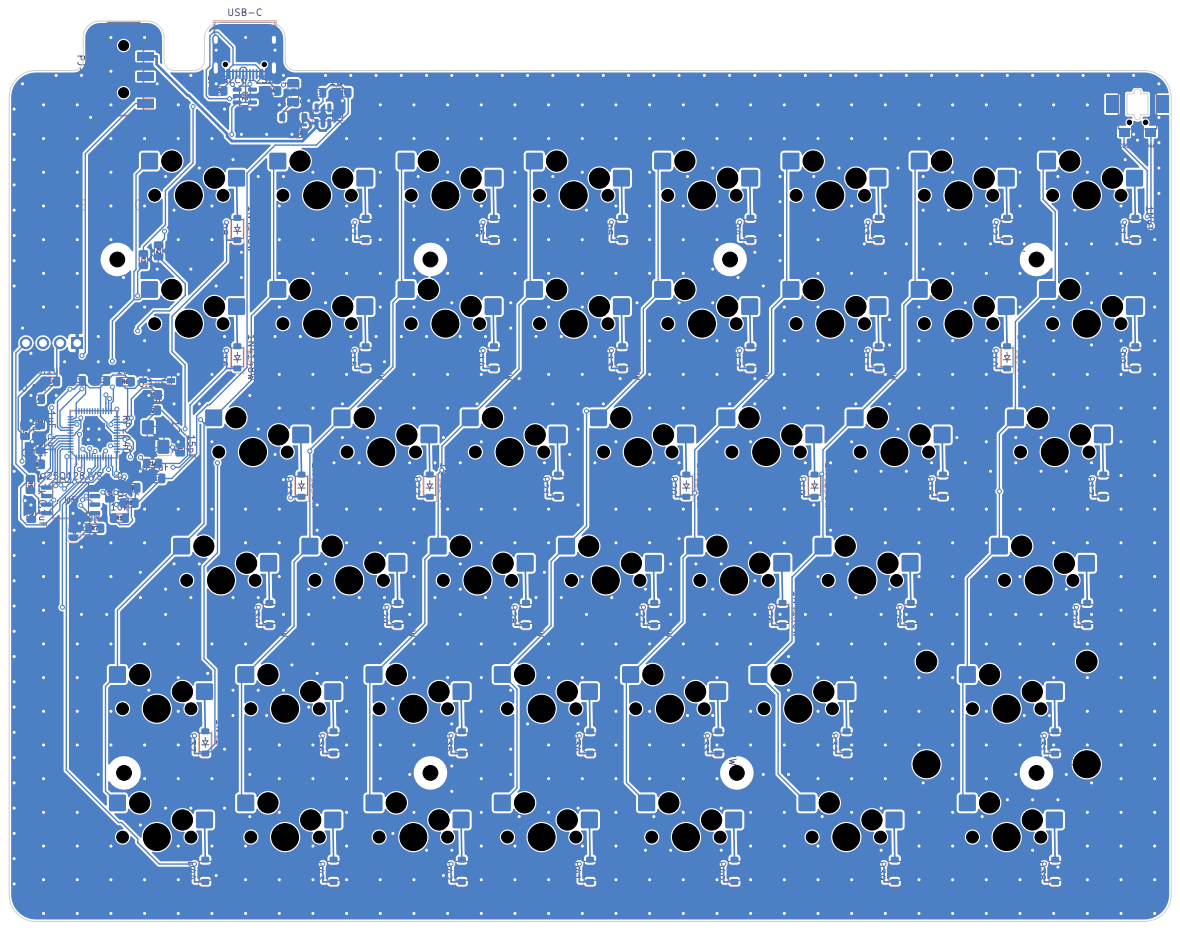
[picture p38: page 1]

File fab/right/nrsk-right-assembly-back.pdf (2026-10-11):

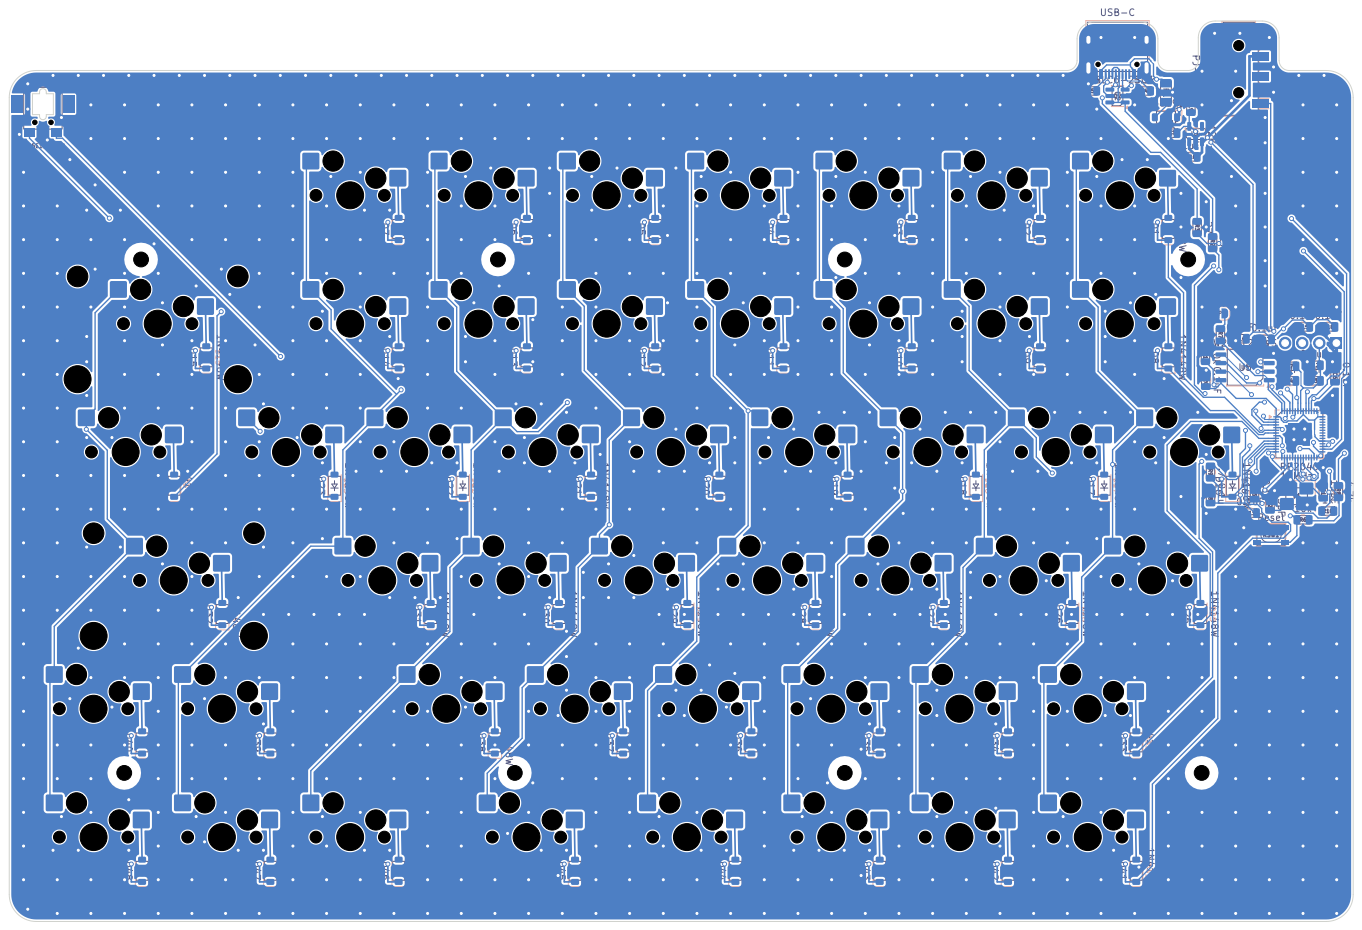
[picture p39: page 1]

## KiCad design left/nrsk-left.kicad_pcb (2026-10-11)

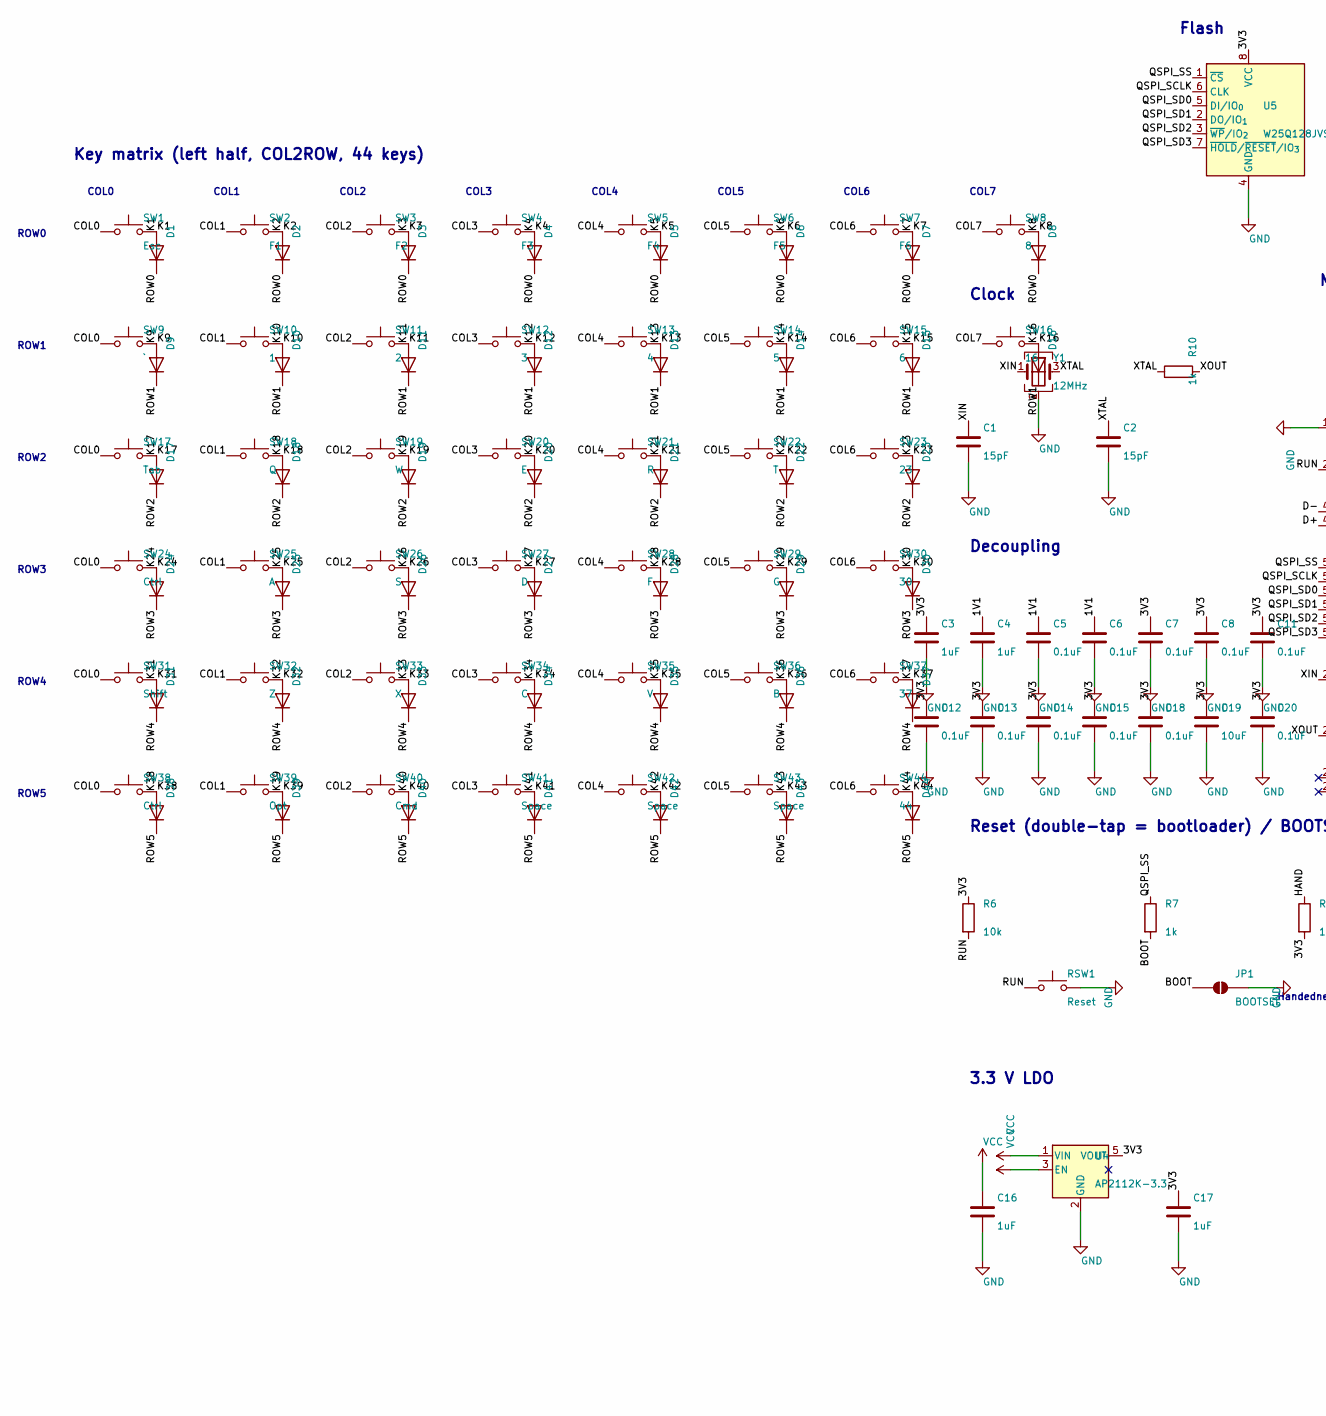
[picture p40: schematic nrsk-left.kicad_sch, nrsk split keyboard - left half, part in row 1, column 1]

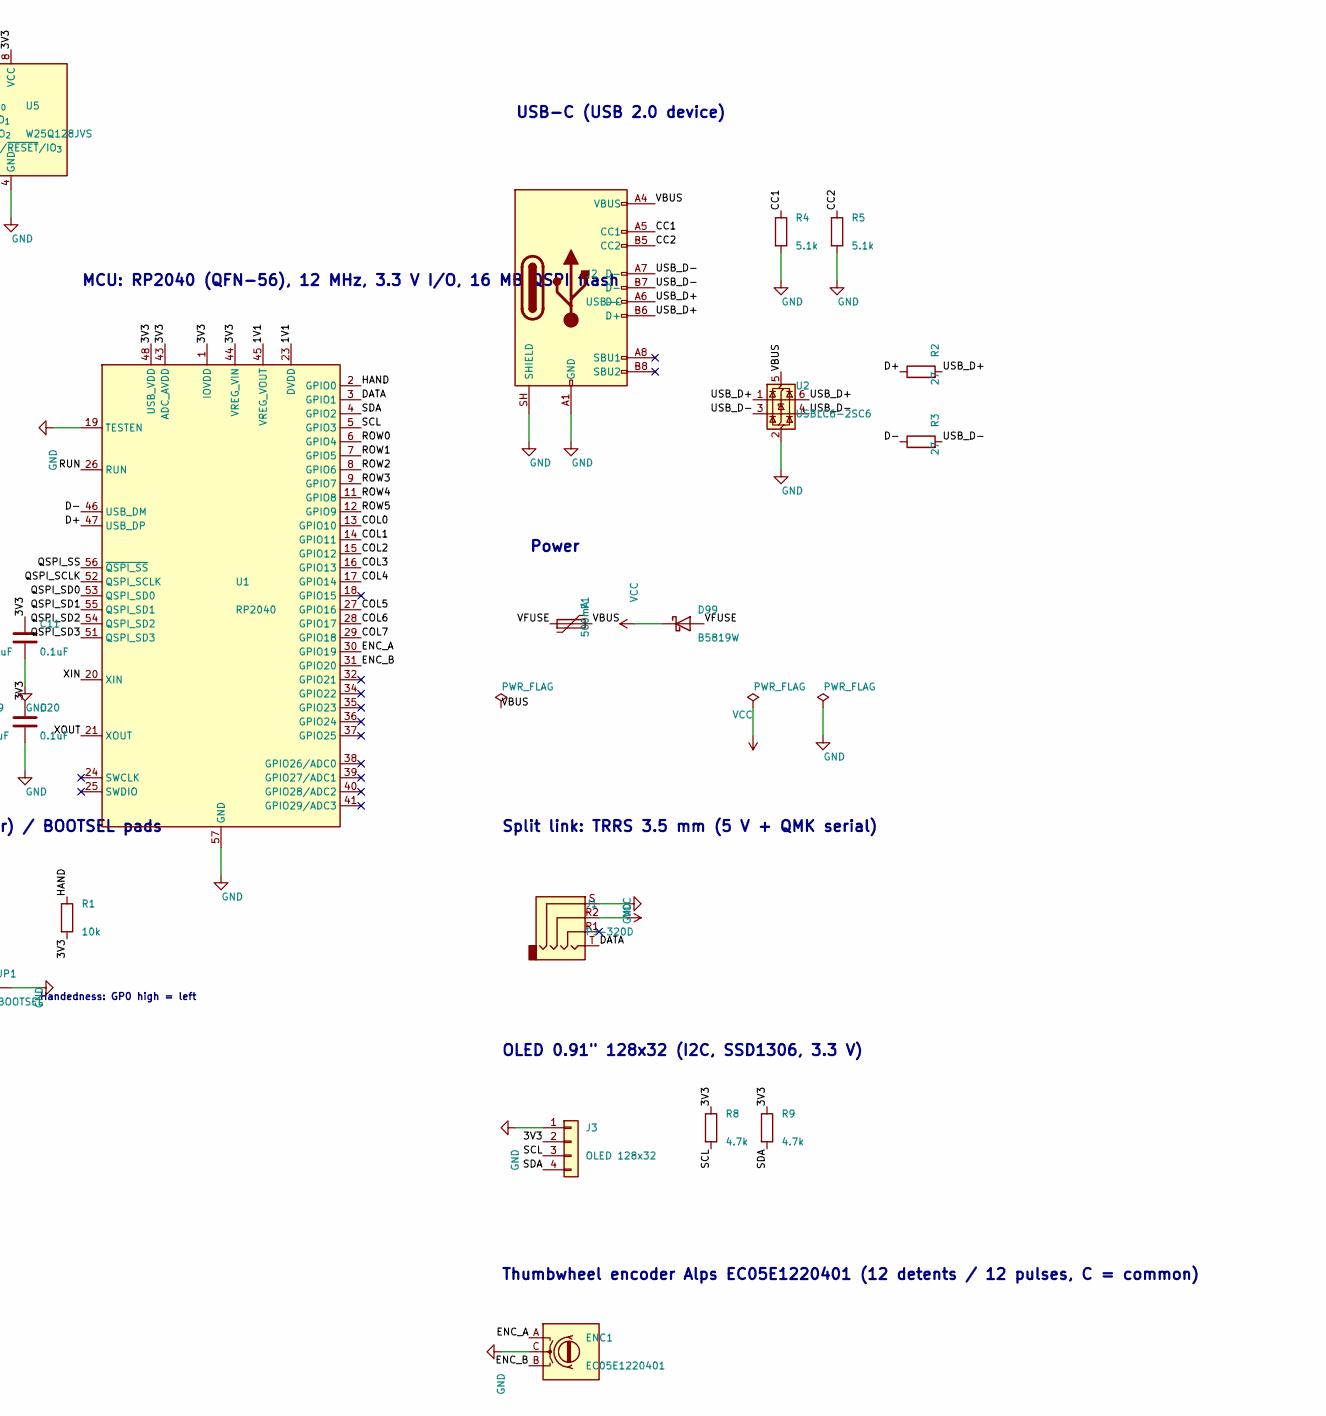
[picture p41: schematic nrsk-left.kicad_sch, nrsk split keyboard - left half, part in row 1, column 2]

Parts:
C1, C2: 15pF; C_0805_2012Metric
C3, C4, C16, C17: 1uF; C_0805_2012Metric
C5, C6, C7, C8, C11, C12, C13, C14, C15, C18, C20: 0.1uF; C_0805_2012Metric
C19: 10uF; C_0805_2012Metric
D1, D2, D3, D4, D5, D6, D7, D8, D9, D10, D11, D12, D13, D14, D15, D16, D17, D18, D19, D20, D21, D22, D23, D24, D25, D26, D27, D28, D29, D30, D31, D32, D33, D34, D35, D36, D37, D38, D39, D40, D41, D42, D43, D44: 1N4148W; D_SOD-123
D99: B5819W; D_SOD-123
ENC1: EC05E1220401; Alps_EC05E1220401
F1: 500mA; Fuse_1206_3216Metric
J1: PJ-320D; Jack_3.5mm_PJ320D_Horizontal
J2: USB-C; USB_C_Receptacle_HRO_TYPE-C-31-M-12
J3: OLED 128x32; OLED_0.91in_128x32_I2C
JP1: BOOTSEL; SolderJumper-2_P1.3mm_Open_RoundedPad1.0x1.5mm
R1, R6: 10k; R_0805_2012Metric
R2, R3: 27; R_0805_2012Metric
R4, R5: 5.1k; R_0805_2012Metric
R7, R10: 1k; R_0805_2012Metric
R8, R9: 4.7k; R_0805_2012Metric
RSW1: Reset; SW_SPST_PTS810
SW1: Esc; SW_MX_Hotswap_1.00u
SW2: F1; SW_MX_Hotswap_1.00u
SW3: F2; SW_MX_Hotswap_1.00u
SW4: F3; SW_MX_Hotswap_1.00u
SW5: F4; SW_MX_Hotswap_1.00u
SW6: F5; SW_MX_Hotswap_1.00u
SW7: F6; SW_MX_Hotswap_1.00u
SW8: 8; SW_MX_Hotswap_1.00u
SW9: `; SW_MX_Hotswap_1.00u
SW10: 1; SW_MX_Hotswap_1.00u
SW11: 2; SW_MX_Hotswap_1.00u
SW12: 3; SW_MX_Hotswap_1.00u
SW13: 4; SW_MX_Hotswap_1.00u
SW14: 5; SW_MX_Hotswap_1.00u
SW15: 6; SW_MX_Hotswap_1.00u
SW16: 16; SW_MX_Hotswap_1.00u
SW17: Tab; SW_MX_Hotswap_1.50u
SW18: Q; SW_MX_Hotswap_1.00u
SW19: W; SW_MX_Hotswap_1.00u
SW20: E; SW_MX_Hotswap_1.00u
SW21: R; SW_MX_Hotswap_1.00u
SW22: T; SW_MX_Hotswap_1.00u
SW23: 23; SW_MX_Hotswap_1.00u
SW24: Ctrl; SW_MX_Hotswap_1.75u
SW25: A; SW_MX_Hotswap_1.00u
SW26: S; SW_MX_Hotswap_1.00u
SW27: D; SW_MX_Hotswap_1.00u
SW28: F; SW_MX_Hotswap_1.00u
SW29: G; SW_MX_Hotswap_1.00u
SW30: 30; SW_MX_Hotswap_1.00u
SW31: Shift; SW_MX_Hotswap_2.25u
SW32: Z; SW_MX_Hotswap_1.00u
SW33: X; SW_MX_Hotswap_1.00u
SW34: C; SW_MX_Hotswap_1.00u
SW35: V; SW_MX_Hotswap_1.00u
SW36: B; SW_MX_Hotswap_1.00u
SW37: 37; SW_MX_Hotswap_1.00u
SW38: Ctrl; SW_MX_Hotswap_1.25u
SW39: Opt; SW_MX_Hotswap_1.25u
SW40: Cmd; SW_MX_Hotswap_1.25u
SW41, SW42, SW43: Space; SW_MX_Hotswap_1.00u
SW44: 44; SW_MX_Hotswap_1.00u
U1: RP2040; QFN-56-1EP_7x7mm_P0.4mm_EP3.2x3.2mm
U2: USBLC6-2SC6; SOT-23-6
U4: AP2112K-3.3; SOT-23-5
U5: W25Q128JVS; SOIC-8_5.3x5.3mm_P1.27mm
Y1: 12MHz; Crystal_SMD_3225-4Pin_3.2x2.5mm_HandSoldering

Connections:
/1V1: C4.1, C5.1, C6.1, U1.23 (DVDD), U1.45 (VREG_VOUT), U1.50 (DVDD)
/3V3: C3.1, C7.1, C8.1, C11.1, C12.1, C13.1, C14.1, C15.1, C17.1, C18.1, C19.1, C20.1, J3.2, R1.2, R6.1, R8.1, R9.1, U1.1 (IOVDD), U1.10 (IOVDD), U1.22 (IOVDD), U1.33 (IOVDD), U1.42 (IOVDD), U1.43 (ADC_AVDD), U1.44 (VREG_VIN), U1.48 (USB_VDD), U1.49 (IOVDD), U4.5 (VOUT), U5.8 (VCC)
/BOOT: JP1.1 (A), R7.2
/CC1: J2.A5 (CC1), R4.1
/CC2: J2.B5 (CC2), R5.1
/COL0: SW1.1, SW9.1, SW17.1, SW24.1, SW31.1, SW38.1, U1.13 (GPIO10)
/COL1: SW2.1, SW10.1, SW18.1, SW25.1, SW32.1, SW39.1, U1.14 (GPIO11)
/COL2: SW3.1, SW11.1, SW19.1, SW26.1, SW33.1, SW40.1, U1.15 (GPIO12)
/COL3: SW4.1, SW12.1, SW20.1, SW27.1, SW34.1, SW41.1, U1.16 (GPIO13)
/COL4: SW5.1, SW13.1, SW21.1, SW28.1, SW35.1, SW42.1, U1.17 (GPIO14)
/COL5: SW6.1, SW14.1, SW22.1, SW29.1, SW36.1, SW43.1, U1.27 (GPIO16)
/COL6: SW7.1, SW15.1, SW23.1, SW30.1, SW37.1, SW44.1, U1.28 (GPIO17)
/COL7: SW8.1, SW16.1, U1.29 (GPIO18)
/D+: R2.1, U1.47 (USB_DP)
/D-: R3.1, U1.46 (USB_DM)
/DATA: J1.T, U1.3 (GPIO1)
/ENC_A: ENC1.A, U1.30 (GPIO19)
/ENC_B: ENC1.B, U1.31 (GPIO20)
/HAND: R1.1, U1.2 (GPIO0)
/K1: D1.2 (A), SW1.2
/K2: D2.2 (A), SW2.2
/K3: D3.2 (A), SW3.2
/K4: D4.2 (A), SW4.2
/K5: D5.2 (A), SW5.2
/K6: D6.2 (A), SW6.2
/K7: D7.2 (A), SW7.2
/K8: D8.2 (A), SW8.2
/K9: D9.2 (A), SW9.2
/K10: D10.2 (A), SW10.2
/K11: D11.2 (A), SW11.2
/K12: D12.2 (A), SW12.2
/K13: D13.2 (A), SW13.2
/K14: D14.2 (A), SW14.2
/K15: D15.2 (A), SW15.2
/K16: D16.2 (A), SW16.2
/K17: D17.2 (A), SW17.2
/K18: D18.2 (A), SW18.2
/K19: D19.2 (A), SW19.2
/K20: D20.2 (A), SW20.2
/K21: D21.2 (A), SW21.2
/K22: D22.2 (A), SW22.2
/K23: D23.2 (A), SW23.2
/K24: D24.2 (A), SW24.2
/K25: D25.2 (A), SW25.2
/K26: D26.2 (A), SW26.2
/K27: D27.2 (A), SW27.2
/K28: D28.2 (A), SW28.2
/K29: D29.2 (A), SW29.2
/K30: D30.2 (A), SW30.2
/K31: D31.2 (A), SW31.2
/K32: D32.2 (A), SW32.2
/K33: D33.2 (A), SW33.2
/K34: D34.2 (A), SW34.2
/K35: D35.2 (A), SW35.2
/K36: D36.2 (A), SW36.2
/K37: D37.2 (A), SW37.2
/K38: D38.2 (A), SW38.2
/K39: D39.2 (A), SW39.2
/K40: D40.2 (A), SW40.2
/K41: D41.2 (A), SW41.2
/K42: D42.2 (A), SW42.2
/K43: D43.2 (A), SW43.2
/K44: D44.2 (A), SW44.2
/QSPI_SCLK: U1.52 (QSPI_SCLK), U5.6 (CLK)
/QSPI_SD0: U1.53 (QSPI_SD0), U5.5 (DI/IO_{0})
/QSPI_SD1: U1.55 (QSPI_SD1), U5.2 (DO/IO_{1})
/QSPI_SD2: U1.54 (QSPI_SD2), U5.3 (~WP/IO_{2})
/QSPI_SD3: U1.51 (QSPI_SD3), U5.7 (~HOLD/~RESET/IO_{3})
/QSPI_SS: R7.1, U1.56 (~QSPI_SS), U5.1 (~CS)
/ROW0: D1.1 (K), D2.1 (K), D3.1 (K), D4.1 (K), D5.1 (K), D6.1 (K), D7.1 (K), D8.1 (K), U1.6 (GPIO4)
/ROW1: D9.1 (K), D10.1 (K), D11.1 (K), D12.1 (K), D13.1 (K), D14.1 (K), D15.1 (K), D16.1 (K), U1.7 (GPIO5)
/ROW2: D17.1 (K), D18.1 (K), D19.1 (K), D20.1 (K), D21.1 (K), D22.1 (K), D23.1 (K), U1.8 (GPIO6)
/ROW3: D24.1 (K), D25.1 (K), D26.1 (K), D27.1 (K), D28.1 (K), D29.1 (K), D30.1 (K), U1.9 (GPIO7)
/ROW4: D31.1 (K), D32.1 (K), D33.1 (K), D34.1 (K), D35.1 (K), D36.1 (K), D37.1 (K), U1.11 (GPIO8)
/ROW5: D38.1 (K), D39.1 (K), D40.1 (K), D41.1 (K), D42.1 (K), D43.1 (K), D44.1 (K), U1.12 (GPIO9)
/RUN: R6.2, RSW1.1, U1.26 (RUN)
/SCL: J3.3, R8.2, U1.5 (GPIO3)
/SDA: J3.4, R9.2, U1.4 (GPIO2)
/USB_D+: J2.A6 (D+), J2.B6 (D+), R2.2, U2.1 (I/O1), U2.6 (I/O1)
/USB_D-: J2.A7 (D-), J2.B7 (D-), R3.2, U2.3 (I/O2), U2.4 (I/O2)
/VBUS: F1.2, J2.A4 (VBUS), J2.A9 (VBUS), J2.B4 (VBUS), J2.B9 (VBUS), U2.5 (VBUS)
/VFUSE: D99.2 (A), F1.1
/XIN: C1.1, U1.20 (XIN), Y1.1
/XOUT: R10.2, U1.21 (XOUT)
/XTAL: C2.1, R10.1, Y1.3
GND: C1.2, C2.2, C3.2, C4.2, C5.2, C6.2, C7.2, C8.2, C11.2, C12.2, C13.2, C14.2, C15.2, C16.2, C17.2, C18.2, C19.2, C20.2, ENC1.C, J1.S, J2.A1 (GND), J2.A12 (GND), J2.B1 (GND), J2.B12 (GND), J2.SH (SHIELD), J3.1, JP1.2 (B), R4.2, R5.2, RSW1.2, U1.19 (TESTEN), U1.57 (GND), U2.2 (GND), U4.2 (GND), U5.4 (GND), Y1.2 (G), Y1.4 (G)
VCC: C16.1, D99.1 (K), J1.R2, U4.1 (VIN), U4.3 (EN)

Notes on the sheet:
Key matrix (left half, COL2ROW, 44 keys)
COL0
COL1
COL2
COL3
COL4
COL5
COL6
COL7
ROW0
ROW1
ROW2
ROW3
ROW4
ROW5
MCU: RP2040 (QFN-56), 12 MHz, 3.3 V I/O, 16 MB QSPI flash
Flash
Clock
Decoupling
Reset (double-tap = bootloader) / BOOTSEL pads
Handedness: GP0 high = left
3.3 V LDO
USB-C (USB 2.0 device)
Power
Split link: TRRS 3.5 mm (5 V + QMK serial)
OLED 0.91" 128x32 (I2C, SSD1306, 3.3 V)
Thumbwheel encoder Alps EC05E1220401 (12 detents / 12 pulses, C = common)

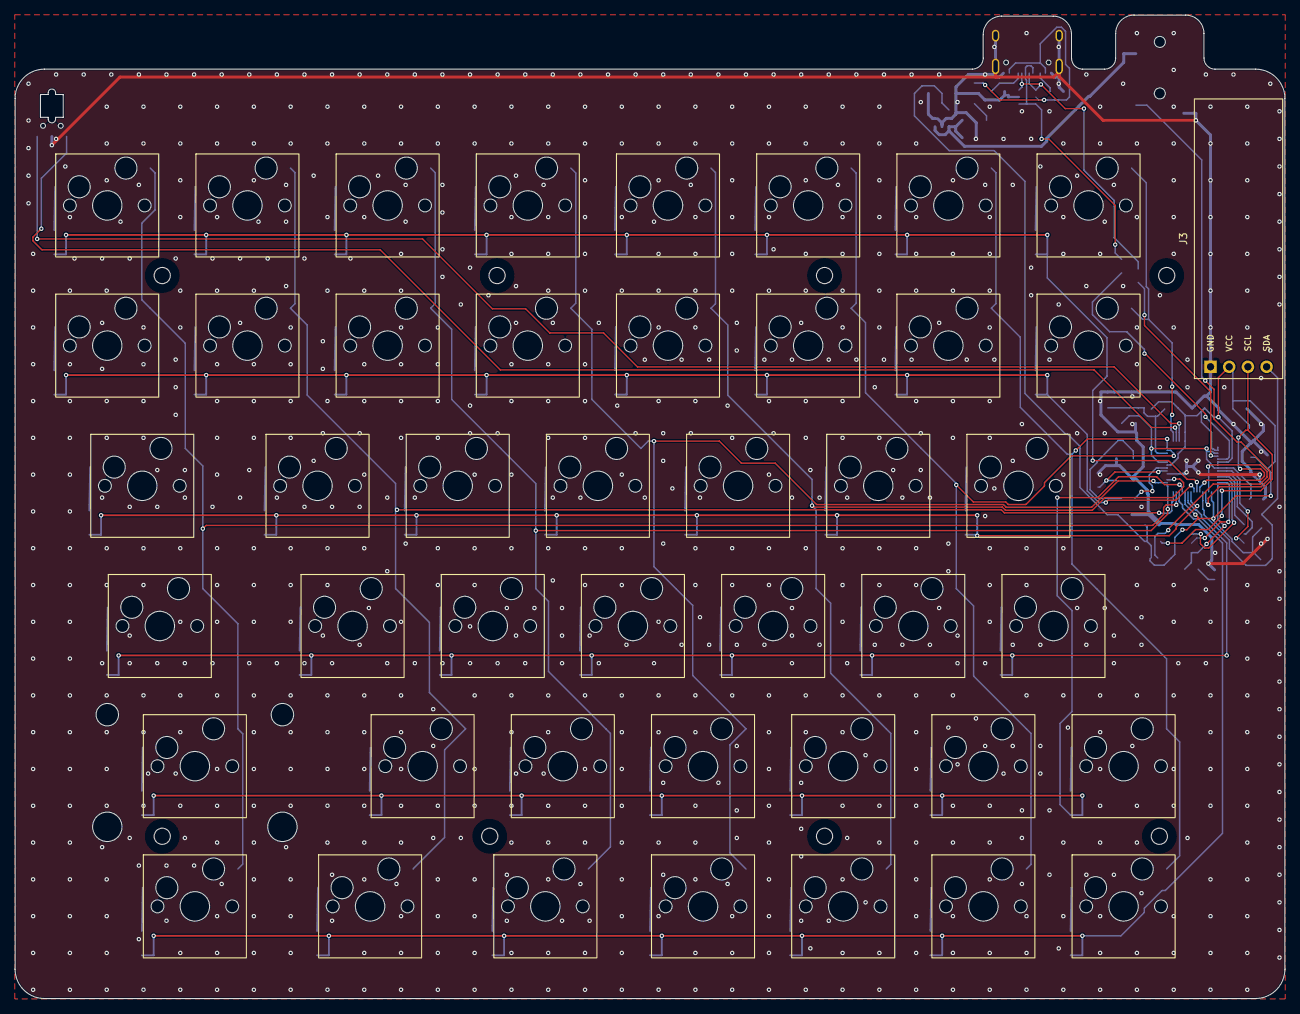
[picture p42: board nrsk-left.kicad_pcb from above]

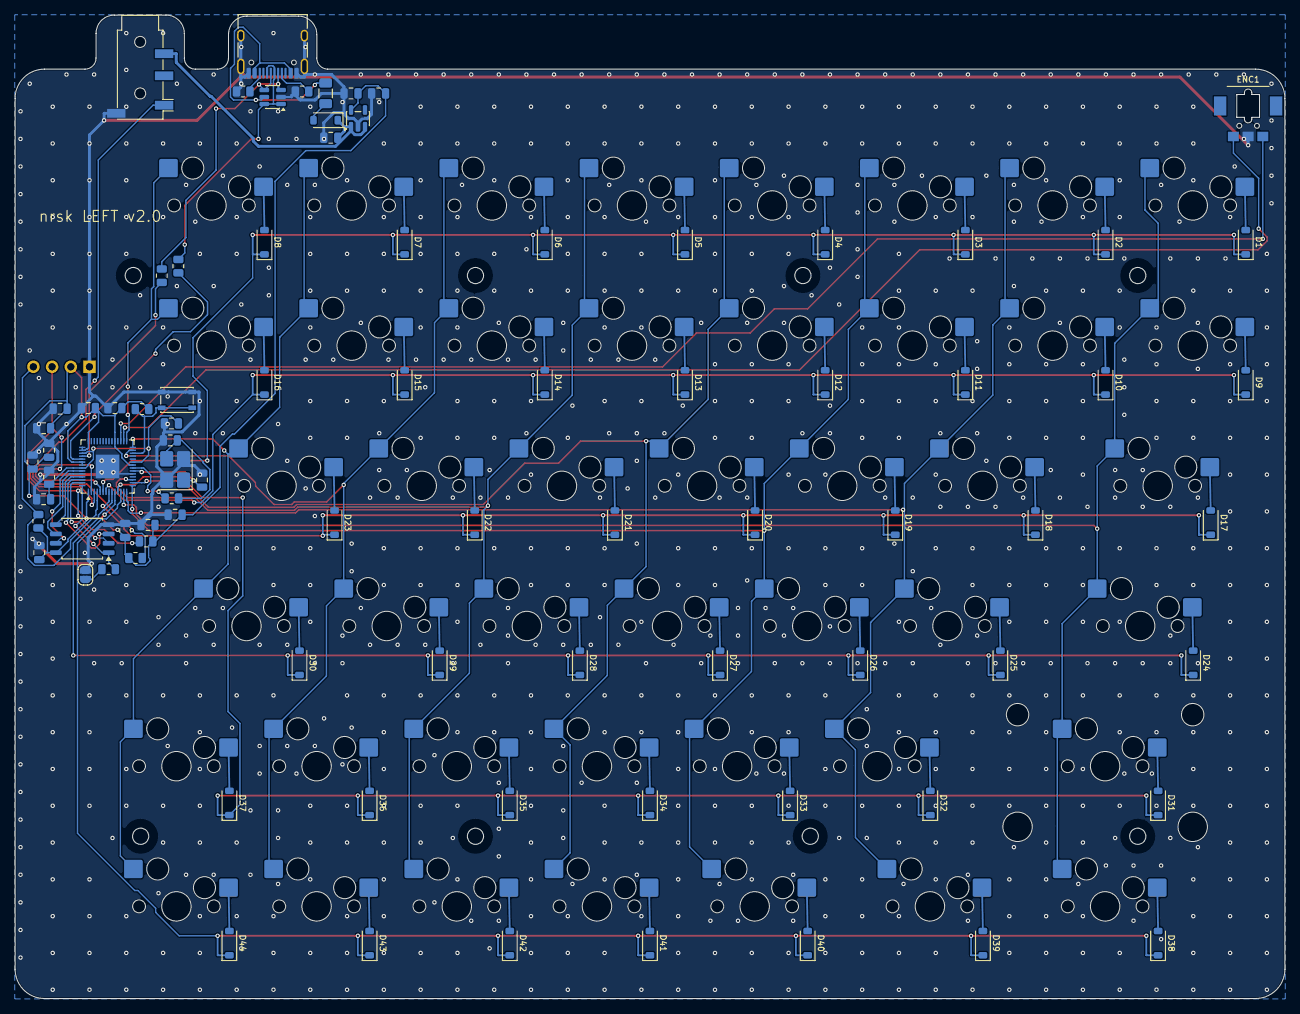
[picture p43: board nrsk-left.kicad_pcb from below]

Board: 2 copper layers, 172.6 x 133.6 mm, 137 parts (84 on the bottom side), 87 nets.

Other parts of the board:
H1, H2, H3, H4, H5, H6, H7, H8: M2; MountingHole_2.2mm_M2

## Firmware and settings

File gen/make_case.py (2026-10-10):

"""Generate the enclosure for each half from <side>/case_data.json.

Two variants share one geometry:
  * laser  - acrylic sandwich: bottom 3 mm + 4 frames x 3 mm + switch plate 1.5 mm  (DXF / SVG)
  * print  - 3D printed tray (floor + walls + bosses) + printed plate                (STL)

Heights (z, mm, bottom of case = 0)
  acrylic : bottom 0-3 | frames 3-15 | PCB 10.0-11.6 on 7 mm M2 standoffs | plate 15-16.5
  print   : floor 0-2  | walls 2-14.1 | PCB 9.0-10.6 on 7 mm bosses       | plate 14.1-15.6
MX spec: plate top to PCB top = 5.0 mm -> plate bottom 3.5 mm above the PCB.
USB-C and TRRS sit on the back of the PCB, so the plugs pass below the PCB: the switch plate and
the top frame stay closed, only the wall below the PCB is opened.

Run with the project venv:  .venv/bin/python gen/make_case.py
"""
import json
import math
import os
import struct
import sys

from manifold3d import CrossSection, JoinType, Manifold, set_circular_segments

HERE = os.path.dirname(os.path.abspath(__file__))
ROOT = os.path.abspath(os.path.join(HERE, '..'))
OUT = os.path.join(ROOT, 'case')
set_circular_segments(96)

# --- parameters ---------------------------------------------------------------
CLEAR = 0.5          # PCB edge to frame inner wall
WALL = 8.0           # frame / wall width
SCREW_D = 2.2        # M2 clearance hole
PLATE_T = 1.5
PCB_T = 1.6
PLATE_GAP = 3.5      # PCB top -> plate bottom (MX: 5.0 - 1.5)
STANDOFF = 7.0       # PCB bottom above case floor (room for the TRRS / USB-C plugs under the PCB)
# acrylic
BOTTOM_T = 3.0
FRAME_T = 3.0
N_FRAMES = 4
# connector ports: the PCB reaches into the wall on a tongue, the connector mouth sits PORT_SKIN inside the outer
# surface, and the wall shows only the connector outline. In the printed tray each port is a closed tunnel with
# PORT_LIFT of headroom over the tongue: the board goes in front edge slightly raised and PORT_LIFT high, slides
# tongue-first into the tunnels, then drops onto the bosses. In the acrylic stack the frames are notched.
USB_SHELL = (8.94, 3.26)     # HRO TYPE-C-31-M-12 shell w, h (hangs under the PCB)
TRRS_H, TRRS_NOZZLE = 5.0, 5.0   # PJ-320D body height under the PCB, nozzle diameter
PORT_CLR = 0.2               # opening around the connector outline
CHANNEL_CLR = 0.3            # tongue / connector body to the tunnel
PORT_KEEP = 3.0              # case screws stay this far beyond the tunnel along the wall
PORT_LIFT = 2.0              # tunnel headroom: the board slides in this high, clear of the bosses (needs >= 1.5)
# print
FLOOR = 2.0
BOSS_D = 4.6         # stays clear of back-side pads (>= 2.75 mm from hole centre)
PILOT_D = 1.6        # M2 self-tapping
INSERT_D = 3.2       # M2 heat-set insert (in the printed plate's bosses)
INSERT_DEPTH = 4.0
# plate screws (one tray for A and B):
#   B (printed plate): M2 x 12 from the tray bottom (counterbored) up the wall into a heat-set insert in a boss under
#     the plate, so the plate top shows no screws; the boss sits in a pocket at the wall top
#   A (acrylic plate): M2 x 6 slim-head screw from the top into an M2 nut dropped into the hex trap under that pocket
#   acrylic stack: M2 x 20 from the top through everything into a nut under the bottom plate
SCREW_CB = (4.6, 1.6)        # counterbore for the pan head under the tray (diameter, depth)
PLATE_BOSS = (5.6, 3.0)      # boss under the printed plate (diameter, height)
BOSS_POCKET = (6.0, 3.2)     # pocket in the wall top for the boss
NUT_TRAP = (4.15, 1.8)       # hex trap for an M2 nut under the pocket (across flats, depth)
RESET_D = 3.0
# 3D print: the wall above the wheel opening is a separate cap, so the wheel can be dropped in from above
CAP_SHOULDER = 2.0           # cap's top tier overhangs the opening by this much and rests on the wall
CAP_LEDGE = 3.0              # thickness of that top tier
CAP_FIT = 0.15
RIB_T = 2.0                  # all-printed variant: web under the printed plate (PCB top + 1.5)
TRAY_FILLET = 2.0     # 3D-printed tray: rounded bottom outer edge
TRAY_TOP_FILLET = 0.6 # small round on the top outer edge, under the plate
PLATE_FILLET = 1.0    # all-printed plate: rounded top outer edge (prints fine top-down: 1 mm reach on the bed side)
SWITCH_CUT = 14.0
# OLED: window in the switch plate, filled by a half-mirror acrylic cover flush with the plate top. Half-mirror
# acrylic starts at 2 mm, so the cover reaches 0.5 mm below the 1.5 mm plate; it rests on the module's glass
# (soldered low, glass top 2.5 mm above the PCB) and is held by 0.5 mm clear double-sided tape. No screws,
# so the plate keeps its closed outer edge.
OLED_WINDOW_CLEAR = 0.15     # added to the module courtyard (courtyard = module + 0.25)
COVER_T = 2.0                # half-mirror acrylic; top flush with the plate top
COVER_FIT = 0.1              # cover edge to plate opening
COVER_BORDER = 5.0           # cover: rounded rectangle, this much larger than the OLED window all round
COVER_R = 5.0                 # follows the rounded case corner it sits next to
COVER_MARGIN = 3.0           # cover stays at least this far inside the case outline
WALL_POCKET = 0.5            # 3D print: wall top lowered under the cover (cover 2 mm vs plate 1.5 mm)
TAPE_T = 0.5                 # clear double-sided tape between glass and cover
OLED_GLASS_TOP = PLATE_GAP + PLATE_T - COVER_T - TAPE_T   # = 2.5: glass top above the PCB top
SWITCH_TOP_KEEPOUT = 8.4     # half size of an MX top housing (15.6 mm) + 0.6 mm
# corner thumbwheel: lies under the PCB, rim out of the corner. An Alps EC05E1220401 (hollow-shaft encoder,
# 12 detents) hangs from the PCB back on the wheel axis; a hex pin on the wheel top drives its rotor, and the
# clicks come from the encoder. The thumb's side force is taken by the floor post (acrylic: an M3 screw), which
# has radial play, so the board-to-tray tolerance does not bind the wheel between post and encoder.
WHEEL_T = 4.1
WHEEL_GAP = 0.3              # wheel bottom above the floor / bottom plate
WHEEL_CUT = 0.6              # radial clearance of the wall opening
WHEEL_KNURLS = 32            # rounded teeth on the rim: the grip
TOOTH_DEPTH = 0.5            # valley depth of the rim teeth
BORE_D, BORE_DEPTH = 4.0, 2.0          # axle bore from below
POST_D = 3.6                 # printed axle post (3D print variant): 0.2 mm radial play in the bore
AXLE_HOLE_D = 3.2            # M3 axle screw through the bottom plate (acrylic variant)
# Alps EC05E1220401 (catalog drawing No.3): body 5.7 wide (7.6 over the side tabs), 2.5 / 3.7 from the rotor
# axis, 2.7 below the PCB back; hex hole 1.72 A/F through the rotor, entered from the wheel side
ENC_W, ENC_TAB_W, ENC_UP, ENC_DOWN, ENC_H = 5.7, 7.6, 2.5, 3.7, 2.7
ENC_HEX_AF, ENC_ROTOR_D = 1.72, 2.2
HUB_R = 6.0                  # wheel top lowered within this radius: clears the body, tabs and terminals
HUB_CLEAR = 0.3              # encoder body to the lowered hub
PIN_AF = 1.66                # hex pin across flats: tune on a test print (play vs. fit)
PIN_ENGAGE = 2.0             # pin length inside the rotor
PIN_CHAMFER = 0.25
STAB_CUT = (7.0, 15.4, 0.5)   # w, h, centre y offset (down) of each stabilizer housing cut-out
STAB_X = 11.938


def cs_poly(pts):
    # board coordinates are y-down; flipping y reverses the winding, so reverse the order too
    return CrossSection([[(x, -y) for x, y in reversed(pts)]])


def rect(x0, y0, x1, y1):
    return cs_poly([(x0, y0), (x1, y0), (x1, y1), (x0, y1)])


def rounded_rect(x0, y0, x1, y1, r):
    return rect(x0 + r, y0 + r, x1 - r, y1 - r).offset(r, JoinType.Round)


def inside(cs, p):
    """Point (board coordinates) inside a cross-section."""
    return (circle(p[0], p[1], 0.2) - cs).area() < 1e-4


def circle(x, y, d):
    return CrossSection.circle(d / 2).translate((x, -y))


def hexagon(af, h):
    """Hexagonal prism (across flats af), axis on z from 0 to h."""
    r = af / math.sqrt(3)
    return Manifold.extrude(CrossSection([[(r * math.cos(math.radians(60 * i)), r * math.sin(math.radians(60 * i)))
                                            for i in range(6)]]), h)


class Half:
    def __init__(self, side):
        self.d = json.load(open(os.path.join(ROOT, side, 'case_data.json')))
        self.side = side
        o = self.d['outline']
        self.pcb = (o['x0'], o['y0'], o['x1'], o['y1'], o['r'])
        x0, y0, x1, y1, r = self.pcb
        self.inner = rounded_rect(x0 - CLEAR, y0 - CLEAR, x1 + CLEAR, y1 + CLEAR, r + CLEAR)
        e = CLEAR + WALL
        self.outer_box = (x0 - e, y0 - e, x1 + e, y1 + e, r + e)
        self.outer = rounded_rect(*self.outer_box)
        self.inner_right = self.d['inner_side'] == 'right'
        self.slots = self._slots()
        self.screws = self._screws()
        self.window_box = self._oled()
        self.cover_screws = self._cover_screws()
        # perimeter screws under the cover give way to the cover's own screws
        cov = self.cover_shape().offset(1.5, JoinType.Round)
        self.screws = [p for p in self.screws if not inside(cov, p) and
                       all(math.dist(p, c) > 8 for c in self.cover_screws)] + self.cover_screws

    # connector openings through the top wall -------------------------------------
    def _slots(self):
        """Connector ports (from the tongues in case_data). Each entry also carries the along-wall extent used to
        keep case screws away ('y'/'half' on the inner edge, 'full' rectangle on the top edge)."""
        out = []
        ox0, oy0, ox1, oy1, _ = self.outer_box
        skin = self.d.get('port_skin', 0.8)
        for name, t in self.d['tongues'].items():
            c = self.d['connectors'][name]
            edge = c.get('edge', 'inner')
            chan = (rect(*t) + rect(*c['box'])).offset(CHANNEL_CLR, JoinType.Miter) ^ self.outer.offset(-skin, JoinType.Miter)
            e = PORT_KEEP
            if edge == 'top':
                a0, a1 = t[0] - CHANNEL_CLR - e, t[2] + CHANNEL_CLR + e
                cap = rect(a0, oy0 - 1, a1, self.pcb[1] - CLEAR + 0.01) ^ (self.outer - self.inner)
                full = (a0, oy0 - 1, a1, self.pcb[1])
                out.append(dict(name=name, edge='top', x=(t[0] + t[2]) / 2, half=(a1 - a0) / 2, full=full,
                                chan=chan, cap=cap, along=(t[0] + t[2]) / 2))
            else:
                a0, a1 = t[1] - CHANNEL_CLR - e, t[3] + CHANNEL_CLR + e
                if self.inner_right:
                    cap = rect(self.pcb[2] + CLEAR - 0.01, a0, ox1 + 1, a1) ^ (self.outer - self.inner)
                    full = (self.pcb[2], a0, ox1 + 1, a1)
                else:
                    cap = rect(ox0 - 1, a0, self.pcb[0] - CLEAR + 0.01, a1) ^ (self.outer - self.inner)
                    full = (ox0 - 1, a0, self.pcb[0], a1)
                out.append(dict(name=name, edge='inner', y=(t[1] + t[3]) / 2, half=(a1 - a0) / 2, full=full,
                                chan=chan, cap=cap, along=(t[1] + t[3]) / 2))
        # neighbouring ports on the top edge share one screw-free zone
        tops = sorted((sl for sl in out if sl['edge'] == 'top'), key=lambda sl: sl['full'][0])
        for a, b in zip(tops, tops[1:]):
            if b['full'][0] - a['full'][2] < 2 * PORT_KEEP:
                full = (a['full'][0], a['full'][1], b['full'][2], a['full'][3])
                cap = rect(full[0], full[1], full[2], self.pcb[1] - CLEAR + 0.01) ^ (self.outer - self.inner)
                for sl in (a, b):
                    sl.update(full=full, cap=cap, half=(full[2] - full[0]) / 2)
        return out

    def port_z(self, port, z_pcb):
        """(bottom of the connector, centre of its opening, opening height) for a PCB bottom at z_pcb."""
        if port['name'] == 'usb':
            return z_pcb - USB_SHELL[1], z_pcb - USB_SHELL[1] / 2, USB_SHELL[1] + 2 * PORT_CLR
        return z_pcb - TRRS_H, z_pcb - TRRS_NOZZLE / 2, TRRS_NOZZLE + 2 * PORT_CLR

    def port_hole(self, port, z_pcb):
        """The visible opening: connector outline + PORT_CLR, through the skin in front of the mouth."""
        _, zc, hh = self.port_z(port, z_pcb)
        ox0, oy0, ox1, oy1, _ = self.outer_box
        depth = self.d.get('port_skin', 0.8) + 1.0
        if port['name'] == 'usb':
            w, h = USB_SHELL[0] + 2 * PORT_CLR, hh
            r = h / 2
            cs = CrossSection.square((w - 2 * r, 0.001), center=True).offset(r, JoinType.Round)
            m = Manifold.extrude(cs, depth + 1).rotate((-90, 0, 0))        # along +y (3D) = outward on the top edge
            return m.translate((port['along'], -oy0 - depth, zc))
        m = Manifold.cylinder(depth + 1, hh / 2, hh / 2, 48).rotate((0, 90, 0))   # along +x
        if port['edge'] == 'top':
            return m.rotate((0, 0, 90)).translate((port['along'], -oy0 - depth, zc))
        if self.inner_right:
            return m.translate((ox1 - depth, -port['along'], zc))
        return m.rotate((0, 0, 180)).translate((ox0 + depth, -port['along'], zc))

    def slot_cs(self, pcb_side_too=True):
        cs = CrossSection()
        for s in self.slots:
            cs = cs + s['cap']
        return cs

    # OLED window and cover ---------------------------------------------------------------
    def _oled(self):
        bx0, by0, bx1, by1 = self.d['oled']['box']
        g = OLED_WINDOW_CLEAR
        return (bx0 - g, by0 - g, bx1 + g, by1 + g)

    def window_cs(self):
        return rect(*self.window_box)

    def wheel_xy(self):
        return self.d['wheel']['center'], self.d['wheel']['r']

    def wheel_cut(self, grow=WHEEL_CUT):
        (x, y), r = self.wheel_xy()
        return circle(x, y, 2 * (r + grow))

    def switch_tops(self):
        cs = CrossSection()
        h = SWITCH_TOP_KEEPOUT
        for k in self.d['keys']:
            cs = cs + rect(k['cx'] - h, k['cy'] - h, k['cx'] + h, k['cy'] + h)
        return cs

    def cover_shape(self):
        """Half-mirror inlay: rounded rectangle centred on the OLED window, COVER_BORDER wide all round."""
        x0, y0, x1, y1 = self.window_box
        m = COVER_BORDER
        return rounded_rect(x0 - m, y0 - m, x1 + m, y1 + m, COVER_R)

    def _cover_screws(self):
        """The cover is held by clear double-sided tape (on the OLED glass and the wall ledge), not screws."""
        return []

    def cover(self):
        return self.cover_shape() - self.holes(self.cover_screws, SCREW_D)

    # perimeter screws on the wall centre line --------------------------------------
    def _screws(self):
        x0, y0, x1, y1, r = self.pcb
        m = CLEAR + WALL / 2
        X0, Y0, X1, Y1, R = x0 - m, y0 - m, x1 + m, y1 + m, r + m
        pts = []
        k = R * (1 - 1 / math.sqrt(2))
        pts += [(X0 + k, Y0 + k), (X1 - k, Y0 + k), (X0 + k, Y1 - k), (X1 - k, Y1 - k)]
        n = max(1, round((X1 - X0) / 55) - 1)
        for i in range(1, n + 1):
            x = X0 + (X1 - X0) * i / (n + 1)
            pts += [(x, Y0), (x, Y1)]
        # sides: outer side at mid height; inner side in every gap between slots
        outer_x, inner_x = (X0, X1) if self.inner_right else (X1, X0)
        pts.append((outer_x, (Y0 + Y1) / 2))
        edges = sorted([(s['y'] - s['half'], s['y'] + s['half']) for s in self.slots if s['edge'] == 'inner'])
        free, last = [], Y0 + R
        for a, b in edges:
            free.append((last, a)); last = b
        free.append((last, Y1 - R))
        for a, b in free:
            a2, b2 = a + 3.5, b - 3.5
            if b2 - a2 >= 0:
                pts.append((inner_x, (a2 + b2) / 2))
        # the corner wheel takes the corner screw; put one on each face just past the wheel opening
        (wx, wy), wr = self.d['wheel']['center'], self.d['wheel']['r']
        keep = wr + WHEEL_CUT + CAP_SHOULDER + INSERT_D / 2 + 0.8     # clear of the wheel cap's shoulder
        pts = [p for p in pts if math.hypot(p[0] - wx, p[1] - wy) > keep]
        d = math.sqrt(keep ** 2 - (wy - Y0) ** 2)
        side_x = X0 if wx < (X0 + X1) / 2 else X1
        pts.append((wx + d if side_x == X0 else wx - d, Y0))
        pts.append((side_x, wy + math.sqrt(keep ** 2 - (wx - side_x) ** 2)))
        tops = [rect(*sl['full']).offset(3.5, JoinType.Miter) for sl in self.slots if sl['edge'] == 'top']
        pts = [p for p in pts if not any(inside(t, p) for t in tops)]
        return pts

    # 2D layers ------------------------------------------------------------------------
    def holes(self, pts, d):
        cs = CrossSection()
        for x, y in pts:
            cs = cs + circle(x, y, d)
        return cs

    def plate(self):
        cut = CrossSection()
        for k in self.d['keys']:
            h = SWITCH_CUT / 2
            cut = cut + rect(k['cx'] - h, k['cy'] - h, k['cx'] + h, k['cy'] + h)
            if k['w'] >= 2:
                w, hh, dy = STAB_CUT
                for sx in (-1, 1):
                    cx = k['cx'] + sx * STAB_X
                    cut = cut + rect(cx - w / 2, k['cy'] + dy - hh / 2, cx + w / 2, k['cy'] + dy + hh / 2)
        return self.outer - cut - self.cover_shape().offset(COVER_FIT, JoinType.Round) - self.holes(self.screws, SCREW_D)

    def frame(self, layer):
        cs = self.outer - self.inner - self.holes(self.screws, SCREW_D)
        z0 = BOTTOM_T + layer * FRAME_T
        wz0 = BOTTOM_T + WHEEL_GAP
        if z0 < wz0 + WHEEL_T + 0.4 and z0 + FRAME_T > wz0 - 0.3:   # this frame is level with the wheel
            cs = cs - self.wheel_cut()
        z_pcb = BOTTOM_T + STANDOFF
        for p in self.slots:       # notch for the tongue + connector, and the opening in front of the mouth
            zb, zc, hh = self.port_z(p, z_pcb)
            if z0 < z_pcb + PCB_T + 0.3 and z0 + FRAME_T > zb - 0.2:
                cs = cs - p['chan']
            if z0 < zc + hh / 2 and z0 + FRAME_T > zc - hh / 2:
                cs = cs - self.port_hole(p, z_pcb).project().offset(0.01, JoinType.Miter)
        return cs

    def bottom(self):
        (wx, wy), _ = self.wheel_xy()
        return (self.outer - self.holes(self.screws, SCREW_D) - self.holes(self.d['holes'], SCREW_D)
                - circle(*self.d['reset'], RESET_D) - circle(wx, wy, AXLE_HOLE_D))

    # 3D print -------------------------------------------------------------------------
    def tray(self):
        wall_top = FLOOR + STANDOFF + PCB_T + PLATE_GAP
        body = self._filleted(wall_top)
        body = body - Manifold.extrude(self.inner, wall_top).translate((0, 0, FLOOR))
        for x, y in self.d['holes']:
            boss = Manifold.cylinder(STANDOFF, BOSS_D / 2, BOSS_D / 2).translate((x, -y, FLOOR))
            body = body + boss
            body = body - Manifold.cylinder(STANDOFF + FLOOR - 0.6, PILOT_D / 2, PILOT_D / 2).translate((x, -y, 0.6))
        for x, y in self.screws:     # screw from below: counterbore, clearance hole up the wall, pocket at the top
            body = body - Manifold.cylinder(wall_top + 0.02, SCREW_D / 2, SCREW_D / 2, 24).translate((x, -y, -0.01))
            body = body - Manifold.cylinder(SCREW_CB[1] + 0.01, SCREW_CB[0] / 2, SCREW_CB[0] / 2, 32).translate((x, -y, -0.01))
            body = body - Manifold.cylinder(BOSS_POCKET[1] + 0.01, BOSS_POCKET[0] / 2, BOSS_POCKET[0] / 2, 32).translate(
                (x, -y, wall_top - BOSS_POCKET[1]))
            r_hex = NUT_TRAP[0] / math.sqrt(3)
            body = body - Manifold.cylinder(NUT_TRAP[1] + 0.01, r_hex, r_hex, 6).translate(
                (x, -y, wall_top - BOSS_POCKET[1] - NUT_TRAP[1]))
        (wx, wy), wr = self.wheel_xy()
        wz0 = FLOOR + WHEEL_GAP
        body = body - Manifold.extrude(self.wheel_cut(), WHEEL_T + 0.7).translate((0, 0, wz0 - 0.3))
        # wall above the opening -> separate cap (stepped, rests on a ledge, held down by the plate)
        z1 = wz0 - 0.3 + WHEEL_T + 0.7
        cut = self.wheel_cut()
        z_l = wall_top - CAP_LEDGE

        def tiers(grow):
            return (Manifold.extrude(cut.offset(grow, JoinType.Round), z_l - z1).translate((0, 0, z1)) +
                    Manifold.extrude(cut.offset(CAP_SHOULDER + grow, JoinType.Round), CAP_LEDGE + 0.01).translate((0, 0, z_l)))
        self._cap = body ^ tiers(-CAP_FIT)
        body = body - tiers(0.0)
        # pocket for the thicker cover
        body = body - Manifold.extrude(self.cover_shape().offset(COVER_FIT, JoinType.Round), WALL_POCKET + 0.01).translate(
            (0, 0, wall_top - WALL_POCKET))
        # port tunnels: closed above, with headroom so the board can slide in tongue-first
        z_pcb = FLOOR + STANDOFF
        for p in self.slots:
            zp = self.port_z(p, z_pcb)[0] - 0.2
            zt = z_pcb + PCB_T + CHANNEL_CLR + PORT_LIFT
            body = body - Manifold.extrude(p['chan'], zt - zp).translate((0, 0, zp)) - self.port_hole(p, z_pcb)
        body = body + Manifold.cylinder(WHEEL_GAP + BORE_DEPTH - 0.3, POST_D / 2, POST_D / 2, 48).translate(
            (wx, -wy, FLOOR))
        rx, ry = self.d['reset']
        body = body - Manifold.cylinder(FLOOR + 0.02, RESET_D / 2, RESET_D / 2).translate((rx, -ry, -0.01))
        return body

    def _filleted(self, top):
        """Outer block of the tray with filleted bottom and top outer edges (stacked offset slices)."""
        def band(z0, z1, r, at_bottom):
            parts, n = [], 8
            for i in range(n):
                za, zb = z0 + (z1 - z0) * i / n, z0 + (z1 - z0) * (i + 1) / n
                zm = (za + zb) / 2 - z0 if at_bottom else z1 - (za + zb) / 2
                inset = r - math.sqrt(max(r * r - (r - zm) ** 2, 0))
                parts.append(Manifold.extrude(self.outer.offset(-inset, JoinType.Round), zb - za).translate((0, 0, za)))
            return parts
        rb, rt = TRAY_FILLET, TRAY_TOP_FILLET
        parts = band(0, rb, rb, True) + [Manifold.extrude(self.outer, top - rb - rt).translate((0, 0, rb))] + \
            band(top - rt, top, rt, False)
        out = parts[0]
        for m in parts[1:]:
            out = out + m
        return out
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

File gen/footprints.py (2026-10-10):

"""Generate the project footprint library lib/nrsk.pretty."""
import os
import uuid

from layout import HERE

OUT = os.path.join(HERE, '..', 'lib', 'nrsk.pretty')
WIDTHS = [1.0, 1.25, 1.5, 1.75, 2.0, 2.25]
U = 19.05
# 3D models (fetched by gen/fetch_3d.sh into tools/, which is not committed; see README)
KISWITCH = '${KIPRJMOD}/../tools/kiswitch/library/3dmodels/3d-library.3dshapes/'
NRSK_3D = '${KIPRJMOD}/../lib/nrsk.3dshapes/'
ALPS_3D = '${KIPRJMOD}/../tools/alps/'


def uid():
    return str(uuid.uuid4())


def prop(name, value, at, layer, hide=False, size=1.0):
    h = ' (hide yes)' if hide else ''
    return (f'  (property "{name}" "{value}" (at {at[0]} {at[1]} 0) (layer "{layer}"){h} (uuid "{uid()}")\n'
            f'    (effects (font (size {size} {size}) (thickness 0.15))))\n')


def line(x1, y1, x2, y2, layer, w=0.12):
    return (f'  (fp_line (start {x1:.3f} {y1:.3f}) (end {x2:.3f} {y2:.3f}) '
            f'(stroke (width {w}) (type solid)) (layer "{layer}") (uuid "{uid()}"))\n')


def rect(x1, y1, x2, y2, layer, w=0.12):
    return (f'  (fp_rect (start {x1:.3f} {y1:.3f}) (end {x2:.3f} {y2:.3f}) '
            f'(stroke (width {w}) (type solid)) (fill no) (layer "{layer}") (uuid "{uid()}"))\n')


def npth(x, y, d):
    return (f'  (pad "" np_thru_hole circle (at {x:.3f} {y:.3f}) (size {d} {d}) (drill {d}) '
            f'(layers "*.Cu" "*.Mask") (uuid "{uid()}"))\n')


def text(s, x, y, layer, size=1.0, mirror=False):
    j = ' (justify mirror)' if mirror else ''
    return (f'  (fp_text user "{s}" (at {x:.3f} {y:.3f} 0) (layer "{layer}") (uuid "{uid()}")\n'
            f'    (effects (font (size {size} {size}) (thickness 0.15)){j}))\n')


def model(path, offset=(0, 0, 0), rotate=(0, 0, 0)):
    xyz = lambda v: ' '.join(f'{c:g}' for c in v)
    return (f'  (model "{path}"\n    (offset (xyz {xyz(offset)}))\n    (scale (xyz 1 1 1))\n'
            f'    (rotate (xyz {xyz(rotate)}))\n  )\n')


def mx_hotswap(w):
    name = f'SW_MX_Hotswap_{w:.2f}u'
    s = (f'(footprint "{name}"\n  (version 20241229)\n  (generator "nrsk-gen")\n  (layer "F.Cu")\n'
         f'  (descr "Cherry MX compatible switch, Kailh MX hotswap socket (CPG151101S11) on back, {w:.2f}u keycap'
         f'{", PCB-mount stabilizer" if w >= 2 else ""}")\n'
         f'  (tags "MX hotswap Kailh keyboard")\n  (attr smd)\n')
    s += prop('Reference', 'REF**', (0, 8.5), 'F.SilkS', hide=True)
    s += prop('Value', name, (0, -8.5), 'F.Fab', hide=True)
    s += prop('Footprint', '', (0, 0), 'F.Fab', hide=True)
    s += prop('Datasheet', '', (0, 0), 'F.Fab', hide=True)
    s += prop('Description', '', (0, 0), 'F.Fab', hide=True)
    # switch body (14 mm square) and keycap outline
    s += rect(-7, -7, 7, 7, 'F.SilkS')
    s += rect(-7, -7, 7, 7, 'F.CrtYd', 0.05)   # = switch housing; mounting holes may sit 2.5 mm outside
    s += rect(-w * U / 2, -U / 2, w * U / 2, U / 2, 'Dwgs.User', 0.1)
    # switch holes
    s += npth(0, 0, 4.0)
    s += npth(-5.08, 0, 1.75)
    s += npth(5.08, 0, 1.75)
    s += npth(-3.81, -2.54, 3.0)
    s += npth(2.54, -5.08, 3.0)
    # Kailh socket pads (back side)
    for num, (x, y) in (('1', (5.842, -5.08)), ('2', (-7.085, -2.54))):
        s += (f'  (pad "{num}" smd roundrect (at {x} {y}) (size 2.55 2.5) (roundrect_rratio 0.1) '
              f'(layers "B.Cu" "B.Paste" "B.Mask") (uuid "{uid()}"))\n')
    s += rect(-8.6, -7.4, 7.35, -0.6, 'B.CrtYd', 0.05)
    if w >= 2:
        for sx in (-11.9, 11.9):
            s += npth(sx, -7.0, 3.05)
            s += npth(sx, 8.24, 4.0)
    # same switch / socket geometry as kiswitch's SW_Hotswap_Kailh_MX footprints, so their models fit as-is
    s += model(KISWITCH + 'SW_Hotswap_Kailh_MX.stp')
    s += model(KISWITCH + 'SW_Cherry_MX_PCB.stp')
    if w >= 2:
        s += model(KISWITCH + 'Stabilizer_Cherry_MX_2.00u.stp')
    s += ')\n'
    return name, s


# 0.91" 128x32 SSD1306 I2C module (38 x 12 mm), soldered so its glass top is 2.5 mm above the PCB
# (the flush 2 mm half-mirror cover is taped onto it).
OLED_W, OLED_H = 38.0, 12.0
OLED_PIN_FROM_EDGE = 1.6      # header row centre to the module's short edge
OLED_GLASS = (30.0, 11.5)     # glass panel, toward the end away from the header


def oled_module():
    """Origin = module centre, long axis along X, header at -X end (pins 1..4 = GND VCC SCL SDA along +Y)."""
    name = 'OLED_0.91in_128x32_I2C'
    s = (f'(footprint "{name}"\n  (version 20241229)\n  (generator "nrsk-gen")\n  (layer "F.Cu")\n'
         '  (descr "0.91 inch 128x32 OLED module (SSD1306, I2C), 38 x 12 mm, 4-pin 2.54 mm header '
         '(GND VCC SCL SDA); glass top 2.5 mm above the PCB, header spacer removed")\n'
         '  (tags "OLED SSD1306 I2C 0.91 128x32")\n  (attr through_hole)\n')
    s += prop('Reference', 'REF**', (0, -7.5), 'F.SilkS')
    s += prop('Value', name, (0, 0), 'F.Fab')
    s += prop('Footprint', '', (0, 0), 'F.Fab', hide=True)
    s += prop('Datasheet', '', (0, 0), 'F.Fab', hide=True)
    s += prop('Description', '', (0, 0), 'F.Fab', hide=True)
    hw, hh = OLED_W / 2, OLED_H / 2
    s += rect(-hw, -hh, hw, hh, 'F.SilkS')
    s += rect(-hw - 0.25, -hh - 0.25, hw + 0.25, hh + 0.25, 'F.CrtYd', 0.05)
    gx = hw - OLED_GLASS[0] / 2 - 1.0
    s += rect(gx - OLED_GLASS[0] / 2, -OLED_GLASS[1] / 2, gx + OLED_GLASS[0] / 2, OLED_GLASS[1] / 2, 'F.Fab', 0.1)
    s += text('OLED', gx, 0, 'F.Fab', 1.5)
    px = -hw + OLED_PIN_FROM_EDGE
    for i, lbl in enumerate(('GND', 'VCC', 'SCL', 'SDA')):
        y = (i - 1.5) * 2.54
        shape = 'rect' if i == 0 else 'circle'
        s += (f'  (pad "{i + 1}" thru_hole {shape} (at {px:.2f} {y:.2f}) (size 1.7 1.7) (drill 1.0) '
              f'(layers "*.Cu" "*.Mask") (uuid "{uid()}"))\n')
        s += text(lbl, px + 3.2, y, 'F.SilkS', 0.8)
    s += model(NRSK_3D + 'OLED_0.91in_128x32.wrl')
    s += ')\n'
    return name, s


# Alps EC05E1220401: 5 mm hollow-shaft encoder, vertical, 12 detents / 12 pulses (catalog drawing No.3).
# Viewed from the mounting side with the rotor axis at the origin and the terminals toward +Y.
ENC_LAND = (3.8, 0.0, 1.7, 2.6)        # side tabs: centre x (+/-), centre y, w, h (5.9 mm between them)
ENC_PIN_PITCH, ENC_PIN_Y = 2.0, 4.15   # A C B in a row, 1.5 x 1.3 lands, 2.1 mm from the holes to the land edge
ENC_PIN = (1.5, 1.3)
ENC_HOLES = (1.2, 2.7, 0.67)            # locating holes: x (+/-), y, drill (0.62 +0.1/-0)
ENC_CUT = 1.55                          # half side of the 3 mm (+0.1) square hole under the rotor
ENC_CUT_LOBE = (0.5, 1.8)               # two R0.5 lobes on the Y axis, centres 3.6 mm apart
ENC_BODY = (-2.85, -2.5, 2.85, 3.7)     # resin body (5.7 wide, 2.5 / 3.7 from the axis), 2.7 mm high
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

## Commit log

2026-10-04 Add nrsk split keyboard: PCB, enclosure, BOM and firmware
    - KiCad 10 projects for both halves generated from the KLE layouts:
    ATmega32U4 (TQFP-44) with USB-C, TRRS split link, hotswap MX sockets,
    autorouted with Freerouting (ERC/DRC clean)
    - Enclosure for 3D printing (STL) and laser-cut acrylic (DXF/SVG);
    switch plate without connector cut-outs
    - Whole-project BOM, QMK keyboard definition, Blender product renders
    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
    [left-bottom.dxf, left-frame1.dxf, left-frame2.dxf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]
2026-10-04 Add OLED displays, OLED placement study and high-resolution renders
    - 0.91" 128x32 SSD1306 OLED on both halves (I2C on PD0/PD1, 4.7k pull-ups),
    placed in the key-free inner notch; boards re-routed, ERC/DRC clean
    - Switch plate window with a 2 mm clear acrylic cover lying on the plate,
    shaped around the switch tops; keyboard height unchanged
    - QMK: OLED enabled (layer/caps on the master, WPM on the other half),
    split sync of layer, LED state and WPM
    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
    [left-bottom.dxf, left-frame1.dxf, left-frame2.dxf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]
2026-10-04 Match both halves' size, align TRRS jacks, document firmware flashing
    - Left board widened on its inner side to the right board's outline
    (both 187.0 x 120.3 mm, cases 204.0 x 137.3 mm); MCU, USB-C, TRRS and
    OLED placed as a mirror of the right half
    - TRRS jacks at the same height on both halves (109 mm from the top),
    USB-C likewise (81 mm)
    - Router cleanup removes dangling track stubs left by Freerouting
    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
    [left-bottom.dxf, left-frame1.dxf, left-frame2.dxf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]
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2026-10-04 Case viewer: intuitive orbit controls
    - Set Z-up before creating OrbitControls so dragging orbits around the
    vertical axis instead of tumbling
    - Damping, polar limits (never below the desk), right-drag / two-finger
    pan, wheel / pinch zoom, double-click or button to reset the view
    [case_viewer.py]
2026-10-04 Add corner thumbwheels read by AS5600, preview-quality renders
    - Thumbwheel (29.2 mm, knurled) at the left half's top-left and the right
    half's top-right corner, lying under the PCB with its rim out of the
    corner; read contact-free by an AS5600 on the PCB back through a
    diametric magnet, on the existing I2C bus (no extra pins)
    - Left Esc switch turned 180 deg so its socket clears the sensor
    - Case: wall opening at the corner, axle post (print) / M3 axle (acrylic),
    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
    [left-bottom.dxf, left-frame1.dxf, left-frame2.dxf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]
2026-10-04 Fit boards and cases tightly, align TRRS, add sourced BOM
    - Board/case outlines shrink to each half's key area (left 163.2 mm,
    right 187.0 mm wide); TRRS jacks at the same height on both halves
    - build.sh: per-step failure handling in the routing loop
    - gen/doc_images.sh regenerates the README board/case images
    - BOM: manufacturer part numbers, shops, prices and verified URLs
    from gen/bom_sources.json; README notes parts to check before ordering
    [left-bottom.dxf, left-frame1.dxf, left-frame2.dxf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]
2026-10-04 Align OLEDs, show KiCad-assembled boards in the viewer, add explode gap slider
    - Left OLED moves to the top two rows like the right one; the left board
    grows 4.7 mm on the inner edge to keep the same switch clearance
    - Footprints carry 3D models: kiswitch MX switch / Kailh socket /
    stabilizer, LCSC USB-C and PJ-320D (fetched by gen/fetch_3d.sh into
    tools/), and a simple OLED module model (gen/models3d.py)
    - gen/export_3d.py exports each board as GLB; gen/glb_mesh.py merges,
    dedupes and quantises it into instanced meshes for case/preview/viewer.html
    - Viewer: exploded view gets a layer-gap slider (0-40 mm)
    - BOM/README: both LCSC TRRS jacks verified against the KiCad pad layout
    Co-Au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
    [left-bottom.dxf, left-frame1.dxf, left-frame2.dxf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]
2026-10-05 Move to RP2040, rework OLED/connectors/wheel, add all-printed case and assembly guide
    - MCU: RP2040 + W25Q128JV + 12 MHz crystal + AP2112K 3.3 V LDO on each half;
    QMK config for RP2040 (UF2, PIO serial, I2C1 on GP2/GP3); routing helped by
    MCU escape stubs, TESTEN-to-pad stub, exposed-pad vias and a fan-out ring
    - Boards: top edge +5 mm, inner edges widened; USB-C on the back edge, TRRS
    behind the OLED at the same height on both halves
    - OLED: half-mirror acrylic (2 mm) rounded rectangle centred on the display,
    flush with the plate, held by double-sided tape
    - Wheel: 32 rim teeth + M3 ball plunger for detents; removable corner cap so
    the printed tray can be assembled; magnet shown i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
    [left-bottom.dxf, left-detent.stl, left-frame1.dxf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]
2026-10-05 Fix QMK definition for current qmk_firmware; refresh README renders
    - keyboard.json: non-empty url (QMK skipped the whole file), split sync
    key led_state -> indicators; nrsk.c: 3-argument transaction_rpc_recv
    - Verified: qmk compile -kb nrsk -km default builds nrsk_default.uf2
    with the Arm GNU toolchain (Homebrew's arm-none-eabi-gcc lacks newlib)
    - README renders redrawn for the current design (variant B, slim-head
    screws); older OLED / dial studies marked as historical
    [make_qmk.py]
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2026-10-05 Connector tongues: USB-C / TRRS mouths at the case surface, outline-fit openings
    - PCB outline grows a 12 mm tongue under each connector into the case wall;
    the connector mouth sits 0.8 mm inside the outer surface (gen/make_pcb.py)
    - Case: openings are just the connector outline + 0.2 mm (rounded slot for
    USB-C, round hole for TRRS); printed tray gets removable port caps over
    the tongues, acrylic frames are notched (gen/make_case.py)
    - Port-opening study renders (gen/port_variants.py, docs/img/ports-compare.jpg)
    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
    [left-bottom.dxf, left-current-bore.stl, left-current-case.stl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]
2026-10-05 Plate fastening: one tray for A and B; A screws from the top, B from below
    - Tray wall gets a vertical screw hole, a pocket at the top (B plate boss)
    and a hex nut trap under it (A); bottom counterbore for B
    - A (acrylic plate): M2 x 6 slim-head screws from the top into nuts in the
    trap; B (printed plate): bosses with heat-set inserts, M2 x 12 from the
    tray bottom so the plate top is clean; acrylic stack: M2 x 20 + nut
    - Viewer hardware, assembly guide, BOM (verified sources), README and
    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
    [left-plate.stl, left-tray.stl, left-wheel-cap.stl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]
2026-10-05 TRRS on the top edge next to USB-C; rounded tongues; B lid fillet; keycap legends
    - Both connectors on the back edge (TRRS 17 mm from the inner edge, USB-C 18 mm further out); boards re-routed
    - Tongue tips R2.5, roots R1.5 on Edge.Cuts
    - Shared port cap when the two ports sit close together
    - All-printed plate: R1 on the top outer edge
    - Blender renders: keycap legends; refreshed A/B, ports and wheel images
    [left-bottom.dxf, left-frame1.dxf, left-frame2.dxf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]
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2026-10-06 Port tunnels instead of a port cap: the board slides in tongue-first
    - Printed tray: USB-C / TRRS sit in closed tunnels with 2 mm headroom over the tongue
    (1.2 mm roof); the board goes in front edge raised, 2 mm high, slides 8 mm back, then drops
    onto the bosses. Port caps removed (STL, viewer, renders, BOM)
    - Check: tunnel roof >= 0.6 mm (thinnest under the OLED cover pocket)
    - Assembly guide: board step split into slide-in (animated) and screwing
    - gen/port_slide.py: section figure of the three poses -> docs/img/port-slide.png
    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
    [left-port-caps.stl, left-tray.stl, nrsk-bom.csv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]
2026-10-10 Spec: thumbwheel read by an Alps EC05E1220401 instead of AS5600 + magnet + plunger - docs/specs/thumbwheel-encoder.md: what / why / how / alternatives / 9 work steps - Study geometry (gen/encoder_stu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
    [left-current-cap-cut.stl, left-current-cap.stl, left-current-magnet-cut.stl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]
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2026-10-10 Schematic: thumbwheel encoder ENC1 on GP19 / GP20 instead of the AS5600 (spec step 2) - ENC1 (Device:RotaryEncoder, nrsk:Alps_EC05E1220401): A -> ENC_A -> GP19, B -> ENC_B -> GP20, C -> GND; RP2040 i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
    [nrsk-left.kicad_sch, nrsk-right.kicad_sch]
2026-10-10 PCB: thumbwheel encoder on the back at the wheel axis, boards re-routed (spec step 3) - ENC1 on the back, rotor on the wheel axis (where U3 was), terminals toward the board inside; C9 / C10 gone from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
    [nrsk-left-bom.csv, nrsk-left.kicad_pcb, nrsk-right-bom.csv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]
2026-10-10 Case: wheel drives the encoder through a hex pin; plunger and magnet gone (spec step 4) - Wheel: magnet pocket removed; hub lowered by 0.4 mm within r 6.0 under the encoder; hex pin 1.66 mm A/F (cham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
    [left-bottom.dxf, left-detent.stl, left-tray.stl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]
2026-10-10 Firmware: thumbwheels on QMK's encoder feature instead of the AS5600 reader (spec step 5) - keyboard.json: features.encoder, encoder.rotary and split.encoder.right.rotary on GP19 / GP20 (A and B swap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
    [layout.py, make_qmk.py]
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2026-10-10 BOM: LCSC first wherever LCSC has the part (spec step 8) - Spec: new step 8 (LCSC sourcing, requested during the work); README is step 9, hardware test step 10. Also notes the 0.3 mm pin-to-encoder g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
    [nrsk-bom.csv]
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2026-10-10 JLCPCB assembly files (BOM + CPL) for both halves; 27 ohm resistor with JLC stock - gen/make_jlc.py -> fab/<side>/nrsk-<side>-jlc-bom.csv and -jlc-cpl.csv: every part with an LCSC number except the h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
    [nrsk-bom.csv, nrsk-left-jlc-bom.csv, nrsk-right-jlc-bom.csv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]
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2026-10-10 Board top edge +1 mm so the left Esc switch is no longer turned 180 deg
    - TOP = MARGIN + 6.0 (was + 5.0), both halves, so they stay the same height. The wheel is
    placed from the corner, so it and its encoder move up 1 mm with the edge
    - The Esc socket overlapped the encoder keep-out by 0.43 mm; it now clears it by 0.575 mm
    (1.075 mm between courtyards), so on_encoder() finds no key and every switch faces north.
    Checked on the generated boards: 0 of 44 / 48 switch footprints rotated (was 1 on the left)
    - Board 172.6 / 199.6 x 126.3 mm, case 189.6 / 216.6 x 143.3 mm (each 1 mm taller)
    - ./build.sh rerun: boards rerouted (0 unconnected), DRC 8 per side (5 silk at the connector
    mouths, 3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
    [left-bottom.dxf, left-frame1.dxf, left-frame2.dxf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]
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2026-10-10 README: both boards, front and back, in a 2 x 2 table
    - Adds the left board's back (docs/img/left-bottom.png, already generated by doc_images.sh);
    until now only the right back was shown
    - Notes that the back views are seen from below, so left and right appear swapped
2026-10-10 Right OLED turned like the left (header down); OLED pins fixed in the README
    - The right OLED sat at 270 deg and the left at 90 deg, while the firmware uses one rotation
    (OLED_ROTATION_270) for both: one of the two displays would have been upside down. The right
    is now 90 deg too (header at the bottom); the module centre, and so the cover and the case,
    stay where they were
    - case_data.json carries the OLED rotation; render_blender.py draws the glass from it instead of
    assuming the header end by side
    - The MCU parts stay where they were placed by their pins. Mirroring the left cluster onto the
    right was tried: the right sockets are not mirrored and one (SW16) takes the room of the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
    [nrsk-left.kicad_pcb, nrsk-right.kicad_pcb, right-bottom.dxf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]
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2026-10-11 README: DRC / ERC results after the GND pour; pre-order checks for JLCPCB
    - DRC re-run on both boards with KiCad 10.0.6 (2026-10-11): 5 silk-to-edge warnings per
    side (J1 x3, J2 x2), 0 unconnected pads, 0 schematic parity issues; ERC 0 on both.
    The reports match the committed left/drc.rpt and right/drc.rpt except the timestamp,
    so fab/ is built from the current boards
    - RP2040 note now points to JLCPCB assembly and docs/ordering.md
    - New item: check the USB-C (J2) orientation in the JLC placement preview (rotation
    correction not yet confirmed on a real assembly) and the encoder stock right before ordering
    - textlint 0 on README.md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
2026-10-11 Docs: pre-order checklist on one page (docs/pre-order-checklist.md)
    - What to check before ordering one keyboard: the DRC / ERC results (2026-10-11), what to
    look at on the JLCPCB order page per side (USB-C orientation, encoder stock, pin-1 marks),
    the five risks that only real parts can settle (hot-swap footprint, USB-C rotation, LCSC
    OLED, hex pin fit, firmware) with what can be done before ordering, the two-stage order
    (boards, parts and keycaps first; acrylic and case screws after the boards are checked),
    and the quantity checklist
    - README links it from the BOM section and the file tree (file tree column realigned)
    - textlint 0 on the new file and README.md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
2026-10-11 Orbit renders of A and B from 15 angles, with a review page on GitHub Pages
    gen/render_views.sh renders both case variants from 8 azimuths at 30°, straight down,
    from above (60°) and low (10°) into docs/img/views/; gen/views_page.py builds docs/views.html
    (azimuth/elevation picker, drag to turn, A | B side by side, contact sheet, close-ups).
    Orbit views swap the cyclorama for a shadow-catcher floor so every side has a clean backdrop.
    The Pages workflow now publishes views.html and the images it shows.
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2026-10-11 Split link over USB-C instead of TRRS, so both port openings line up
    The TRRS jack (PJ-320D) hung 5.0 mm under the PCB with its axis 2.5 mm down,
    while the USB-C shell's axis is 1.63 mm down, so the two openings in the back
    wall sat at different heights. The link now uses a second HRO TYPE-C-31-M-12:
    same part, same height, same rounded slot.
    - J1 is a USB-C receptacle: VBUS = VCC, D+ (A6/B6) = DATA (GP1), GND; D- and
    CC open, so a host or charger plugged in by mistake keeps VBUS off.
    - PCB / case / JLC / BOM generators: the 'trrs' connector kind becomes 'link'
    and is handled like the host USB-C; PJ-320D footprint, model and JLC fix go.
    - BOM: 4 USB-C receptacles, a C-C data cable for t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
2026-10-11 Drum dial step 5: QMK reads the drum as the right half's second encoder
    keyboard.json gets the drum (GP22 / GP23, resolution 2: one EC10E1220505 click is half an A/B cycle) as a
    second rotary under split.encoder.right, and mousekey on. encoder_update_user() sends the mouse wheel for
    index 2: up / down on layer 0, left / right on layer 1 (rolled away from the typist = up). The two
    thumbwheels keep indices 0 and 1 and their keys.
    Checked: qmk lint (only the existing missing-license-header notes) and qmk generate-config-h ->
    ENCODER_A_PINS_RIGHT { GP20, GP22 }, ENCODER_B_PINS_RIGHT { GP19, GP23 }, ENCODER_RESOLUTIONS_RIGHT { 4, 2 }.
    Not compiled: the local Homebrew arm-none-eabi-gcc has no new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
2026-10-11 Drum dial step 7: assembly guide and 3D viewer show the drum dial
    The viewer adds the bearing block, drum and bezel on the right half (the KiCad board export carries the
    EC10E as ENC2, grouped as 'drumenc'); they rise in the exploded view and follow the renamed "ダイヤル"
    toggle with the thumbwheels. The assembly guide gets three right-half steps: solder the EC10E, fit the block
    and snap the drum in after the board is fixed, and press the bezel in after the plate.
    Checked: served case/preview locally; on the right half, step "ドラムと軸受けブロック" shows the knurled
    drum between the encoder and the block at the top right.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
2026-10-11 Re-render the README images after the column removal (with the drum dial)
    render_all.sh shots (hero, detail, OLED, both wheels, drum) and render_compare.sh (A / B sheet, ports,
    board slide-in section) for the narrower halves without the blank inner column, the even band round the OLED
    cover, the USB-C split link from main and the drum dial. render_compare.sh ran at 1200 px / 48 samples to keep
    it short; FINAL-quality renders and the views.html orbit / close-up sets (render_views.sh, render_details.sh)
    are still from before this change. The OLED height study (oled_study.sh) is a record of the earlier board and
    no longer builds on the narrower left half, so its images are left as they were.
    C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
2026-10-11 OLED cover: 5.5 mm plate band, R7 on all four corners, display centred
    The half-mirror cover now has the same R7 on all four corners. The corner facing the case corner stays
    concentric with the case outline (R12.5 - band), so the band keeps its width round it; that sets the band to
    5.5 mm (top, inner edge, row 0-1 keycaps), up from 3.5. The left board and case widen by 4 mm; the right
    board keeps its size (its cover sits in the notch above the Y key).
    The cover's bottom is no longer set by the row-2 keycap line: it runs 1.5 mm past the module's header end
    (COVER_END), and the OLED sits where its display glass (3 mm toward the module's top) is the cover's centre
    (OLED_Y 14.95). On the right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
2026-10-11 Case viewer: spec panel for the drum dial and the R7 OLED cover; fix variant A's plate fixing
    The spec rows were hand-written and still described the cover as a plain rounded rectangle, had no drum
    dial, and said variant A's acrylic plate is held by heat-set inserts (those are B's; A uses slim-head M2
    screws from the top into nuts in the wall). The OLED row now gives the corner radius and band from
    make_case (R7, 5.5 mm), and each variant gets a drum row.
    Checked: served case/preview locally; the viewer loads both halves at 178.1 / 197.5 x 143.3 mm with the drum
    and the new spec rows.
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2026-10-11 Drum dial: widen the drum to 1.25 u (23.8 mm), bezel centred on Backspace
    The free 2 u above Backspace now holds the widest drum it can: with the encoder (6.1 mm) and the
    bearing block (3 mm) beside it, 1.5 u would need 38.5 mm and the encoder hood would sit on the F12
    switch. The drum width lives in gen/footprints.py (DRUM_W) and the PCB, the case and the renders read it.
    The drum sits 1.75 mm right of Backspace's centre so the bezel (longer hood on the encoder side) is
    centred on the key; the bezel's snap hooks move to the middle of the drum.
    Right board re-routed (0 unconnected, 0 parity issues); case checks pass. README, spec and BOM updated.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
2026-10-11 Drum dial: hoods of equal size, drum narrowed to 21.6 mm
    The block hood is now as long as the encoder hood (7.6 mm, solid beyond the block), so both hoods
    match in length, width (12.4 mm), height (11.9 mm) and radii. The longer bezel would have run 1 mm
    past the right case wall, so the drum goes from 23.8 to 21.6 mm: the widest that keeps the ledge
    under the plate 0.2 mm inside the wall. The encoder stays put (dx fixed at -10.55, the most the plate
    web to the F12 cut-out allows) and the bearing block moves 2.2 mm left, so the bezel's centre sits
    0.7 mm right of Backspace's.
    Right board rebuilt: 0 unconnected, 0 parity issues; DRC shows only the 4 existing silk-edge warnings
    on J1/J2. The to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
2026-10-11 Move the RP2040 and its support parts to the front, visible through the clear plate
    - RP2040, flash, crystal, LDO, decoupling caps and resistors on the front, in the
    key-free strip along the inner edge (clear of every keycap and the OLED cover);
    USB-C and its protection parts, reset switch and BOOTSEL pad stay on the back
    - RP2040 fixed with pin 1 top-left so its Raspberry Pi logo reads upright
    (datasheet Figure 168); make_pcb asserts the orientation
    - Left half: pin row 1-14 faces the keys, so it is fanned out to 1 mm pitch and
    the matrix rows are routed by make_pcb; Freerouting does the rest
    - build.sh retries routing until 0 unconnected and 0 DRC violations
    - USB-C footprint copy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
2026-10-12 views.html: board parts visible through the clear plate, brighter
    The acrylic variant now carries KiCad's assembled boards (build/3d/<side>-pcba.glb from
    gen/export_3d.py): parts below the board's top face and the encoders are left out, the
    flat faces merged, and KiCad's see-through mask and all-metal parts get the scene's
    materials. In the path tracer the acrylic and the half mirror no longer block shadow
    rays, so the board under the plate is lit instead of black. Exposure 0.16 -> 0.22.
2026-10-12 firmware: add qmk compile script, document Arm toolchain setup
    Homebrew's arm-none-eabi-gcc lacks newlib, so qmk compile failed to link.
    compile.sh syncs keyboards/nrsk into qmk_firmware, uses the Arm GNU
    Toolchain (~/.local/opt, /Applications or $ARM_TOOLCHAIN), and copies
    the .uf2 to firmware/qmk/build/.
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2026-10-12 Back to single-sided assembly; RP2040 window with a clear acrylic lid in the case floor
    - PCB: the RP2040 and its support parts go back to the back side (reverts the placement of
    a6faa8b): every assembled part is on the back again, so JLC assembles one side.
    make_jlc refuses top-side parts again; the front assembly drawing is gone. Kept from
    a6faa8b: the routing retry until 0 unconnected and 0 DRC violations, and the USB-C
    footprint with its outline on Fab
    - make_pcb writes the RP2040 and flash courtyards to case_data.json (mcu)
    - Case: a rounded window in the tray floor / acrylic bottom plate, 2 mm round the RP2040
    and flash, R2. Clear 1.5 mm acrylic lid (case/laser/<side>-mcu-lid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
2026-10-12 make_case / compile.sh: room for a second, smaller board
    - make_case.py: the OLED, its cover and the reset hole are optional (no 'oled' / 'reset' in case_data);
    a connector may give its own height ('z'), opening width and an open-top tunnel, and its opening may
    sit on the inner edge as well as the top edge; plate holes for tall tact switches ('buttons') and
    areas the printed plate's web keeps off ('web_keep'); main() split into write_half(), which can leave
    out the wheel / drum parts and the laser-cut layers; check() split into check_oled / check_wheel /
    check_closed
    - compile.sh: optional second argument for the keyboard (default nrsk)
    - Checked: make_case.py writes byte-identical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
2026-10-12 Encoder test board: hand-rerouted wheel traces, gerbers re-exported
    The thumbwheel encoder's tracks were rerouted by hand in KiCad and the GND
    zones refilled; DRC is clean (0 violations, 0 unconnected, 0 parity issues).
    The gerber zip is re-exported with the same layers and drill options as
    build_enctest.sh. Running build_enctest.sh again regenerates the board and
    overwrites this routing.
    The .kicad_pro changes are KiCad 10 adding its new default ERC settings on save.
    KiCad's local .history/ backups are now ignored.
2026-10-12 Encoder test board: drop the GND stitching via at the top-left edge
    The stitching via between the RP2040-Zero header's pins 1 and 2 had only
    0.37 mm of copper to the board edge (DRC minimum 0.3 mm), too tight for the
    outline routing tolerance. GND keeps plenty of other vias. Zones refilled,
    DRC clean, gerbers re-exported.
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2026-10-12 Encoder test board: JLCPCB BOM and CPL for every part
    make_jlc.py now handles front-side parts (rotation = KiCad rotation + correction)
    and lists all LCSC parts for enctest: ENC2 (EC10E, C160888) and the tact switch
    SW1 (Omron B3F-1072, C87121) join ENC1. EasyEDA origin/rotation corrections for
    Alps_EC10E and SW_PUSH_6mm_H9.5mm were checked by overlaying the EasyEDA pads on
    the placed KiCad pads (all within 0.02 mm). The halves' output is unchanged.
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
